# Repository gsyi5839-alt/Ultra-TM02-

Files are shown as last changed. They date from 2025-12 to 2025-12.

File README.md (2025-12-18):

# Ultra-TM02 超低温温度测量模块

## 📋 项目简介

Ultra-TM02是一款高精度超低温温度测量模块，专门用于二极管式温度探头的超低温测量，支持用户自定义探头分度表。

## 🎯 主要技术指标

| 参数 | 规格 |
|---|---|
| 温度测量范围 | 1.4K ~ 500K (-271.75℃ ~ 226.85℃) |
| 显示分辨率 | 0.001℃ |
| 最大允许误差 | 低温段 ±1℃，高温段 ±2℃ |
| ADC精度 | 24位 |
| 内部电流源精度 | ≤0.05% |
| 激励电流 | 10μA / 17μA 可选 |
| 输出形式 | 4-20mA（两线制） |
| 供电电压 | 24V DC |
| 显示屏 | 3.5寸LCD串口屏 |

## 📁 项目结构

```
Ultra-TM02/
├── Ultra_TM02/              # STM32固件源码
│   ├── App/                 # 应用层（温度测量、通讯、参数）
│   ├── Service/             # 服务层（ADC、DAC、LCD、USB）
│   ├── BSP/                 # 板级支持包（GPIO、SPI、UART、Flash）
│   └── Core/                # 主程序和HAL配置
├── TempDownloader/          # 上位机软件（Python/PyQt5）
│   ├── src/                 # 源代码
│   │   ├── ui/              # 用户界面
│   │   ├── protocol/        # 通讯协议
│   │   └── utils/           # 工具模块
│   └── resources/           # 资源文件
├── Gerber_PCB1/             # PCB Gerber文件
├── Schematics/              # 原理图
├── 软件开发/                 # 软件设计文档
├── 硬件设计/                 # 硬件设计文档
└── 配件采购/                 # 配件采购清单
```

## 🔧 硬件规格

### MCU
- **型号**: STM32F411RET6
- **内核**: ARM Cortex-M4
- **主频**: 100MHz
- **Flash**: 512KB
- **RAM**: 128KB

### 外设
- **SPI1**: ADC/DAC通讯 (12.5MHz)
- **USART6**: LCD串口屏通讯 (115200bps)
- **USB**: CDC虚拟串口
- **GPIO**: 片选、LED、DRDY等

## 💻 软件架构

### 固件分层架构
```
┌─────────────────────────────────────────┐
│              应用层 (App)                │
│  温度测量 | 数据处理 | 参数管理 | 通讯    │
├─────────────────────────────────────────┤
│             服务层 (Service)             │
│   ADC服务 | DAC服务 | LCD服务 | USB服务  │
├─────────────────────────────────────────┤
│              驱动层 (BSP)                │
│  SPI驱动 | UART驱动 | GPIO驱动 | Flash   │
├─────────────────────────────────────────┤
│             硬件层 (HAL)                 │
│           STM32 HAL / LL 库              │
└─────────────────────────────────────────┘
```

### 上位机软件
- **语言**: Python 3.x
- **GUI框架**: PyQt5
- **功能**: 设备连接、参数设置、数据采集、分度表下载

## 🚀 快速开始

### 固件编译
1. 安装 STM32CubeIDE
2. 打开 `Ultra_TM02/Ultra_TM02.ioc`
3. 点击 Project → Build All

### 上位机运行
```bash
cd TempDownloader
pip install -r requirements.txt
python main.py
```

## 📊 开发进度

| 模块 | 完成度 |
|---|---|
| 硬件原理图设计 | ✅ 100% |
| PCB设计+制作 | ✅ 100% |
| STM32固件开发 | ✅ 100% |
| 上位机软件开发 | ✅ 100% |
| 系统联调测试 | ⏳ 进行中 |

## 📄 文档

- [软件开发设计文档](软件开发/01_软件开发设计文档.md)
- [STM32工程配置指南](软件开发/02_STM32工程配置指南.md)
- [通讯协议详细设计](软件开发/03_通讯协议详细设计.md)
- [温度测量算法设计](软件开发/04_温度测量算法设计.md)
- [开发进度文档](软件开发/05_开发进度文档.md)
- [原理图设计文档](硬件设计/超低温温度测量模块_原理图设计文档.md)

## 📜 License

本项目仅供学习和研究使用。

## 📧 联系方式

如有问题，请提交 Issue。

---
*版本: V1.0*
*更新日期: 2025年12月18日*

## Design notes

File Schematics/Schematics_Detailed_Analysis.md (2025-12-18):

# 超低温温度测量模块 - 原理图详细分析文档

**项目名称：** 超低温温度测量模块
**主控芯片：** STM32F411RET6
**原理图版本：** V1.0
**设计单位：** 嘉立创EDA
**更新日期：** 2025-09-26
**图纸数量：** 4页（P1-P4）

---

## 📑 目录

1. [第一页：超低温温度测量模块体](#第一页超低温温度测量模块体-p1)
2. [第二页：STM32主控电路](#第二页stm32主控电路-p2)
3. [第三页：电源管理电路](#第三页电源管理电路-p3)
4. [第四页：DAC输出与隔离电路](#第四页dac输出与隔离电路-p4)

---

## 第一页：超低温温度测量模块体 (P1)

### 1.1 页面概览

**原理图标题：** Schematic6 - P1
**功能模块：** 超低温温度测量模块体
**更新日期：** 2025-09-26

### 1.2 主要电路模块

#### 1.2.1 ADC采集电路（左上区域）

**核心芯片：** 高精度ADC芯片（U71/U72）

**电路组成：**
```
ADC通道1：
- 输入滤波电容：C92, C93, C96, C97
- 参考电压电路
- SPI通讯接口：ADC1_CS, ADC_SCK, ADC_MOSI
- 模拟地：AGND
```

**功能说明：**
- 用于采集探头温度信号
- 高精度24位ADC转换
- SPI接口与MCU通讯
- 差分输入方式，抗干扰能力强

**关键元件：**
- 去耦电容：100nF（C92, C93）
- 滤波电容：10uF（C96, C97）
- 参考电压稳定电路

#### 1.2.2 DAC输出电路（中上区域）

**核心芯片：** 高精度DAC芯片

**电路组成：**
```
DAC通道：
- 数字接口：DAC1_CS, DAC_SCK, DAC_MOSI, DAC_LOAD
- 输出滤波电路
- 运算放大器
- 电压到电流转换电路
```

**功能说明：**
- 将数字信号转换为模拟电压
- 输出电压范围可调
- 通过运放进行缓冲和放大
- 为后级电流输出提供基准

**关键元件：**
- DAC芯片（高精度16位）
- 运算放大器（低噪声）
- 基准电压源

#### 1.2.3 V/I转换电路（右上区域）

**功能：** 电压到4-20mA电流转换

**电路组成：**
```
V/I转换电路：
- 运算放大器
- 精密取样电阻
- 功率晶体管
- 电流反馈电路
```

**输出规格：**
- 输出电流：4-20mA
- 负载能力：最大500Ω
- 精度：±0.1%
- 线性度：优于0.05%

**关键元件：**
- 高精度取样电阻：250Ω
- 运算放大器（低偏置）
- 功率晶体管

#### 1.2.4 隔离电源电路（左下区域）

**核心芯片：** DC-DC隔离模块

**电路组成：**
```
隔离电源：
- 输入：+24V
- 输出1：+5VD（数字隔离）
- 输出2：+5VA（模拟隔离）
- 反馈控制电路
```

**功能说明：**
- 实现数字地和模拟地隔离
- 防止地回路干扰
- 提高测量精度
- 保护后级电路

**关键元件：**
- DC-DC隔离模块
- 输入滤波电容
- 输出滤波电容

#### 1.2.5 信号调理电路（右下区域）

**功能：** 探头信号放大和滤波

**电路组成：**
```
信号调理：
- 前置放大器
- 低通滤波器
- 共模抑制电路
- 保护电路
```

**技术参数：**
- 增益：可调（1-1000倍）
- 带宽：DC-100Hz
- 共模抑制比：>100dB
- 输入阻抗：>1MΩ

---

## 第二页：STM32主控电路 (P2)

### 2.1 页面概览

**原理图标题：** Schematic6 - P2
**功能模块：** STM32主控电路
**更新日期：** 2025-09-26

### 2.2 核心芯片：STM32F411RET6 (U22)

**芯片规格：**
- 型号：STM32F411RET6
- 封装：LQFP-64
- 主频：100MHz
- Flash：512KB
- RAM：128KB
- 工作电压：3.3V

**引脚分配：**

#### 2.2.1 电源引脚

```
VDD引脚（3.3V）：
- VDD_1, VDD_2, VDD_3, VDD_4（多个VDD引脚）
- VDDA（模拟电源）
- VBAT（备份电源）

GND引脚：
- VSS_1, VSS_2, VSS_3, VSS_4（多个地引脚）
- VSSA（模拟地）
```

**去耦电容配置：**
- C58, C59, C60, C61, C62：100nF（靠近每个VDD引脚）
- C68：10uF（大容量去耦）
- C76：1uF（中频去耦）

#### 2.2.2 晶振电路

**主晶振 (OSC1)：**
```
型号：12MHz晶振
连接引脚：
- PH0-OSC_IN（引脚5）
- PH1-OSC_OUT（引脚6）

外围元件：
- C123：20pF（负载电容1）
- DGND
- 12MHz标识
```

**功能：**
- 提供系统时钟源
- PLL倍频到100MHz
- 高精度时钟基准

#### 2.2.3 复位电路

**复位方式：** 外部复位 + 内部复位

```
复位引脚：NRST（引脚7）
外围电路：
- 复位按钮
- 上拉电阻：10kΩ
- 滤波电容：100nF
```

#### 2.2.4 调试接口

**SWD调试接口 (H1)：**

```
引脚定义（P2254V-1x04P）：
1. 3V3      - 电源（红色）
2. DGND     - 地（黑色）
3. SWDIO    - 数据线（黄色）
4. JTCK-SWCLK - 时钟线（绿色）

连接芯片引脚：
- SWDIO  → PA13（引脚46）
- SWCLK  → PA14（引脚49）
```

**功能：**
- 程序下载
- 在线调试
- 固件升级
- 芯片擦除

#### 2.2.5 USB接口电路

**USB TypeC接口 (LCM2)：**

```
USB信号：
- USB_PA (USB D+ after filter)
- USB_NA (USB D- after filter)
- USB_P (USB D+ to MCU)
- USB_N (USB D- to MCU)

连接芯片引脚：
- USB_P → PA12（引脚45）
- USB_N → PA11（引脚44）

外围电路：
- ESD保护二极管
- USB滤波电感：L29, L25
- 差分阻抗匹配：R95, R96
- 上拉电阻：R97 (1.5kΩ to 3V3)
```

**ESD保护：**
- USB_PA/NA经过ESD保护二极管
- 连接到USB_P/N
- 保护MCU免受静电损伤

#### 2.2.6 LCD显示接口

**FPC软排线接口 (FPC1)：**

```
引脚定义（6芯FPC）：
1. DGND         - 地
2. NET_1        - 数据线1
3. NET_2        - 数据线2
4. +5VD         - 电源5V
5. DGND（屏蔽）  - 地屏蔽层
6. DGND（屏蔽）  - 地屏蔽层

LCD通讯接口：
- IO_USART6_RX  → LCD数据接收
- IO_USART6_TX  → LCD数据发送
- 串口通讯，波特率可配置
```

#### 2.2.7 SPI通讯引脚

**SPI1接口（用于DAC/ADC）：**

```
DAC1控制：
- DAC1_CS    → 片选信号
- DAC1_SCK   → 时钟信号
- DAC1_MOSI  → 数据输出
- IO_DAC1_CS → 光耦隔离后片选

DAC2控制：
- DAC2_CS    → 片选信号
- DAC2_SCK   → 时钟信号
- DAC2_MOSI  → 数据输出
- DAC2_LOAD  → 加载信号
- IO_DAC2_CS → 光耦隔离后片选

ADC1控制：
- ADC1_CS    → 片选信号
- IO_ADC1_CS → 光耦隔离后片选
```

**光耦隔离说明：**
- 数字信号通过光耦隔离
- 实现数字地(DGND)和模拟地(AGND)隔离
- 防止数字噪声干扰模拟测量

#### 2.2.8 GPIO分配

**主要GPIO功能：**

```
PORT A：
- PA0-PA7：ADC输入/通用IO
- PA8-PA10：通用IO
- PA11-PA12：USB通讯
- PA13-PA14：SWD调试
- PA15：通用IO

PORT B：
- PB0-PB15：通用IO/SPI/I2C/定时器

PORT C：
- PC0-PC15：通用IO/ADC输入

PORT D：
- PD0-PD15：通用IO

PORT E：
- PE0-PE15：通用IO

PORT H：
- PH0-PH1：晶振
```

#### 2.2.9 电源去耦

**去耦电容布局：**

```
顶层去耦电容（靠近VDD引脚）：
- C58：100nF（VDD_1附近）
- C59：100nF（VDD_2附近）
- C60：100nF（VDD_3附近）
- C61：100nF（VDD_4附近）
- C62：100nF（VDDA附近）

底层去耦电容：
- C63：100nF（VSS附近）
- C76：1uF（大电容）
- C68：10uF（更大电容）
```

**去耦策略：**
- 100nF高频去耦（靠近每个VDD）
- 1uF中频去耦
- 10uF低频去耦
- 多点并联降低ESR和ESL

#### 2.2.10 LED指示灯

**LED1电路：**

```
型号：KT-0805G（绿色LED）
连接：
- 正极 → 3V3
- 负极 → R120 → MCU GPIO

电流限制电阻：
- R120：1kΩ（限流约2-3mA）

功能：
- 电源指示
- 运行状态指示
- 通讯状态指示（可编程）
```

### 2.3 电源供电

**3V3电源网络：**

```
输入：+5VD（数字5V）
稳压器：AMS1117-3.3（可能）
输出：3V3（MCU供电）

滤波电容：
- 输入：C35（10uF）
- 输出：C58-C62（100nF × 5）
        C68（10uF）
```

---

## 第三页：电源管理电路 (P3)

### 3.1 页面概览

**原理图标题：** Schematic6 - P3
**功能模块：** 电源管理电路
**更新日期：** 2025-09-26

### 3.2 主电源输入

#### 3.2.1 24V输入电路 (CN14)

**接线端子：**
```
型号：XH-2A（2位端子）
引脚定义：
1. IX1K_1X  - 正极（24V输入）
2. 电源地   - 负极（DGND）

输入保护：
- 反接保护二极管
- 过压保护
- 输入滤波电容
```

**24V分配：**
```
+24V →
  ├─ DC-DC转换器1 (U23) → +5VD, +9VD
  ├─ DC-DC转换器2 (U63) → +9VA
  └─ DC-DC转换器3 (U67) → +9VX
```

### 3.3 隔离DC-DC电源模块

#### 3.3.1 数字电源模块 (U23)

**型号：** DC-DC隔离模块（+24V → +5V/+9V）

```
输入引脚：
- VIN：+24V（引脚1,2）
- GND：DGND（引脚3,4）

输出：
- +5VD：5V数字电源
- +9VD：9V数字电源（可选）

外围电路：
- 输入电感：L30 (4.7uH)
- 输入电容：C77 (10uF)
- 输出电容：C78, C79 (100nF + 10uF)
```

**功能：**
- 为STM32和数字电路供电
- 隔离保护
- 纹波抑制

#### 3.3.2 模拟电源模块1 (U63)

**型号：** DC-DC隔离模块（+24V → +9VA）

```
输入：
- +24V经过L31电感滤波
- DGND

输出：
- +9VA：9V模拟电源
- AGND：模拟地

外围电路：
- 输入电感：L31 (4.7uH)
- 输入电容：C80 (10uF)
- 输出电容：C81, C82 (100nF + 10uF)
```

**功能：**
- 为ADC/DAC模拟电路供电
- 低纹波输出（<10mV）
- 与数字电源隔离

#### 3.3.3 隔离电源模块2 (U67)

**型号：** DC-DC隔离模块（+24V → +9VX）

```
输入：
- +24V经过L32电感滤波
- DGND

输出：
- +9VX：9V隔离电源
- GNDX：隔离地

外围电路：
- 输入电感：L32 (4.7uH)
- 输入电容：C86 (10uF)
- 输出电容：C87, C88 (100nF + 10uF)
```

**功能：**
- 为4-20mA输出电路供电
- 完全隔离（与DGND和AGND都隔离）
- 防止地回路

### 3.4 线性稳压器

#### 3.4.1 +5VD → +3.3V稳压 (U62)

**稳压器：** AMS1117-3.3 或 LD1117S33TR

```
输入：+5VD
输出：3V3（3.3V）
最大电流：800mA

外围电路：
- 输入电容：C121 (10uF)
- 输出电容：C122, C123 (10uF + 100nF)
- 热保护：内置
```

**负载分配：**
- STM32主控：~100mA
- 外围逻辑电路：~50mA
- 总负载：<200mA

#### 3.4.2 +9VA → +6.5VA稳压 (U65)

**稳压器：** LD1117S50TR（5V稳压器 + 分压）

```
输入：+9VA
输出：6.5VA（用于基准电压）

外围电路：
- 输入电容：C80 (10uF)
- 输出电容：C83 (100nF)
- 分压电阻：R130 (精密电阻)
```

**功能：**
- 提供ADC/DAC基准电压
- 高稳定度（±0.01%）
- 低温漂（<10ppm/℃）

#### 3.4.3 +9VX → +6.5VX稳压 (U69)

**稳压器：** LD1117S50TR（5V稳压器 + 分压）

```
输入：+9VX
输出：6.5VX（用于隔离电路基准）

外围电路：
- 输入电容：C86 (10uF)
- 输出电容：C89 (100nF)
- 分压电阻：R133 (精密电阻)
```

**功能：**
- 为隔离输出电路提供基准
- 与主电路完全隔离

#### 3.4.4 +9VA → +5VA稳压 (U85)

**稳压器：** LM78L05（5V线性稳压器）

```
输入：+9VA
输出：5VA（5V模拟电源）

外围电路：
- 输入电容：C125 (10uF)
- 输出电容：C126 (100uF)
```

**负载：**
- 光耦隔离器
- 运算放大器
- 模拟开关

#### 3.4.5 +9VX → +5VX稳压 (U86)

**稳压器：** LM78L05（5V线性稳压器）

```
输入：+9VX
输出：5VX（5V隔离电源）

外围电路：
- 输入电容：C127 (10uF)
- 输出电容：C128 (100uF)
```

**负载：**
- 隔离光耦
- 4-20mA输出电路

### 3.5 电源测试点

**测试点分布：**

```
TP2：+5VD  - 数字5V测试点
TP3：+3V3  - 3.3V测试点
TP4：+6.5VA - 模拟基准电压测试点
TP5：+6.5VX - 隔离基准电压测试点
TP6：DGND  - 数字地测试点
TP7：AGND  - 模拟地测试点
TP8：GNDX  - 隔离地测试点
```

**用途：**
- 电源电压检测
- 故障排查
- 性能测试
- 校准验证

### 3.6 电源指示

**电源指示电路：**

```
+5VD指示：
- LED：可选
- 限流电阻：1kΩ
- 颜色：绿色

+5VA指示：
- LED：可选
- 限流电阻：1kΩ
- 颜色：黄色

+5VX指示：
- LED：可选
- 限流电阻：1kΩ
- 颜色：红色
```

### 3.7 电源时序

**上电时序：**

```
1. +24V输入（0ms）
2. DC-DC启动（1-5ms）
   - U23：+5VD, +9VD
   - U63：+9VA
   - U67：+9VX
3. 线性稳压器启动（6-10ms）
   - U62：3V3
   - U65：6.5VA
   - U69：6.5VX
   - U85：5VA
   - U86：5VX
4. MCU复位释放（>100ms）
5. 系统正常工作
```

**掉电时序：**

```
1. 检测+24V掉电
2. MCU进入掉电保护
3. 保存关键数据
4. 关闭输出
5. 电源下降
```

---

## 第四页：DAC输出与隔离电路 (P4)

### 4.1 页面概览

**原理图标题：** Schematic6 - P4
**功能模块：** DAC输出与隔离电路
**更新日期：** 2025-09-26

### 4.2 DAC2通道与4-20mA输出电路

#### 4.2.1 光耦隔离电路（左上区域）

**隔离芯片：** 高速光耦（可能是6N137或HCPL-2630）

```
输入侧（数字侧，DGND）：
- 信号输入：
  * DAC2_CS   → 光耦1输入
  * DAC2_SCK  → 光耦2输入
  * DAC2_MOSI → 光耦3输入
  * DAC2_LOAD → 光耦4输入
- 电源：3V3
- 地：DGND
- 限流电阻：330Ω

输出侧（隔离侧，GNDX）：
- 信号输出：
  * DAC2_CS_隔离
  * DAC2_SCK_隔离
  * DAC2_MOSI_隔离
  * DAC2_LOAD_隔离
- 电源：5VX
- 地：GNDX
- 上拉电阻：10kΩ
```

**功能：**
- 实现数字信号隔离
- 隔离电压：>2500V
- 传输速率：>1Mbps
- 防止地回路干扰

#### 4.2.2 DAC芯片电路（U79）

**DAC芯片型号：** 可能是DAC8560、DAC8563或AD5541

```
引脚连接：
输入接口（SPI）：
- CS#：片选（来自光耦隔离）
- SCK：时钟（来自光耦隔离）
- SDI：数据输入（来自光耦隔离）
- LDAC#：加载信号（来自光耦隔离）

电源引脚：
- VDD：5VX（隔离5V电源）
- GND：GNDX（隔离地）

输出引脚：
- VOUT：电压输出
- VREF：基准电压输入

外围电路：
- C118：100nF（VDD去耦）
- 基准电压：2.5V或5V
```

**DAC规格：**
- 分辨率：16位
- 建立时间：<10μs
- 输出范围：0-5V或0-10V
- 线性度：±1LSB

#### 4.2.3 V/I转换电路（中间区域）

**核心电路：** 精密V/I转换器

```
电路组成：
- 运算放大器（U79_内部或外部）
- 精密取样电阻：R150 (250Ω, 0.1%)
- 功率晶体管：Q2（可能是2N2219或BC547）
- 反馈电路

工作原理：
1. DAC输出0-5V电压
2. 运放将电压转换为0-20mA电流
3. 取样电阻检测电流
4. 反馈到运放负输入
5. 形成闭环控制

转换公式：
I_out = V_DAC / R_sample × K
其中 K 为放大系数
```

**输出电路：**

```
Q2晶体管电路：
- 基极：运放输出
- 发射极：经R150到GNDX
- 集电极：连接到4-20mA输出

负载能力：
- 最大负载：500Ω
- 工作电压：24V
- 功耗：<1W
```

#### 4.2.4 4-20mA输出保护电路

**保护措施：**

```
1. 过流保护：
   - 限流电阻
   - 保护二极管D7, D8

2. ESD保护：
   - TVS管：保护输出端
   - 箝位二极管

3. 反接保护：
   - 串联二极管D5, D6
   - 防止接线反接损坏

4. 过压保护：
   - 稳压二极管
   - 限制最高电压
```

**输出接口：**

```
CN12：4-20mA输出1
- 引脚1：+24V NC（未连接，标记用）
- 引脚2：GNDX_NC（未连接，标记用）
- 实际输出：ZX3位2-54-4PZ2（4芯接口）

CN13：测试端口
- 引脚1：+24V NC
- 引脚2：测试地_NC
- 实际输出：ZX3位54-2P2Z（2芯接口）

输出电路连接：
- 正极：连接到负载正端
- 负极：通过Q2到GNDX
- 回路：+24V → 负载 → 4-20mA输出 → GNDX
```

#### 4.2.5 测试点电路

**TP10测试点：**

```
位置：4-20mA输出线路上
功能：
- 测量输出电流
- 校准验证
- 故障诊断

测试方法：
- 串联电流表
- 测量电压降（跨R150）
- 计算电流值
```

### 4.3 USB接口电路（下方区域）

#### 4.3.1 USB差分线处理

**USB信号链路：**

```
信号流向：
MCU → USB_PA/USB_NA →
      ESD保护 →
      差分滤波 →
      USB_P/USB_N →
      TypeC接口

差分线处理：
- 阻抗控制：90Ω ±10%
- 等长设计：误差<5mil
- 差分对布线
```

**滤波电路：**

```
USB_PA → R97 → L17U2 → ISB_P
USB_NA → R96 → (共模电感) → ISB_N

滤波元件：
- R97, R96：22Ω（串联阻抗匹配）
- L17U2：共模电感（抑制共模噪声）
- 频率响应：DC-500MHz
```

#### 4.3.2 USB ESD保护

**保护器件：**

```
双向TVS管或ESD保护阵列：
- USB_PA/NA 到地的ESD保护
- 箝位电压：<5.5V
- 峰值功率：>200W
- 电容：<5pF（不影响高速信号）

保护等级：
- IEC 61000-4-2：±8kV接触放电
- IEC 61000-4-4：±2kV快速脉冲
```

#### 4.3.3 USB上拉电阻

**USB识别电路：**

```
R98/R99电阻：
- 阻值：1.5kΩ
- 连接：USB D+ 到 3V3
- 功能：
  * 全速USB设备识别
  * 通知主机设备连接
  * 符合USB2.0规范

工作机制：
1. 设备未连接：D+为低电平
2. 设备连接：D+被上拉到3.3V
3. 主机检测到D+高电平
4. 主机开始枚举设备
```

#### 4.3.4 USB接口定义 (U88)

**TypeC接口：** ZX3位54-4PZ2

```
引脚定义：
1. USB_N   - USB D- 数据线
2. USB_P   - USB D+ 数据线
3. GNDI    - USB地
4. 屏蔽层  - 连接外壳

USB协议：
- USB 2.0 Full Speed（12Mbps）
- CDC类设备（虚拟串口）
- HID类设备（可选）
```

### 4.4 IO隔离电路 (U83)

**光耦隔离芯片：** 8通道光耦阵列

```
输入侧（数字侧）：
- 电源：3V3
- 地：DGND
- 输入信号：
  * IO_DAC2_CS
  * IO_DAC2_MOSI
  * IO_DAC2_SCK
  * IO_DAC2_LOAD
  * （其他控制信号）

输出侧（隔离侧）：
- 电源：5VX
- 地：GNDX
- 输出信号：
  * DAC2_CS（隔离后）
  * DAC2_MOSI（隔离后）
  * DAC2_SCK（隔离后）
  * DAC2_LOAD（隔离后）

电路参数：
- 正向电流：5-10mA
- 电流传输比：50-200%
- 隔离电压：2500V
- 传输延迟：<10μs
```

**功能：**
- 数字信号隔离
- 保护MCU不受高压损坏
- 防止地回路噪声
- 提高系统可靠性

### 4.5 去耦电容布局

**电源去耦：**

```
3V3去耦：
- C120：100nF（高频）
- 靠近光耦和逻辑芯片

5VX去耦：
- C119：100nF（高频）
- C127, C128：10uF（中低频）
- 靠近DAC和V/I转换电路

GNDI去耦：
- C69：100uF（大电容）
- USB接口附近
- 抑制USB通讯噪声
```

---

## 📊 系统级分析

### 5.1 电源架构总览

```
+24V输入
  │
  ├─→ DC-DC(U23) ─→ +5VD ─→ LDO(U62) ─→ 3V3 (STM32, 数字电路)
  │                    │
  │                    └─→ +9VD (备用)
  │
  ├─→ DC-DC(U63) ─→ +9VA ─→ LDO(U65) ─→ 6.5VA (ADC/DAC基准)
  │                    │
  │                    └─→ LDO(U85) ─→ 5VA (模拟电路)
  │
  └─→ DC-DC(U67) ─→ +9VX ─→ LDO(U69) ─→ 6.5VX (隔离基准)
                       │
                       └─→ LDO(U86) ─→ 5VX (隔离电路)

地系统：
- DGND：数字地（STM32, USB, LCD）
- AGND：模拟地（ADC, DAC, 运放）
- GNDX：隔离地（4-20mA输出）
- GNDI：USB接口地
```

### 5.2 信号隔离架构

```
数字侧（DGND）          光耦隔离         隔离侧（GNDX）
─────────────────    ─────────────    ─────────────────
STM32 GPIO                              DAC2芯片
  ├─ DAC2_CS      →  光耦1  →  DAC2_CS_ISO
  ├─ DAC2_SCK     →  光耦2  →  DAC2_SCK_ISO
  ├─ DAC2_MOSI    →  光耦3  →  DAC2_MOSI_ISO
  └─ DAC2_LOAD    →  光耦4  →  DAC2_LOAD_ISO

同样方式隔离：
- DAC1控制信号
- ADC1控制信号
- 其他IO信号

隔离等级：
- 电气隔离：2500V AC
- 传输速率：1-10Mbps
- 传输延迟：<10μs
```

### 5.3 测量信号链路

```
探头信号 → 前置放大 → 滤波 → ADC采集 → STM32处理
                                          │
                                          ↓
                                   温度值计算
                                          │
                                          ↓
         LCD显示 ←──────────────────── 数据处理
         USB上传 ←──────────────────── 数据处理
         4-20mA输出 ←─── DAC转换 ←─── 数据处理
```

### 5.4 通讯接口汇总

| 接口类型 | 接口名称 | 协议/标准 | 波特率/速度 | 用途 |
|---|---|---|---|---|
| **USB** | TypeC | USB 2.0 Full Speed | 12Mbps | 上位机通讯、固件升级 |
| **SWD** | H1调试口 | ARM SWD | - | 程序下载、调试 |
| **UART** | LCD接口 | USART6 | 115200bps | LCD显示屏通讯 |
| **SPI** | DAC1 | SPI1 | 1-10MHz | DAC1控制 |
| **SPI** | DAC2 | SPI1（隔离） | 1-10MHz | DAC2控制（隔离） |
| **SPI** | ADC1 | SPI1 | 1-10MHz | ADC1数据读取 |
| **模拟输出** | CN12/CN13 | 4-20mA | - | 电流输出 |

### 5.5 关键元器件清单

#### 5.5.1 主控与逻辑芯片

| 器件编号 | 型号 | 封装 | 数量 | 功能 |
|---|---|---|---|---|
| U22 | STM32F411RET6 | LQFP-64 | 1 | 主控MCU |
| U71 | DAC控制器 | SOP-16 | 1 | DAC通道1控制 |
| U72 | ADC运放 | SOP-8 | 1 | ADC信号调理 |
| U76 | ADC芯片 | SOP-10 | 1 | 温度信号采集 |
| U79 | DAC8560 | SOP-8 | 1 | DAC通道2（4-20mA） |
| U83 | 光耦阵列 | SOP-16 | 1 | IO信号隔离 |

#### 5.5.2 电源芯片

| 器件编号 | 型号 | 输入 | 输出 | 功能 |
|---|---|---|---|---|
| U23 | DC-DC隔离模块 | 24V | 5VD, 9VD | 数字电源 |
| U63 | DC-DC隔离模块 | 24V | 9VA | 模拟电源 |
| U67 | DC-DC隔离模块 | 24V | 9VX | 隔离电源 |
| U62 | AMS1117-3.3 | 5VD | 3.3V | MCU电源 |
| U65 | LD1117S50 | 9VA | 6.5VA | 模拟基准 |
| U69 | LD1117S50 | 9VX | 6.5VX | 隔离基准 |
| U85 | LM78L05 | 9VA | 5VA | 模拟5V |
| U86 | LM78L05 | 9VX | 5VX | 隔离5V |

#### 5.5.3 连接器

| 器件编号 | 型号 | 引脚数 | 功能 |
|---|---|---|---|
| CN14 | XH-2A | 2 | 24V电源输入 |
| CN12 | ZX3位2-54-4PZ2 | 4 | 4-20mA输出1 |
| CN13 | ZX3位54-2P2Z | 2 | 4-20mA输出2/测试 |
| FPC1 | FPC-6P | 6 | LCD屏幕接口 |
| LCM2 | TypeC | 4 | USB通讯 |
| H1 | P2254V-1x04P | 4 | SWD调试接口 |
| P1 | 排针8P | 8 | 扩展IO接口 |

#### 5.5.4 关键无源元件

| 类型 | 规格 | 精度 | 用途 |
|---|---|---|---|
| 电阻 | 250Ω | 0.1% | 4-20mA取样电阻 |
| 电阻 | 1.5kΩ | 1% | USB上拉电阻 |
| 电阻 | 10kΩ | 1% | 复位上拉 |
| 电容 | 100nF | 10% | 高频去耦 |
| 电容 | 10uF | 10% | 中频去耦 |
| 电容 | 100uF | 20% | 低频去耦 |
| 电感 | 4.7uH | 10% | 电源滤波 |
| 晶振 | 12MHz | 20ppm | 系统时钟 |

---

## 🔧 设计特点与技术亮点

### 6.1 多电源隔离设计

**隔离层级：**
1. **数字层（DGND）**
   - STM32主控
   - USB接口
   - LCD显示
   - 调试接口

2. **模拟层（AGND）**
   - ADC采集
   - DAC输出（部分）
   - 高精度基准

3. **隔离层（GNDX）**
   - 4-20mA输出
   - 光耦隔离侧
   - 外部负载

**优势：**
- 消除地回路干扰
- 提高测量精度
- 保护内部电路
- 符合工业标准

### 6.2 精密模拟设计

**关键技术：**
1. **低噪声电源**
   - 多级滤波
   - 独立稳压
   - 低纹波输出

2. **高精度基准**
   - 6.5V精密基准
   - 温度补偿
   - 低温漂设计

3. **差分输入**
   - 共模抑制
   - 抗干扰能力强
   - 适合长线传输

4. **多点去耦**
   - 100nF高频去耦
   - 10uF中频去耦
   - 100uF低频储能

### 6.3 工业级4-20mA输出

**设计特点：**
1. **完全隔离**
   - 光耦信号隔离
   - DC-DC电源隔离
   - 隔离电压>2500V

2. **高精度输出**
   - 16位DAC分辨率
   - 精密V/I转换
   - 0.1%精度

3. **保护完善**
   - 过流保护
   - 过压保护
   - 反接保护
   - ESD保护

4. **负载能力**
   - 最大500Ω负载
   - 两线制输出
   - 24V供电兼容

### 6.4 USB通讯接口

**技术特点：**
1. **TypeC接口**
   - 正反插
   - USB 2.0标准
   - Full Speed（12Mbps）

2. **ESD保护**
   - 双向TVS管
   - ±8kV防护
   - 低电容设计

3. **信号完整性**
   - 差分阻抗90Ω
   - 等长布线
   - 滤波电感

4. **即插即用**
   - CDC虚拟串口
   - 免驱动（Win10+）
   - 固件升级支持

### 6.5 调试与测试

**调试接口：**
- SWD调试口（H1）
- 在线下载
- 单步调试
- 断点功能

**测试点：**
- 11个电源测试点
- 关键信号测试点
- 飞针测试支持
- 100%网络覆盖

**LED指示：**
- 电源指示
- 运行状态
- 通讯状态
- 故障指示

---

## 📐 PCB设计建议

### 7.1 布局建议

**分区布局：**
```
┌─────────────────────────────────┐
│  电源区        │  数字区          │
│  (DC-DC,LDO)  │  (STM32,USB)    │
├───────────────┼─────────────────┤
│  模拟区        │  隔离输出区      │
│  (ADC,DAC)    │  (4-20mA)       │
└─────────────────────────────────┘
```

**布局原则：**
1. 电源区靠近输入端
2. 数字区远离模拟区
3. 隔离区完全分离
4. 高速信号短而直

### 7.2 电源平面

**地平面分割：**
```
┌─────────────────────────────────┐
│  DGND区域    │  AGND区域         │
│              │                  │
│              │                  │
├──────────────┴──────────────────┤
│  单点接地                         │
└─────────────────────────────────┘
│
└─ GNDX区域（完全隔离）
```

**要点：**
- DGND和AGND单点接地
- GNDX完全隔离，不与主地相连
- 避免地环路
- 大面积铺铜

### 7.3 走线要求

**关键信号：**
1. **USB差分对**
   - 阻抗：90Ω±10%
   - 等长：误差<5mil
   - 最小弯曲半径：>10mil

2. **SPI信号**
   - 短而粗
   - 远离高频源
   - 串联阻抗22Ω

3. **模拟信号**
   - 屏蔽走线
   - 远离数字信号
   - 差分布线

4. **电源走线**
   - 粗走线（20mil+）
   - 去耦电容靠近IC
   - 星型布线

### 7.4 EMC设计

**抗干扰措施：**
1. **滤波**
   - 电源输入滤波
   - 信号线滤波
   - 共模电感

2. **屏蔽**
   - 地平面屏蔽
   - 关键信号屏蔽
   - 金属外壳接地

3. **隔离**
   - 光耦隔离
   - 电源隔离
   - 槽孔隔离

4. **保护**
   - TVS管
   - ESD保护
   - 过压保护

---

## ⚙️ 关键参数总结

### 8.1 电源规格

| 电源 | 电压 | 最大电流 | 纹波 | 用途 |
|---|---|---|---|---|
| +24V | 24V | 500mA | <100mV | 系统输入 |
| +5VD | 5V | 300mA | <50mV | 数字电源 |
| 3V3 | 3.3V | 200mA | <20mV | MCU电源 |
| +9VA | 9V | 100mA | <10mV | 模拟电源 |
| 5VA | 5V | 50mA | <5mV | 模拟5V |
| 6.5VA | 6.5V | 20mA | <1mV | 模拟基准 |
| +9VX | 9V | 100mA | <10mV | 隔离电源 |
| 5VX | 5V | 50mA | <5mV | 隔离5V |
| 6.5VX | 6.5V | 20mA | <1mV | 隔离基准 |

### 8.2 测量规格

| 参数 | 规格 | 备注 |
|---|---|---|
| 测量范围 | 1.4K~500K | -271.75℃~226.85℃ |
| 分辨率 | 0.001℃ | 1mK |
| 精度 | ±1℃（低温）<br>±2℃（高温） | 探头相关 |
| ADC位数 | 24位 | 高精度ADC |
| 采样率 | 1次/秒 | 最大 |
| 探头类型 | 二极管式 | 4线差分 |
| 激励电流 | 10uA/17uA | 可选 |

### 8.3 输出规格

| 参数 | 规格 | 备注 |
|---|---|---|
| 输出类型 | 4-20mA | 两线制 |
| 输出精度 | ±0.1% | 含线性度 |
| 负载能力 | 0-500Ω | 24V供电 |
| 隔离电压 | >2500V | 光耦+DC-DC |
| 响应时间 | <100ms | 建立时间 |
| 输出通道 | 2路 | 独立隔离 |

### 8.4 通讯规格

| 接口 | 规格 | 说明 |
|---|---|---|
| USB | 2.0 Full Speed | 12Mbps, CDC类 |
| UART | 115200bps | LCD通讯 |
| SPI | 1-10MHz | DAC/ADC控制 |
| SWD | - | 调试下载 |

---

## 🛠️ 设计审查要点

### 9.1 电源审查

- [ ] 所有电源去耦电容是否靠近IC
- [ ] 电源走线是否足够粗（≥20mil）
- [ ] 是否有电源指示LED
- [ ] 电源时序是否合理
- [ ] 隔离电源是否真正隔离
- [ ] 单点接地是否正确实现

### 9.2 信号完整性审查

- [ ] USB差分对是否等长
- [ ] USB差分对阻抗是否90Ω
- [ ] SPI信号是否有串联阻抗
- [ ] 模拟信号是否远离数字信号
- [ ] 时钟信号是否短而直
- [ ] 是否有信号回流路径

### 9.3 EMC审查

- [ ] 输入端是否有滤波
- [ ] 是否有ESD保护
- [ ] 是否有过压保护
- [ ] 地平面是否完整
- [ ] 是否有适当的隔离槽
- [ ] 高速信号是否有屏蔽

### 9.4 可制造性审查

- [ ] 最小线宽是否≥6mil
- [ ] 最小间距是否≥6mil
- [ ] 最小孔径是否≥0.3mm
- [ ] BGA下方是否有过孔
- [ ] SMD焊盘是否符合封装要求
- [ ] 是否有定位孔和安装孔

### 9.5 可测试性审查

- [ ] 是否有足够的测试点
- [ ] 测试点是否标识清晰
- [ ] 是否支持飞针测试
- [ ] 是否有调试接口
- [ ] 是否有LED指示
- [ ] 关键信号是否可测

---

## 📚 参考资料

### 10.1 芯片数据手册

1. **STM32F411RET6** - STMicroelectronics
   - 主控MCU数据手册
   - 参考手册RM0383

2. **AMS1117-3.3** - Advanced Monolithic Systems
   - 3.3V LDO稳压器

3. **LD1117S50TR** - STMicroelectronics
   - 5V LDO稳压器

4. **6N137** - Vishay或Fairchild
   - 高速光耦

5. **DAC8560** - Texas Instruments
   - 16位高精度DAC

### 10.2 设计标准

1. **USB 2.0规范**
   - USB-IF官方标准

2. **4-20mA工业标准**
   - IEC 60770
   - HART通讯协议

3. **EMC标准**
   - IEC 61000-4-2（ESD）
   - IEC 61000-4-4（EFT）

4. **PCB设计标准**
   - IPC-2221（PCB设计通用标准）
   - IPC-7351（SMT焊盘设计）

### 10.3 应用笔记

1. **STM32 USB应用笔记**
   - AN4879：USB硬件和PCB设计指南

2. **ADC/DAC应用笔记**
   - AN1384：高精度ADC设计
   - AN5429：DAC应用设计

3. **电源设计指南**
   - SLVA664：LDO稳压器PCB布局
   - AN-1148：开关电源布局

---

## 📝 版本修订记录

| 版本 | 日期 | 修订内容 | 修订人 |
|---|---|---|---|
| V1.0 | 2025-09-26 | 初始版本 | 设计团队 |

---

## 🔐 文档说明

**文档性质：** 技术分析文档
**保密级别：** 内部使用
**适用范围：** 超低温温度测量模块项目
**编制单位：** 嘉立创EDA / 测量仪器开发组

---

**文档完整性说明：**
本文档基于4页原理图（P1-P4）进行详细分析，涵盖了电路的所有主要功能模块、关键元器件、设计参数和技术特点。文档可作为PCB设计、电路调试、故障排查和技术培训的参考资料。

---

*本文档为原理图详细分析，包含完整的电路描述、元器件清单、技术参数和设计建议，供工程技术人员参考使用。*

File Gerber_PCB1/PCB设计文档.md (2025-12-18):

# 超低温温度测量模块 - PCB设计文档

## 文档信息

| 项目 | 内容 |
|---|---|
| PCB名称 | PCB1 |
| 设计软件 | EasyEDA Pro v2.2.42.2 |
| Gerber版本 | Generator version 0.3 |
| 生成日期 | 2025-09-26 15:24:21 |
| 尺寸单位 | 毫米 (mm) |

---

## 1. PCB基本规格

### 1.1 板卡尺寸

| 参数 | 规格 |
|---|---|
| 长度 | 99.0 mm |
| 宽度 | 64.0 mm |
| 面积 | 6336 mm² |
| 形状 | 矩形 |

### 1.2 层叠结构（4层板）

```
┌─────────────────────────────────┐
│   Layer 1 - TopLayer (GTL)     │ ← 顶层信号走线
├─────────────────────────────────┤
│   Layer 2 - InnerLayer1 (G1)   │ ← 内层1（地平面）
├─────────────────────────────────┤
│   Layer 3 - InnerLayer2 (G2)   │ ← 内层2（电源平面）
├─────────────────────────────────┤
│   Layer 4 - BottomLayer (GBL)  │ ← 底层信号走线
└─────────────────────────────────┘
```

### 1.3 层功能说明

| 层号 | 文件名 | 功能 | 说明 |
|---|---|---|---|
| L1 | Gerber_TopLayer.GTL | 信号层 | 顶层元器件和走线 |
| L2 | Gerber_InnerLayer1.G1 | 平面层 | GND地平面 |
| L3 | Gerber_InnerLayer2.G2 | 平面层 | 电源平面 |
| L4 | Gerber_BottomLayer.GBL | 信号层 | 底层元器件和走线 |

---

## 2. Gerber文件清单

### 2.1 铜层文件

| 文件名 | 扩展名 | 层类型 | 描述 |
|---|---|---|---|
| Gerber_TopLayer | .GTL | 顶层铜箔 | 顶层走线和焊盘 |
| Gerber_InnerLayer1 | .G1 | 内层1铜箔 | 内层1地平面 |
| Gerber_InnerLayer2 | .G2 | 内层2铜箔 | 内层2电源平面 |
| Gerber_BottomLayer | .GBL | 底层铜箔 | 底层走线和焊盘 |

### 2.2 阻焊层文件

| 文件名 | 扩展名 | 描述 |
|---|---|---|
| Gerber_TopSolderMaskLayer | .GTS | 顶层阻焊 |
| Gerber_BottomSolderMaskLayer | .GBS | 底层阻焊 |

### 2.3 锡膏层文件

| 文件名 | 扩展名 | 描述 |
|---|---|---|
| Gerber_TopPasteMaskLayer | .GTP | 顶层锡膏开窗 |
| Gerber_BottomPasteMaskLayer | .GBP | 底层锡膏开窗 |

### 2.4 丝印层文件

| 文件名 | 扩展名 | 描述 |
|---|---|---|
| Gerber_TopSilkscreenLayer | .GTO | 顶层丝印 |
| Gerber_BottomSilkscreenLayer | .GBO | 底层丝印 |

### 2.5 其他文件

| 文件名 | 扩展名 | 描述 |
|---|---|---|
| Gerber_BoardOutlineLayer | .GKO | 板框外形 |
| Gerber_DocumentLayer | .GDL | 文档图层 |
| Gerber_DrillDrawingLayer | .GDD | 钻孔标注图 |

---

## 3. 钻孔规格

### 3.1 通孔钻孔 (Drill_PTH_Through.DRL)

| 刀具号 | 孔径 (mm) | 类型 | 用途 |
|---|---|---|---|
| T01 | 0.3048 | 通孔 | 小过孔 |
| T02 | 0.3050 | 通孔 | 小过孔 |
| T03 | 0.3050 | 通孔 | 小过孔 |
| T04 | 0.7000 | 通孔 | 标准过孔 |
| T05 | 0.7620 | 通孔 | 标准过孔 |
| T06 | 1.0000 | 通孔 | 插件孔 |
| T07 | 1.1000 | 通孔 | 插件孔 |
| T08 | 1.2000 | 通孔 | 连接器孔 |

### 3.2 过孔钻孔 (Drill_PTH_Through_Via.DRL)

| 刀具号 | 孔径 (mm) | 数量（约） | 用途 |
|---|---|---|---|
| T01 | 0.3048 | ~120 | 信号过孔 |
| T02 | 0.3050 | ~12 | 信号过孔 |
| T03 | 0.3050 | ~7 | 信号过孔 |

### 3.3 钻孔统计

| 类型 | 最小孔径 | 最大孔径 | 数量（约） |
|---|---|---|---|
| 过孔 | 0.3048mm | 0.3050mm | ~139 |
| 插件孔 | 0.7000mm | 1.2000mm | ~66 |
| **总计** | - | - | **~205** |

---

## 4. 元器件清单

### 4.1 IC芯片

| 位号 | 型号/功能 | 层 | 坐标X (mil) | 坐标Y (mil) |
|---|---|---|---|---|
| U22 | STM32主控 | T | 1745 | -1255 |
| U23 | DC-DC | T | 2066.92 | -296.51 |
| U62 | 稳压器 | T | 2015 | -640 |
| U63 | DC-DC隔离 | T | 2813.50 | -631.63 |
| U64 | - | T | 2458.50 | -411.63 |
| U65 | 稳压器 | T | 3395 | -530 |
| U67 | DC-DC隔离 | T | 695 | -345 |
| U68 | - | T | 1165 | -275 |
| U69 | 稳压器 | T | 645 | -840 |
| U71 | ADC/DAC控制 | T | 2930 | -1425 |
| U72 | 电压基准 | T | 3185 | -1155 |
| U74 | OPA335运放 | T | 3210 | -1525 |
| U75 | 运放 | T | 3820 | -1690 |
| U76 | 24位ADC | T | 3255 | -2130 |
| U77 | 数字电位器 | T | 2255 | -2155 |
| U78 | PC817光耦 | T | 2710 | -2325 |
| U79 | DAC | T | 835 | -2225 |
| U82 | LDO | T | 1230 | -815 |
| U83 | 光耦阵列 | T | 730 | -1390 |
| U85 | LD1117 | T | 3740 | -1005 |
| U86 | LDO | T | 205 | -950 |
| U87 | 增益放大器 | T | 3505 | -1690 |
| U88 | USB接口 | T | 1545 | -2300 |
| U89 | 探头接口 | T | 3660 | -2135 |

### 4.2 连接器

| 位号 | 型号 | 层 | 坐标X (mil) | 坐标Y (mil) | 功能 |
|---|---|---|---|---|---|
| CN12 | ZX-XH2.54 | T | 160 | -1875 | 4-20mA输出1 |
| CN13 | ZX-XH2.54 | T | 160 | -2255 | 4-20mA输出2 |
| CN14 | XH-2A | T | 1535 | -210 | 24V电源输入 |
| FPC1 | FPC | T | 1400 | -1665 | LCD接口 |
| H1 | 排针 | T | 2260 | -1470 | SWD调试 |
| LCM2 | USB-C | T | 1545 | -1990 | USB接口 |
| P1 | 排针 | T | 835 | -1875 | 扩展IO |

### 4.3 无源元件统计

| 类型 | 数量 | 位号范围 |
|---|---|---|
| 电容 (C) | ~62 | C35-C135 |
| 电阻 (R) | ~25 | R95-R164 |
| 电感 (L) | ~26 | L24-L59 |
| 二极管 (D) | 9 | D1-D9 |
| LED | 1 | LED1 |
| 晶振 | 2 | OSC1, X3 |
| 晶体管 | 1 | Q2 |

### 4.4 测试点

| 位号 | 层 | 坐标X (mil) | 坐标Y (mil) | 功能 |
|---|---|---|---|---|
| TP2 | T | 1422.45 | -814.45 | +5VD测试 |
| TP3 | T | 1231.85 | -599.45 | +3.3V测试 |
| TP4 | T | 3718.08 | -526.88 | +6.5VA测试 |
| TP5 | T | 321.82 | -753.46 | +6.5VX测试 |
| TP6 | T | 2460.08 | -604.63 | DGND测试 |
| TP7 | T | 3720.08 | -364.49 | AGND测试 |
| TP8 | T | 155.08 | -746.82 | GNDX测试 |
| TP9 | T | 2854.17 | -1178.94 | Ref5V测试 |
| TP10 | T | 323.73 | -2324.00 | 4-20mA测试 |
| TP11 | T | 980.08 | -2330.36 | Vreg测试 |
| TP12 | T | 984.91 | -1923.50 | Vdac测试 |

---

## 5. PCB工艺要求

### 5.1 板材规格

| 参数 | 推荐值 |
|---|---|
| 板材 | FR-4 |
| 板厚 | 1.6mm |
| 铜厚 | 1oz (35μm) |
| 表面处理 | HASL / ENIG |
| 阻焊颜色 | 绿色 |
| 丝印颜色 | 白色 |

### 5.2 设计规则

| 参数 | 最小值 |
|---|---|
| 最小线宽 | 0.127mm (5mil) |
| 最小线距 | 0.127mm (5mil) |
| 最小孔径 | 0.3048mm |
| 最小焊盘 | 0.6mm |
| 阻焊桥 | 0.1mm |

### 5.3 阻抗控制（如需要）

| 类型 | 阻抗 | 适用信号 |
|---|---|---|
| 单端阻抗 | 50Ω | 一般高速信号 |
| 差分阻抗 | 90Ω | USB差分对 |

---

## 6. 布局分区

### 6.1 功能分区示意

```
┌───────────────────────────────────────────────────────────┐
│                      CN14(24V输入)                         │
│  ┌─────────┐  ┌─────────┐  ┌─────────┐  ┌─────────┐      │
│  │ 隔离电源 │  │ 数字电源 │  │ 模拟电源 │  │ 基准电压 │      │
│  │ U67,U68 │  │ U23,U62 │  │ U63,U64 │  │ U65     │      │
│  │ U69,U86 │  │ U82     │  │ U85     │  │         │      │
│  └─────────┘  └─────────┘  └─────────┘  └─────────┘      │
├───────────────────────────────────────────────────────────┤
│                                                           │
│  ┌─────────────┐     ┌──────────────────────────────┐    │
│  │  隔离输出区  │     │         数字控制区           │    │
│  │  U79,U83    │     │    U22(STM32), OSC1, LED1    │    │
│  │  CN12,CN13  │     │    H1(SWD), FPC1(LCD)       │    │
│  │  Q2,P1      │     │    LCM2(USB), U88           │    │
│  └─────────────┘     └──────────────────────────────┘    │
│                                                           │
│  ┌─────────────────────────────────────────────────────┐ │
│  │                    模拟信号区                        │ │
│  │  U71,U72,U74,U75,U76,U77,U78,U87,U89,X3            │ │
│  │  高精度ADC、运放、DAC、光耦隔离                       │ │
│  └─────────────────────────────────────────────────────┘ │
└───────────────────────────────────────────────────────────┘
```

### 6.2 关键布局位置

| 功能区 | 位置 | 主要器件 |
|---|---|---|
| 电源输入 | 顶部中央 | CN14 |
| 数字电源 | 顶部左侧 | U23, U62, U82 |
| 模拟电源 | 顶部右侧 | U63, U64, U65, U85 |
| 隔离电源 | 左上角 | U67, U68, U69, U86 |
| 主控MCU | 中部 | U22 |
| 模拟采集 | 右下方 | U71-U76, U87, U89 |
| 隔离输出 | 左侧边缘 | U79, U83, CN12, CN13 |
| USB接口 | 底部中央 | LCM2, U88 |

---

## 7. 飞针测试

### 7.1 测试文件

- 文件名：`FlyingProbeTesting.json`
- 格式：JSON
- 单位：mil

### 7.2 测试点信息

| 参数 | 数值 |
|---|---|
| 总测试点数 | ~176+ |
| 顶层测试点 | ~120 |
| 底层测试点 | ~56 |
| 测试覆盖率 | 100% 网络 |

---

## 8. 生产注意事项

### 8.1 下单前检查

- [ ] 确认板厚符合要求（推荐1.6mm）
- [ ] 确认铜厚符合要求（推荐1oz）
- [ ] 确认表面处理工艺
- [ ] 确认阻焊和丝印颜色
- [ ] 确认钻孔公差要求
- [ ] 确认阻抗控制需求

### 8.2 SMT贴片注意

- [ ] 顶层和底层均有元器件
- [ ] 注意细间距IC（STM32 LQFP-64）
- [ ] 注意小封装元件（0402/0603）
- [ ] 检查极性器件方向

### 8.3 下单链接

参考：https://prodocs.lceda.cn/cn/pcb/order-order-pcb/index.html

---

## 9. 文件校验

### 9.1 Gerber文件格式

| 参数 | 设置 |
|---|---|
| 格式 | RS-274X |
| 单位 | 毫米 (mm) |
| 坐标格式 | 4.5 (整数4位,小数5位) |
| 零点抑制 | 前导零省略 |
| 坐标模式 | 绝对坐标 |

### 9.2 钻孔文件格式

| 参数 | 设置 |
|---|---|
| 格式 | Excellon |
| 单位 | 毫米 (METRIC) |
| 坐标格式 | 4.5 |
| 零点抑制 | 后导零省略 (LZ) |
| 孔类型 | PTH (电镀通孔) |

---

## 10. 版本历史

| 版本 | 日期 | 修改内容 |
|---|---|---|
| V1.0 | 2025-09-26 | 初始版本 |

---

*本文档由嘉立创EDA测量仪器开发组生成*
*Gerber文件生成时间：2025-09-26 15:24:21*

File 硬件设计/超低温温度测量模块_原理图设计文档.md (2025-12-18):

# 超低温温度测量模块 - 原理图设计文档

## 文档信息

| 项目 | 内容 |
|---|---|
| 项目名称 | 超低温温度测量模块 |
| 原理图版本 | V1.0 |
| 图纸编号 | Schematic6 |
| 图纸页数 | 4页 (P1-P4) |
| 图纸尺寸 | A4 |
| 设计单位 | 嘉立创EDA / 测量仪器开发组 |
| 创建日期 | 2025-09-26 |
| 更新日期 | 2025-09-26 |

---

## 1. 系统概述

### 1.1 功能简介

Ultra-TM02型超低温温度测量模块是一款高精度温度测量设备，专门用于二极管式温度探头的超低温测量，支持用户自定义探头分度表。

### 1.2 主要技术指标

| 参数 | 规格 |
|---|---|
| 温度测量范围 | 1.4K ~ 500K (-271.75℃ ~ 226.85℃) |
| 显示分辨率 | 0.001℃ |
| 最大允许误差 | 低温段 ±1℃，高温段 ±2℃ |
| ADC精度 | 24位 |
| 内部电流源精度 | ≤0.05% |
| 数据更新率 | 最高1次/秒 |
| 探头类型 | 二极管式（4线差分） |
| 激励电流 | 10μA / 17μA可选 |
| 输出形式 | 4-20mA（两线制） |
| 供电电压 | 24V DC |
| 显示屏 | 3.5寸液晶 |

### 1.3 系统框图

```
┌─────────────────────────────────────────────────────────────────┐
│                        超低温温度测量模块                          │
├─────────────────────────────────────────────────────────────────┤
│                                                                 │
│  ┌─────────┐    ┌─────────┐    ┌─────────┐    ┌─────────┐     │
│  │ 24V输入  │───→│ 电源管理 │───→│ 多轨电源 │───→│ 各功能块 │     │
│  └─────────┘    └─────────┘    └─────────┘    └─────────┘     │
│                                                                 │
│  ┌─────────┐    ┌─────────┐    ┌─────────┐    ┌─────────┐     │
│  │ 温度探头 │───→│ 信号调理 │───→│ ADC采集  │───→│ STM32   │     │
│  └─────────┘    └─────────┘    └─────────┘    └─────────┘     │
│                                                    │           │
│                    ┌───────────────────────────────┤           │
│                    ↓              ↓                ↓           │
│              ┌─────────┐   ┌─────────┐      ┌─────────┐       │
│              │ LCD显示  │   │ USB通讯 │      │ 4-20mA  │       │
│              └─────────┘   └─────────┘      └─────────┘       │
│                                                                 │
└─────────────────────────────────────────────────────────────────┘
```

---

## 2. 电源系统设计 (P3)

### 2.1 电源架构

本设计采用**三地隔离**架构，实现数字、模拟和输出电路的完全隔离：

```
+24V输入(CN14)
    │
    ├─→ U62 ─→ +5VD ─→ U82 ─→ 3V3 (数字电路)
    │
    ├─→ U63 ─→ +9VA ─→ U65 ─→ 6.5VA ─→ U85 ─→ 5VA (模拟电路)
    │
    └─→ U67 ─→ +9VX ─→ U69 ─→ 6.5VX ─→ U86 ─→ 5VX (隔离输出)
```

### 2.2 电源输入电路

| 器件 | 型号 | 功能 |
|---|---|---|
| CN14 | XH-2A | 24V DC输入端子 |
| U23 | DC-DC | 输入保护与转换 |

### 2.3 数字电源轨

| 电源 | 电压 | 器件 | 负载 |
|---|---|---|---|
| +5VD | 5V | U62 | 数字电路总电源 |
| 3V3 | 3.3V | U82 | STM32主控、逻辑电路 |

**滤波配置：**
- 输入：L24(4.7μH) + C77(10μF) + C78/C79(22μF)
- 3V3输出：C121(10μF) + C122(10μF)

### 2.4 模拟电源轨 (AGND参考)

| 电源 | 电压 | 器件 | 负载 |
|---|---|---|---|
| +9VA | 9V | U63 | 模拟隔离电源 |
| 6.5VA | 6.5V | U65 | 精密基准电压 |
| 5VA | 5V | U85 (LD1117S50TR) | 运放、ADC供电 |

**基准电压调节：**
- R130(240Ω) + R131(820Ω) + R132(500Ω)
- D1/D2 (1N4002W) 反向保护

### 2.5 隔离电源轨 (GNDX参考)

| 电源 | 电压 | 器件 | 负载 |
|---|---|---|---|
| +9VX | 9V | U67 | 输出隔离电源 |
| 6.5VX | 6.5V | U69 | 隔离基准电压 |
| 5VX | 5V | U86 | 4-20mA输出电路 |

**基准电压调节：**
- R133(240Ω) + R134(820Ω) + R135(500Ω)
- D3/D4 (1N4002W) 反向保护

### 2.6 测试点定义

| 测试点 | 信号 | 预期电压 |
|---|---|---|
| TP2 | +5VD | 5.0V ±5% |
| TP3 | +3.3V | 3.3V ±3% |
| TP4 | +6.5VA | 6.5V ±1% |
| TP5 | +6.5VX | 6.5V ±1% |
| TP6 | DGND | 0V (数字地) |
| TP7 | AGND | 0V (模拟地) |
| TP8 | GNDX | 0V (隔离地) |

---

## 3. 主控电路设计 (P2)

### 3.1 MCU选型

| 参数 | 规格 |
|---|---|
| 型号 | STM32F411RET6 |
| 内核 | ARM Cortex-M4 |
| 主频 | 100MHz |
| Flash | 512KB |
| RAM | 128KB |
| 封装 | LQFP-64 |
| 工作电压 | 3.3V |

### 3.2 时钟电路

**主晶振 (OSC1):**
- 频率：12MHz
- 负载电容：C123 (100nF)
- 连接：PH0-OSC_IN, PH1-OSC_OUT

### 3.3 复位与调试

**SWD调试接口 (H1 - PZ254V-11-04P):**

| 引脚 | 信号 | 功能 |
|---|---|---|
| 1 | 3V3 | 电源 |
| 2 | DGND | 地 |
| 3 | SWDIO | 数据 |
| 4 | JTCK-SWCLK | 时钟 |

### 3.4 GPIO分配

**SPI控制信号：**
| 信号 | 功能 |
|---|---|
| IO_DAC1_CS | DAC1片选 |
| IO_DAC2_CS | DAC2片选 |
| IO_DAC_ADC_MOSI | SPI数据输出 |
| IO_DAC_ADC_SCK | SPI时钟 |
| IO_DAC_ADC_MISO | SPI数据输入 |
| IO_DAC2_LOAD | DAC2加载 |
| IO_ADC1_CS | ADC1片选 |

**串口信号：**
| 信号 | 功能 |
|---|---|
| IO_USART6_TX | LCD发送 |
| IO_USART6_RX | LCD接收 |

### 3.5 LCD显示接口

**FPC接口 (FPC1 - LCD 1.25-4PWB):**

| 引脚 | 信号 |
|---|---|
| 1 | DGND |
| 2 | +5VD |
| 3 | IO_USART6_RX |
| 4 | IO_USART6_TX |

### 3.6 去耦电容配置

| 电容 | 规格 | 位置 |
|---|---|---|
| C58-C62 | 100nF | 各VDD引脚 |
| C68 | 10uF | 大电容去耦 |
| C76 | 2.2uF | 中频去耦 |
| C63 | 100nF | DGND附近 |

### 3.7 状态指示

**LED1 (KT-0805G):**
- 颜色：绿色
- 限流电阻：R120, R104
- 功能：电源/运行状态指示

---

## 4. 信号采集电路设计 (P1)

### 4.1 信号链路

```
探头 → U89.1连接器 → U74(OPA335) → U75 → U87(G=2) → U76(ADC)
                     前置放大      二级放大  增益放大    数字采集
```

### 4.2 探头接口

**U89.1 连接器 (ZX-XH2.54-4PZZ):**
- 4线差分连接方式
- 支持二极管式温度探头
- Load信号输出

### 4.3 前置放大器

**U74 - OPA335AIDBVR:**

| 参数 | 规格 |
|---|---|
| 类型 | 零漂移精密运放 |
| 偏置电压 | ≤5μV |
| 漂移 | ≤0.05μV/℃ |
| 噪声 | 低噪声设计 |

**外围配置：**
| 元件 | 规格 | 功能 |
|---|---|---|
| R137 | - | 输入调理 |
| C96 | 10nF | 高频滤波 |
| C97 | 3.3nF | 带宽限制 |
| R162/R136 | 100kΩ | 反馈网络 |

### 4.4 增益放大器

**U87 配置：**
- 增益：G = 2
- R164/R157：200kΩ（增益设定）
- C131：500pF（高频补偿）

### 4.5 ADC采集

**U76 - 24位高精度ADC:**

| 引脚 | 信号 | 功能 |
|---|---|---|
| SCLK | DAC_ADC_SCK | SPI时钟 |
| CS# | ADC1_CS | 片选（隔离后） |
| DIN | DAC_ADC_MOSI | 数据输入 |
| DOUT/RDY# | DAC_ADC_MISO | 数据输出 |
| AIN+/AIN- | 差分输入 | 模拟信号输入 |
| VDD | 5VA | 电源 |
| REF- | - | 参考负端 |

**滤波配置：**
| 元件 | 规格 | 功能 |
|---|---|---|
| C104 | 100nF | VDD去耦 |
| C124 | 10nF | 参考滤波 |
| C105 | 10nF | AIN滤波 |
| R142/R143 | 1kΩ | 输入保护 |

### 4.6 光耦隔离

**U78 - PC817D-S:**
- 隔离信号：ADC1_CS
- 输入侧：IO_ADC1_CS (DGND参考)
- 输出侧：ADC1_CS (AGND参考)
- R145：200Ω（LED限流）
- R144：4.7kΩ（输出上拉）

### 4.7 DAC/数字电位器

**U77 多通道配置：**
- 双电源：VDD1/GND1, VDD2/GND2
- 多输出：VA, VB, VC, VD
- 使能控制：NC/EN1, NC/EN2

**U71/U72 电压基准：**
- TP9测试点：Ref5V（5V参考电压）

---

## 5. 输出电路设计 (P4)

### 5.1 DAC2隔离电路

**U83 光耦阵列：**

| 输入信号(DGND) | 输出信号(GNDX) |
|---|---|
| IO_DAC2_CS | DAC2_CS |
| IO_DAC2_MOSI | DAC2_MOSI |
| IO_DAC2_SCK | DAC2_SCK |
| IO_DAC2_LOAD | DAC2_LOAD |

### 5.2 V/I转换电路

**U79 DAC芯片：**

| 引脚 | 功能 |
|---|---|
| VREF | 参考电压输入 |
| IIN | 电流输入 |
| IRET | 电流返回 |
| B/BASE | 晶体管基极驱动 |
| E/EMITTER | 发射极连接 |
| VREG | 稳压输出 |

**Q2 功率晶体管：**
- 功能：4-20mA电流输出驱动
- R150：20kΩ（DAC输入）

### 5.3 4-20mA输出接口

**CN12/CN13 (ZX-XH2.54-2PZZ):**

| 引脚 | 信号 |
|---|---|
| 1 | +24V NC |
| 2 | GndEx NC |

**输出规格：**
| 参数 | 规格 |
|---|---|
| 电流范围 | 4-20mA |
| 精度 | ±0.1% |
| 负载能力 | 0-500Ω |
| 接线方式 | 两线制 |

### 5.4 输出保护电路

| 元件 | 型号 | 功能 |
|---|---|---|
| D5 | P6KE39A | TVS过压保护 |
| D6-D9 | - | 反接/过流保护 |
| C117 | 10nF | 输出滤波 |
| R146 | 250Ω | 测试电阻 |

### 5.5 测试点

| 测试点 | 信号 | 功能 |
|---|---|---|
| TP10 | 4-20mA Test | 电流输出测试 |
| TP11 | Vreg | 稳压输出测试 |
| TP12 | Vdac | DAC输出测试 |

---

## 6. USB通讯电路 (P4)

### 6.1 USB接口

**U88 (ZX-XH2.54-4PZZ):**

| 引脚 | 信号 |
|---|---|
| 1 | USB_P |
| 2 | USB_N |
| 3 | GNDI |
| 4 | 屏蔽 |

### 6.2 信号处理

**信号链路：**
```
STM32 → USB_PA/USB_NA → R97 → LCM2 → L26 → USB_P/USB_N → U88
```

**滤波元件：**
| 元件 | 规格 | 功能 |
|---|---|---|
| L26 | 滤波电感 | EMI滤波 |
| R97-R100 | - | 阻抗匹配 |
| C69 | 4.7nF | USB滤波 |

### 6.3 USB规格

| 参数 | 规格 |
|---|---|
| 标准 | USB 2.0 Full Speed |
| 速度 | 12Mbps |
| 类型 | CDC虚拟串口 |
| 接口 | Type-C |

---

## 7. 元器件清单 (BOM)

### 7.1 IC芯片

| 器件 | 型号 | 数量 | 功能 |
|---|---|---|---|
| U22 | STM32F411RET6 | 1 | 主控MCU |
| U74 | OPA335AIDBVR | 1 | 精密运放 |
| U75 | 运放 | 1 | 二级放大 |
| U76 | 24位ADC | 1 | 温度采集 |
| U77 | 数字电位器 | 1 | 信号切换 |
| U78 | PC817D-S | 1 | 光耦隔离 |
| U79 | DAC | 1 | V/I转换 |
| U83 | 光耦阵列 | 1 | DAC2隔离 |
| U85 | LD1117S50TR | 1 | 5VA稳压 |

### 7.2 连接器

| 器件 | 型号 | 数量 | 功能 |
|---|---|---|---|
| CN14 | XH-2A | 1 | 24V电源输入 |
| CN12 | ZX-XH2.54-2PZZ | 1 | 4-20mA输出 |
| CN13 | ZX-XH2.54-2PZZ | 1 | 测试端口 |
| FPC1 | LCD 1.25-4PWB | 1 | LCD接口 |
| H1 | PZ254V-11-04P | 1 | SWD调试 |
| U88 | ZX-XH2.54-4PZZ | 1 | USB接口 |
| U89.1 | ZX-XH2.54-4PZZ | 1 | 探头接口 |

### 7.3 无源元件概览

| 类别 | 数量 | 主要规格 |
|---|---|---|
| 电阻 | ~40 | 200Ω - 200kΩ |
| 电容 | ~50 | 10nF - 100μF |
| 电感 | ~8 | 4.7μH |
| 晶振 | 2 | 12MHz |
| 二极管 | ~10 | 1N4002W, P6KE39A |
| LED | 1 | KT-0805G (绿色) |

---

## 8. PCB设计建议

### 8.1 层叠结构

建议采用4层板设计：
- Layer 1: 信号层（顶层）
- Layer 2: 地平面
- Layer 3: 电源平面
- Layer 4: 信号层（底层）

### 8.2 布局分区

```
┌──────────────────────────────────┐
│  电源区      │     数字区        │
│ (DC-DC,LDO) │  (STM32,USB)      │
├─────────────┼───────────────────┤
│  模拟区      │    隔离输出区     │
│ (ADC,运放)  │   (4-20mA)        │
└──────────────────────────────────┘
```

### 8.3 地平面设计

- DGND与AGND单点接地
- GNDX完全隔离（通过光耦和隔离DC-DC）
- 避免形成地回路

### 8.4 关键走线要求

| 信号类型 | 阻抗/宽度 | 注意事项 |
|---|---|---|
| USB差分 | 90Ω ±10% | 等长匹配 |
| SPI信号 | - | 串联22Ω阻抗 |
| 电源走线 | ≥20mil | 星型布线 |
| 模拟信号 | - | 远离数字区 |

---

## 9. 版本历史

| 版本 | 日期 | 修改内容 |
|---|---|---|
| V1.0 | 2025-09-26 | 初始版本发布 |

---

*本文档由嘉立创EDA测量仪器开发组编制*

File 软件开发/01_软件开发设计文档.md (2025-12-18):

# 超低温温度测量模块 - 软件开发设计文档

## 文档信息

| 项目 | 内容 |
|---|---|
| 产品名称 | Ultra-TM02 超低温温度测量模块 |
| 文档类型 | 软件开发设计文档 |
| 版本 | V1.0 |
| 创建日期 | 2025年12月18日 |
| 主控芯片 | STM32F411RET6 |
| 开发环境 | Keil MDK / STM32CubeIDE |

---

## 目录

1. [项目概述](#一项目概述)
2. [硬件资源](#二硬件资源)
3. [软件架构设计](#三软件架构设计)
4. [功能模块设计](#四功能模块设计)
5. [通讯协议设计](#五通讯协议设计)
6. [LCD显示设计](#六lcd显示设计)
7. [上位机软件设计](#七上位机软件设计)
8. [数据存储设计](#八数据存储设计)
9. [开发计划](#九开发计划)

---

## 一、项目概述

### 1.1 产品功能

Ultra-TM02型超低温温度测量模块主要功能：

| 功能 | 描述 |
|---|---|
| **温度测量** | 测量二极管探头的节电压，转换为温度值 |
| **温度显示** | 3.5寸LCD显示温度值，分辨率0.001℃ |
| **4-20mA输出** | 将温度值转换为4-20mA电流信号输出 |
| **USB通讯** | 与上位机软件通讯，参数设置 |
| **分度表下载** | 支持用户自定义探头分度表 |
| **参数存储** | 参数存储到Flash，掉电不丢失 |

### 1.2 主要技术指标

| 参数 | 规格 |
|---|---|
| 温度测量范围 | 1.4K ~ 500K (-271.75℃ ~ 226.85℃) |
| 显示分辨率 | 0.001℃ |
| 最大允许误差 | 低温段 ±1℃，高温段 ±2℃ |
| ADC精度 | 24位 |
| 内部电流源精度 | ≤0.05% |
| 数据更新率 | 最高1次/秒 |
| 探头类型 | 二极管式（4线差分） |
| 激励电流 | 10μA / 17μA 可选 |
| 输出形式 | 4-20mA（两线制） |

---

## 二、硬件资源

### 2.1 MCU资源

| 参数 | 规格 |
|---|---|
| 型号 | STM32F411RET6 |
| 内核 | ARM Cortex-M4 |
| 主频 | 100MHz |
| Flash | 512KB |
| RAM | 128KB |
| 封装 | LQFP-64 |

### 2.2 外设分配

| 外设 | 功能 | 引脚 |
|---|---|---|
| **SPI1** | ADC/DAC通讯 | PA5(SCK), PA6(MISO), PA7(MOSI) |
| **USART6** | LCD串口屏通讯 | PC6(TX), PC7(RX) |
| **USB** | 上位机通讯 | PA11(DM), PA12(DP) |
| **GPIO** | ADC片选 | ADC1_CS |
| **GPIO** | DAC片选 | DAC1_CS, DAC2_CS |
| **GPIO** | DAC加载 | DAC1_LOAD, DAC2_LOAD |
| **GPIO** | LED指示 | LED1 |
| **SWD** | 调试接口 | PA13(SWDIO), PA14(SWCLK) |

### 2.3 接口定义

| 接口 | 类型 | 功能 |
|---|---|---|
| CN14 | XH2.54-2P | 24V电源输入 |
| U89.1 | XH2.54-4P | 温度探头接口（4线差分） |
| FPC1 | 1.25mm-4P | LCD显示屏接口 |
| LCM2 | USB Type-C | 上位机通讯 |
| H1 | 排针 2.54mm-4P | SWD调试接口 |
| CN12/CN13 | XH2.54-2P | 4-20mA输出 |

### 2.4 FPC1 LCD接口引脚定义

| 引脚 | 信号 | MCU引脚 | 说明 |
|---|---|---|---|
| 1 | DGND | - | 地 |
| 2 | +5VD | - | 5V电源 |
| 3 | IO_USART6_RX | PC7 | 主板接收←屏幕发送 |
| 4 | IO_USART6_TX | PC6 | 主板发送→屏幕接收 |

### 2.5 H1 SWD调试接口引脚定义

| 引脚 | 信号 | MCU引脚 | 说明 |
|---|---|---|---|
| 1 | 3V3 | - | 3.3V电源 |
| 2 | DGND | - | 地 |
| 3 | SWDIO | PA13 | SWD数据 |
| 4 | SWCLK | PA14 | SWD时钟 |

### 2.6 CN14 电源接口引脚定义

| 引脚 | 信号 | 说明 |
|---|---|---|
| 1 | GND | 电源负极 |
| 2 | +24V | 电源正极 (DC 24V) |

### 2.7 U89.1 温度探头接口引脚定义

| 引脚 | 信号 | 说明 |
|---|---|---|
| 1 | V+ | 电压测量正端 |
| 2 | I+ | 电流激励正端 |
| 3 | I- | 电流激励负端 |
| 4 | V- | 电压测量负端 |

> 注：采用四线制测量，消除引线电阻影响

---

## 三、软件架构设计

### 3.1 软件分层架构

```
┌─────────────────────────────────────────────────────┐
│                    应用层 (APP)                      │
│  ┌─────────┐ ┌─────────┐ ┌─────────┐ ┌─────────┐  │
│  │温度测量 │ │数据处理 │ │参数管理 │ │通讯处理 │  │
│  └─────────┘ └─────────┘ └─────────┘ └─────────┘  │
├─────────────────────────────────────────────────────┤
│                   服务层 (Service)                   │
│  ┌─────────┐ ┌─────────┐ ┌─────────┐ ┌─────────┐  │
│  │ADC服务  │ │DAC服务  │ │LCD服务  │ │USB服务  │  │
│  └─────────┘ └─────────┘ └─────────┘ └─────────┘  │
├─────────────────────────────────────────────────────┤
│                   驱动层 (Driver)                    │
│  ┌─────────┐ ┌─────────┐ ┌─────────┐ ┌─────────┐  │
│  │SPI驱动  │ │UART驱动 │ │USB驱动  │ │GPIO驱动 │  │
│  └─────────┘ └─────────┘ └─────────┘ └─────────┘  │
├─────────────────────────────────────────────────────┤
│                   硬件层 (HAL)                       │
│              STM32 HAL / LL 库                       │
└─────────────────────────────────────────────────────┘
```

### 3.2 目录结构

```
Project/
├── Core/
│   ├── Inc/                    # 头文件
│   │   ├── main.h
│   │   ├── stm32f4xx_it.h
│   │   └── stm32f4xx_hal_conf.h
│   └── Src/                    # 源文件
│       ├── main.c
│       ├── stm32f4xx_it.c
│       └── system_stm32f4xx.c
├── Drivers/
│   ├── STM32F4xx_HAL_Driver/   # HAL库
│   └── CMSIS/                  # CMSIS库
├── App/                        # 应用层
│   ├── Inc/
│   │   ├── app_temp.h          # 温度测量
│   │   ├── app_data.h          # 数据处理
│   │   ├── app_param.h         # 参数管理
│   │   └── app_comm.h          # 通讯处理
│   └── Src/
│       ├── app_temp.c
│       ├── app_data.c
│       ├── app_param.c
│       └── app_comm.c
├── Service/                    # 服务层
│   ├── Inc/
│   │   ├── svc_adc.h           # ADC服务
│   │   ├── svc_dac.h           # DAC服务
│   │   ├── svc_lcd.h           # LCD服务
│   │   └── svc_usb.h           # USB服务
│   └── Src/
│       ├── svc_adc.c
│       ├── svc_dac.c
│       ├── svc_lcd.c
│       └── svc_usb.c
├── BSP/                        # 板级支持
│   ├── Inc/
│   │   ├── bsp_spi.h
│   │   ├── bsp_uart.h
│   │   ├── bsp_gpio.h
│   │   └── bsp_flash.h
│   └── Src/
│       ├── bsp_spi.c
│       ├── bsp_uart.c
│       ├── bsp_gpio.c
│       └── bsp_flash.c
└── Middlewares/                # 中间件
    └── USB_Device/             # USB设备库
```

### 3.3 主程序流程

```c
int main(void)
{
    // 1. 系统初始化
    HAL_Init();
    SystemClock_Config();
    
    // 2. 外设初始化
    BSP_GPIO_Init();
    BSP_SPI_Init();
    BSP_UART_Init();
    BSP_USB_Init();
    
    // 3. 服务初始化
    SVC_ADC_Init();
    SVC_DAC_Init();
    SVC_LCD_Init();
    
    // 4. 应用初始化
    APP_Param_Load();       // 加载参数
    APP_Temp_Init();        // 温度测量初始化
    
    // 5. 主循环
    while (1)
    {
        APP_Temp_Process();     // 温度测量处理
        APP_Data_Process();     // 数据处理
        APP_Comm_Process();     // 通讯处理
        SVC_LCD_Update();       // LCD刷新
    }
}
```

---

## 四、功能模块设计

### 4.1 温度测量模块

#### 4.1.1 功能描述

- 控制DAC输出激励电流（10μA/17μA）
- 采集二极管正向压降（ADC）
- 根据分度表查表计算温度值
- 滤波处理，提高测量稳定性

#### 4.1.2 测量流程

```
┌─────────────┐
│  开始测量   │
└──────┬──────┘
       ↓
┌──────────────┐
│ DAC输出电流  │  → 10μA 或 17μA
└──────┬───────┘
       ↓
┌──────────────┐
│ 等待稳定     │  → 延时10ms
└──────┬───────┘
       ↓
┌──────────────┐
│ ADC采集电压  │  → 24位ADC
└──────┬───────┘
       ↓
┌──────────────┐
│ 数字滤波     │  → 中值滤波 + 均值滤波
└──────┬───────┘
       ↓
┌──────────────┐
│ 查分度表     │  → 4871点曲线
└──────┬───────┘
       ↓
┌──────────────┐
│ 计算温度     │  → 线性插值
└──────┬───────┘
       ↓
┌──────────────┐
│ 更新显示     │
└──────────────┘
```

#### 4.1.3 关键代码结构

```c
// 温度测量结构体
typedef struct {
    float voltage_mV;       // 二极管电压 (mV)
    float temperature_C;    // 温度值 (℃)
    float temperature_K;    // 温度值 (K)
    uint8_t current_src;    // 电流源选择 (0:10μA, 1:17μA)
    uint8_t status;         // 测量状态
} TempMeasure_t;

// 温度测量API
void APP_Temp_Init(void);
void APP_Temp_Start(void);
void APP_Temp_Stop(void);
void APP_Temp_Process(void);
float APP_Temp_GetValue(void);
float APP_Temp_GetVoltage(void);
```

### 4.2 ADC采集模块

#### 4.2.1 ADC芯片配置

| 参数 | 配置 |
|---|---|
| 芯片型号 | 24位高精度ADC |
| 接口 | SPI |
| 采样率 | 最高1次/秒 |
| 输入方式 | 差分输入 |
| 参考电压 | 6.5V (高精度) |

#### 4.2.2 ADC驱动接口

```c
// ADC服务接口
void SVC_ADC_Init(void);
uint32_t SVC_ADC_ReadRaw(void);
float SVC_ADC_ReadVoltage(void);
void SVC_ADC_StartConversion(void);
uint8_t SVC_ADC_IsReady(void);
```

### 4.3 DAC输出模块

#### 4.3.1 DAC功能

| 通道 | 功能 |
|---|---|
| DAC1 | 探头激励电流控制 |
| DAC2 | 4-20mA输出控制 |

#### 4.3.2 电流源控制

```c
// 电流源选择
typedef enum {
    CURRENT_SRC_10UA = 0,   // 10μA电流源
    CURRENT_SRC_17UA = 1    // 17μA电流源
} CurrentSource_e;

// DAC服务接口
void SVC_DAC_Init(void);
void SVC_DAC_SetCurrentSource(CurrentSource_e src);
void SVC_DAC_Set420mA(float current_mA);
void SVC_DAC_SetVoltage(uint8_t channel, float voltage);
```

### 4.4 4-20mA输出模块

#### 4.4.1 功能描述

- 将温度值线性映射到4-20mA
- 用户可设置4mA和20mA对应的温度点
- 通过隔离DAC控制V/I转换电路

#### 4.4.2 转换公式

```
I_out = 4 + (T_current - T_4mA) / (T_20mA - T_4mA) × 16

其中：
- I_out: 输出电流 (mA)
- T_current: 当前温度 (℃)
- T_4mA: 4mA对应温度点 (℃)
- T_20mA: 20mA对应温度点 (℃)
```

#### 4.4.3 代码实现

```c
// 4-20mA输出配置
typedef struct {
    float temp_4mA;         // 4mA对应温度
    float temp_20mA;        // 20mA对应温度
    float current_mA;       // 当前输出电流
} Output420mA_t;

// 计算输出电流
float APP_Output_CalcCurrent(float temperature)
{
    float current;
    Output420mA_t *cfg = &g_output_cfg;
    
    // 线性插值
    current = 4.0f + (temperature - cfg->temp_4mA) / 
              (cfg->temp_20mA - cfg->temp_4mA) * 16.0f;
    
    // 限幅
    if (current < 4.0f) current = 4.0f;
    if (current > 20.0f) current = 20.0f;
    
    return current;
}
```

---

## 五、通讯协议设计

### 5.1 USB CDC虚拟串口

#### 5.1.1 通讯参数

| 参数 | 配置 |
|---|---|
| 接口类型 | USB CDC (虚拟串口) |
| 波特率 | 115200 (可配置) |
| 数据位 | 8 |
| 停止位 | 1 |
| 校验 | 无 |

#### 5.1.2 命令帧格式

```
┌──────┬──────┬──────┬──────┬──────┬──────┐
│ 帧头 │ 命令 │ 长度 │ 数据 │ 校验 │ 帧尾 │
│ 0xAA │ CMD  │ LEN  │ DATA │ CRC  │ 0x55 │
└──────┴──────┴──────┴──────┴──────┴──────┘
```

### 5.2 命令列表

| 命令码 | 名称 | 描述 |
|---|---|---|
| 0x01 | GET_DEVICE_ID | 获取设备ID |
| 0x02 | GET_TEMPERATURE | 获取温度值 |
| 0x03 | GET_VOLTAGE | 获取电压值 |
| 0x10 | SET_CURRENT_SRC | 设置电流源 |
| 0x11 | SET_CURRENT_ADJ | 设置电流调整值 |
| 0x20 | SET_4MA_TEMP | 设置4mA温度点 |
| 0x21 | SET_20MA_TEMP | 设置20mA温度点 |
| 0x30 | START_ACQ | 开始采集 |
| 0x31 | STOP_ACQ | 停止采集 |
| 0x40 | LOAD_TABLE | 加载分度表 |
| 0x50 | SAVE_PARAM | 存储参数 |

### 5.3 命令详细定义

#### 5.3.1 获取设备ID (0x01)

**请求：**
```
AA 01 00 [CRC] 55
```

**响应：**
```
AA 01 10 [16字节设备ID] [CRC] 55
```

#### 5.3.2 获取温度值 (0x02)

**请求：**
```
AA 02 00 [CRC] 55
```

**响应：**
```
AA 02 04 [4字节温度值float] [CRC] 55
```

#### 5.3.3 设置电流源 (0x10)

**请求：**
```
AA 10 01 [电流源:0=10μA,1=17μA] [CRC] 55
```

**响应：**
```
AA 10 01 [状态:0=成功] [CRC] 55
```

#### 5.3.4 加载分度表 (0x40)

**请求：**（分包发送）
```
AA 40 [LEN] [包序号] [分度表数据...] [CRC] 55
```

**响应：**
```
AA 40 01 [状态:0=成功] [CRC] 55
```

---

## 六、LCD显示设计

### 6.1 显示屏配置

| 参数 | 配置 |
|---|---|
| 型号 | 淘晶驰 TJC4832T035 |
| 尺寸 | 3.5寸 |
| 分辨率 | 480×320 |
| 接口 | USART串口 (TTL) + 2.54mm排针 |
| 波特率 | 115200 |
| 通讯协议 | 淘晶驰专有协议 |

> 注：主板FPC1为1.25mm接口，需使用1.25转2.54转接线连接

### 6.2 界面设计

```
┌────────────────────────────────────────────┐
│           超低温温度测量模块                  │
├────────────────────────────────────────────┤
│                                            │
│        T = -196.543 ℃                     │
│                                            │
│        Vpn: 1023.456 mV                    │
│                                            │
├────────────────────────────────────────────┤
│  电流源: 10μA    │    输出: 12.5mA         │
├────────────────────────────────────────────┤
│  状态: 正常测量  │    Ver: V1.0            │
└────────────────────────────────────────────┘
```

### 6.3 显示内容

| 区域 | 内容 | 更新频率 |
|---|---|---|
| 主显示区 | 温度值 (0.001℃分辨率) | 1Hz |
| 电压显示 | 二极管电压 (mV) | 1Hz |
| 状态栏 | 电流源、输出电流、状态 | 1Hz |

### 6.4 LCD通讯接口

```c
// LCD服务接口
void SVC_LCD_Init(void);
void SVC_LCD_Update(void);
void SVC_LCD_SetTemperature(float temp);
void SVC_LCD_SetVoltage(float voltage);
void SVC_LCD_SetStatus(const char *status);
void SVC_LCD_SetCurrent(float current);
```

### 6.5 淘晶驰串口屏指令

```c
// 发送文本到控件
void LCD_SendText(const char *obj_name, const char *text)
{
    char cmd[64];
    sprintf(cmd, "%s.txt=\"%s\"", obj_name, text);
    LCD_SendCommand(cmd);
}

// 发送数值到控件
void LCD_SendValue(const char *obj_name, int value)
{
    char cmd[64];
    sprintf(cmd, "%s.val=%d", obj_name, value);
    LCD_SendCommand(cmd);
}

// 发送指令
void LCD_SendCommand(const char *cmd)
{
    HAL_UART_Transmit(&huart6, (uint8_t*)cmd, strlen(cmd), 100);
    uint8_t end[3] = {0xFF, 0xFF, 0xFF};
    HAL_UART_Transmit(&huart6, end, 3, 100);
}
```

---

## 七、上位机软件设计

### 7.1 软件概述

上位机软件名称：**TempDownloader**

| 功能 | 描述 |
|---|---|
| 串口通讯 | 自动识别COM口，建立与模块连接 |
| 设备识别 | 获取设备ID，确认通讯正常 |
| 参数设置 | 电流源选择、微调、4-20mA设置 |
| 数据采集 | 实时显示温度和电压数据 |
| 分度表下载 | 加载自定义探头分度表 |
| 参数存储 | 保存参数到模块Flash |

### 7.2 界面设计

```
┌──────────────────────────────────────────────────────────────┐
│  超低温温度计                                           [X]  │
├──────────────────────────────────────────────────────────────┤
│                                                              │
│  串行口：[ASRL13::INSTR     ▼]                              │
│                                                              │
│  设备ID：[                    ]     [获取设备ID]             │
│                                                              │
├────────────────────────┬─────────────────────────────────────┤
│       电流源            │           (4-20)mA                  │
├────────────────────────┼─────────────────────────────────────┤
│  ◉ 10uA    ○ 17uA     │  4mA代表温度点：[        ] ℃       │
│                        │                                     │
│  10uA调整值：[    ] uA │  20mA代表温度点：[        ] ℃      │
│  17uA调整值：[    ] uA │                                     │
│                        │                                     │
│  [  电流源调整  ]      │        [(4-20)mA调整]              │
├────────────────────────┴─────────────────────────────────────┤
│                                                              │
│  [开始采集]  [停止采集]  [加载分度表]  [存储参数]           │
│                                                              │
└──────────────────────────────────────────────────────────────┘
```

### 7.3 开发技术

| 项目 | 选择 |
|---|---|
| 开发语言 | C# / Python |
| UI框架 | WinForms / PyQt5 |
| 串口库 | System.IO.Ports / pyserial |
| 开发工具 | Visual Studio / PyCharm |

### 7.4 主要功能流程

#### 7.4.1 连接流程

```
1. 枚举可用串口
2. 用户选择串口
3. 点击"获取设备ID"
4. 发送 GET_DEVICE_ID 命令
5. 接收并显示设备ID
6. 连接成功
```

#### 7.4.2 参数设置流程

```
1. 选择电流源 (10μA/17μA)
2. 输入调整值（如需要）
3. 点击"电流源调整"按钮
4. 发送 SET_CURRENT_SRC 命令
5. 点击"存储参数"按钮
6. 发送 SAVE_PARAM 命令
7. 设置完成
```

---

## 八、数据存储设计

### 8.1 Flash存储分配

| 地址范围 | 大小 | 用途 |
|---|---|---|
| 0x08000000 - 0x0803FFFF | 256KB | 程序代码 |
| 0x08040000 - 0x0805FFFF | 128KB | 分度表存储 |
| 0x08060000 - 0x0807FFFF | 128KB | 用户参数 |

### 8.2 参数结构体

```c
// 用户参数结构体
typedef struct {
    uint32_t magic;             // 魔数 0x544D5032 ("TMP2")
    uint8_t current_source;     // 电流源选择 (0:10μA, 1:17μA)
    float current_adj_10uA;     // 10μA调整值
    float current_adj_17uA;     // 17μA调整值
    float temp_4mA;             // 4mA对应温度
    float temp_20mA;            // 20mA对应温度
    uint16_t crc;               // CRC校验
} UserParam_t;
```

### 8.3 分度表格式

```c
// 分度表结构
typedef struct {
    uint32_t magic;             // 魔数 0x54424C00 ("TBL")
    uint16_t point_count;       // 数据点数 (最大4871)
    float voltage[4871];        // 电压值数组 (mV)
    float temperature[4871];    // 温度值数组 (K)
    uint16_t crc;               // CRC校验
} TempTable_t;
```

### 8.4 Flash操作接口

```c
// Flash操作接口
HAL_StatusTypeDef BSP_Flash_Write(uint32_t addr, uint8_t *data, uint32_t len);
HAL_StatusTypeDef BSP_Flash_Read(uint32_t addr, uint8_t *data, uint32_t len);
HAL_StatusTypeDef BSP_Flash_Erase(uint32_t addr, uint32_t size);

// 参数管理接口
void APP_Param_Load(void);
void APP_Param_Save(void);
void APP_Param_SetDefault(void);
```

---

## 九、开发计划

### 9.1 开发阶段

| 阶段 | 内容 | 预计时间 |
|---|---|---|
| **阶段1** | 基础框架搭建 | 2天 |
| - | 工程创建、时钟配置、GPIO初始化 | |
| - | SPI驱动、UART驱动、USB驱动 | |
| **阶段2** | 核心功能开发 | 5天 |
| - | ADC采集驱动开发 | |
| - | DAC输出驱动开发 | |
| - | 温度测量算法实现 | |
| - | 分度表查表算法 | |
| **阶段3** | 显示与通讯 | 3天 |
| - | LCD串口屏驱动 | |
| - | USB CDC通讯 | |
| - | 命令解析处理 | |
| **阶段4** | 参数管理 | 2天 |
| - | Flash读写驱动 | |
| - | 参数存储与加载 | |
| - | 分度表下载功能 | |
| **阶段5** | 上位机开发 | 3天 |
| - | 界面设计 | |
| - | 串口通讯 | |
| - | 功能实现 | |
| **阶段6** | 测试与调试 | 3天 |
| - | 单元测试 | |
| - | 集成测试 | |
| - | 系统联调 | |
| **总计** | - | **18天** |

### 9.2 开发环境

| 项目 | 工具/版本 |
|---|---|
| IDE | Keil MDK V5.37 / STM32CubeIDE |
| 编译器 | ARM Compiler V6 |
| 调试器 | ST-Link V2 |
| 代码管理 | Git |
| 文档 | Markdown |

### 9.3 测试计划

| 测试项 | 测试内容 | 通过标准 |
|---|---|---|
| 电源测试 | 各路电源电压 | 误差<5% |
| ADC测试 | 采集精度、稳定性 | 24位有效 |
| DAC测试 | 输出精度 | 误差<0.1% |
| 温度测试 | 测量精度 | 误差<±1℃ |
| 4-20mA测试 | 输出线性度 | 误差<0.5% |
| LCD测试 | 显示正常 | 无乱码 |
| USB测试 | 通讯正常 | 无丢包 |
| Flash测试 | 读写正确 | 100%正确 |

---

## 十、附录

### 10.1 参考文档

| 文档 | 描述 |
|---|---|
| STM32F411xC/E Datasheet | MCU数据手册 |
| STM32F411xC/E Reference Manual | MCU参考手册 |
| 超低温温度测量模块_原理图设计文档.md | 硬件原理图分析 |
| 超低温温度测量模块_使用说明书.md | 产品使用说明 |
| 淘晶驰串口屏开发指南 | LCD开发资料 |

### 10.2 缩略语

| 缩略语 | 全称 |
|---|---|
| ADC | Analog-to-Digital Converter |
| DAC | Digital-to-Analog Converter |
| SPI | Serial Peripheral Interface |
| UART | Universal Asynchronous Receiver/Transmitter |
| USB CDC | USB Communications Device Class |
| HAL | Hardware Abstraction Layer |
| BSP | Board Support Package |

---

*文档版本：V1.0*
*创建日期：2025年12月18日*
*状态：初稿*

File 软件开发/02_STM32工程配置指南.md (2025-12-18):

# STM32工程配置指南

## 文档信息

| 项目 | 内容 |
|---|---|
| 产品名称 | Ultra-TM02 超低温温度测量模块 |
| MCU型号 | STM32F411RET6 |
| 开发工具 | STM32CubeMX / Keil MDK |
| 版本 | V1.0 |
| 创建日期 | 2025年12月18日 |

---

## 一、STM32CubeMX配置

### 1.1 新建工程

1. 打开STM32CubeMX
2. 选择芯片：**STM32F411RET6**
3. 创建新工程

### 1.2 时钟配置

#### RCC设置

| 参数 | 配置 |
|---|---|
| HSE | Crystal/Ceramic Resonator (12MHz) |
| LSE | Disable |
| PLL Source | HSE |

#### 时钟树配置

```
HSE (12MHz)
    │
    └─→ PLL ─→ SYSCLK (100MHz)
              │
              ├─→ AHB (100MHz)
              │   ├─→ APB1 (50MHz)  → I2C, SPI2/3, USART2
              │   └─→ APB2 (100MHz) → SPI1, USART6, GPIO
              │
              └─→ USB (48MHz)
```

**PLL配置参数**：
| 参数 | 值 |
|---|-----|
| PLLM | 6 |
| PLLN | 100 |
| PLLP | 2 |
| PLLQ | 4 |

### 1.3 GPIO配置

#### 输出引脚

| 引脚 | 功能 | 模式 | 初始值 |
|---|---|---|---|
| PA4 | ADC1_CS | Output Push-Pull | High |
| PA8 | DAC1_CS | Output Push-Pull | High |
| PA9 | DAC2_CS | Output Push-Pull | High |
| PA10 | DAC1_LOAD | Output Push-Pull | High |
| PB0 | DAC2_LOAD | Output Push-Pull | High |
| PC13 | LED1 | Output Push-Pull | High |

#### 输入引脚

| 引脚 | 功能 | 模式 |
|---|---|---|
| PA0 | ADC_DRDY | Input (External Interrupt) |

### 1.4 SPI配置

#### SPI1 (ADC/DAC通讯)

| 参数 | 配置 |
|---|---|
| Mode | Full-Duplex Master |
| Hardware NSS | Disable |
| Frame Format | Motorola |
| Data Size | 8 bits |
| First Bit | MSB First |
| Prescaler | 8 (PCLK2/8 = 12.5MHz) |
| CPOL | High |
| CPHA | 2 Edge |
| CRC | Disable |

**引脚分配**：
| 引脚 | 功能 |
|---|---|
| PA5 | SPI1_SCK |
| PA6 | SPI1_MISO |
| PA7 | SPI1_MOSI |

### 1.5 UART配置

#### USART6 (LCD串口屏)

| 参数 | 配置 |
|---|---|
| Mode | Asynchronous |
| Baud Rate | 115200 |
| Word Length | 8 bits |
| Parity | None |
| Stop Bits | 1 |
| Data Direction | Receive and Transmit |
| Over Sampling | 16 |

**引脚分配**：
| 引脚 | 功能 |
|---|---|
| PC6 | USART6_TX |
| PC7 | USART6_RX |

**DMA配置**（可选）：
| DMA | Stream | Channel | Direction |
|-----|---|---|---|
| DMA2 | Stream6 | Channel5 | TX |
| DMA2 | Stream1 | Channel5 | RX |

### 1.6 USB配置

#### USB OTG FS

| 参数 | 配置 |
|---|---|
| Mode | Device Only |
| Device Class | CDC (Virtual COM Port) |
| Speed | Full Speed |

**引脚分配**：
| 引脚 | 功能 |
|---|---|
| PA11 | USB_OTG_FS_DM |
| PA12 | USB_OTG_FS_DP |

### 1.7 中断配置

#### NVIC设置

| 中断源 | 优先级 | 状态 |
|---|---|---|
| EXTI0 | 5 | Enable (ADC_DRDY) |
| SPI1 | 6 | Enable |
| USART6 | 7 | Enable |
| USB_OTG_FS | 8 | Enable |
| SysTick | 0 | Enable |

### 1.8 工程生成

#### 工程设置

| 参数 | 配置 |
|---|---|
| Project Name | Ultra_TM02 |
| Project Location | 自定义路径 |
| Toolchain/IDE | MDK-ARM V5 |
| Min Heap Size | 0x400 |
| Min Stack Size | 0x800 |

#### 代码生成选项

- ☑ Generate peripheral initialization as a pair of '.c/.h' files
- ☑ Keep User Code when re-generating
- ☑ Delete previously generated files when not re-generated

---

## 二、Keil MDK工程配置

### 2.1 工程结构

```
Ultra_TM02/
├── MDK-ARM/
│   └── Ultra_TM02.uvprojx      # Keil工程文件
├── Core/
│   ├── Inc/
│   └── Src/
├── Drivers/
│   ├── STM32F4xx_HAL_Driver/
│   └── CMSIS/
├── Middlewares/
│   └── ST/
│       └── STM32_USB_Device_Library/
└── USB_DEVICE/
    ├── App/
    └── Target/
```

### 2.2 编译器设置

| 参数 | 配置 |
|---|---|
| ARM Compiler | Version 6 |
| Optimization | -O2 |
| Debug Format | DWARF |
| C99 Mode | Enable |

### 2.3 链接器设置

| 参数 | 值 |
|---|-----|
| R/O Base | 0x08000000 |
| R/W Base | 0x20000000 |
| ROM Size | 0x80000 (512KB) |
| RAM Size | 0x20000 (128KB) |

### 2.4 调试器配置

#### ST-Link Debugger

| 参数 | 配置 |
|---|---|
| Debug Adapter | ST-Link Debugger |
| Port | SW |
| Max Clock | 4MHz |
| Reset | Autodetect |

#### Flash Download

| 参数 | 配置 |
|---|---|
| Flash Algorithm | STM32F4xx 512KB Flash |
| Programming Algorithm | 0x08000000 - 0x0807FFFF |
| RAM for Algorithm | 0x20000000 |

---

## 三、外设初始化代码

### 3.1 GPIO初始化

```c
// bsp_gpio.c

#include "bsp_gpio.h"

// GPIO引脚定义
#define ADC1_CS_PIN         GPIO_PIN_4
#define ADC1_CS_PORT        GPIOA
#define DAC1_CS_PIN         GPIO_PIN_8
#define DAC1_CS_PORT        GPIOA
#define DAC2_CS_PIN         GPIO_PIN_9
#define DAC2_CS_PORT        GPIOA
#define DAC1_LOAD_PIN       GPIO_PIN_10
#define DAC1_LOAD_PORT      GPIOA
#define DAC2_LOAD_PIN       GPIO_PIN_0
#define DAC2_LOAD_PORT      GPIOB
#define LED1_PIN            GPIO_PIN_13
#define LED1_PORT           GPIOC

/**
 * @brief  GPIO初始化
 * @param  无
 * @retval 无
 */
void BSP_GPIO_Init(void)
{
    GPIO_InitTypeDef GPIO_InitStruct = {0};
    
    // 使能GPIO时钟
    __HAL_RCC_GPIOA_CLK_ENABLE();
    __HAL_RCC_GPIOB_CLK_ENABLE();
    __HAL_RCC_GPIOC_CLK_ENABLE();
    
    // 配置输出引脚
    GPIO_InitStruct.Mode = GPIO_MODE_OUTPUT_PP;
    GPIO_InitStruct.Pull = GPIO_NOPULL;
    GPIO_InitStruct.Speed = GPIO_SPEED_FREQ_HIGH;
    
    // ADC1_CS
    GPIO_InitStruct.Pin = ADC1_CS_PIN;
    HAL_GPIO_Init(ADC1_CS_PORT, &GPIO_InitStruct);
    HAL_GPIO_WritePin(ADC1_CS_PORT, ADC1_CS_PIN, GPIO_PIN_SET);
    
    // DAC1_CS
    GPIO_InitStruct.Pin = DAC1_CS_PIN;
    HAL_GPIO_Init(DAC1_CS_PORT, &GPIO_InitStruct);
    HAL_GPIO_WritePin(DAC1_CS_PORT, DAC1_CS_PIN, GPIO_PIN_SET);
    
    // DAC2_CS
    GPIO_InitStruct.Pin = DAC2_CS_PIN;
    HAL_GPIO_Init(DAC2_CS_PORT, &GPIO_InitStruct);
    HAL_GPIO_WritePin(DAC2_CS_PORT, DAC2_CS_PIN, GPIO_PIN_SET);
    
    // DAC1_LOAD
    GPIO_InitStruct.Pin = DAC1_LOAD_PIN;
    HAL_GPIO_Init(DAC1_LOAD_PORT, &GPIO_InitStruct);
    HAL_GPIO_WritePin(DAC1_LOAD_PORT, DAC1_LOAD_PIN, GPIO_PIN_SET);
    
    // DAC2_LOAD
    GPIO_InitStruct.Pin = DAC2_LOAD_PIN;
    HAL_GPIO_Init(DAC2_LOAD_PORT, &GPIO_InitStruct);
    HAL_GPIO_WritePin(DAC2_LOAD_PORT, DAC2_LOAD_PIN, GPIO_PIN_SET);
    
    // LED1
    GPIO_InitStruct.Pin = LED1_PIN;
    HAL_GPIO_Init(LED1_PORT, &GPIO_InitStruct);
    HAL_GPIO_WritePin(LED1_PORT, LED1_PIN, GPIO_PIN_SET);
}

/**
 * @brief  设置ADC片选
 * @param  state: 0=选中, 1=取消
 */
void BSP_ADC_CS(uint8_t state)
{
    HAL_GPIO_WritePin(ADC1_CS_PORT, ADC1_CS_PIN, 
                      state ? GPIO_PIN_SET : GPIO_PIN_RESET);
}

/**
 * @brief  设置DAC1片选
 * @param  state: 0=选中, 1=取消
 */
void BSP_DAC1_CS(uint8_t state)
{
    HAL_GPIO_WritePin(DAC1_CS_PORT, DAC1_CS_PIN, 
                      state ? GPIO_PIN_SET : GPIO_PIN_RESET);
}

/**
 * @brief  设置DAC2片选
 * @param  state: 0=选中, 1=取消
 */
void BSP_DAC2_CS(uint8_t state)
{
    HAL_GPIO_WritePin(DAC2_CS_PORT, DAC2_CS_PIN, 
                      state ? GPIO_PIN_SET : GPIO_PIN_RESET);
}

/**
 * @brief  LED控制
 * @param  state: 0=灭, 1=亮
 */
void BSP_LED_Set(uint8_t state)
{
    HAL_GPIO_WritePin(LED1_PORT, LED1_PIN, 
                      state ? GPIO_PIN_RESET : GPIO_PIN_SET);
}

/**
 * @brief  LED翻转
 */
void BSP_LED_Toggle(void)
{
    HAL_GPIO_TogglePin(LED1_PORT, LED1_PIN);
}
```

### 3.2 SPI初始化

```c
// bsp_spi.c

#include "bsp_spi.h"

SPI_HandleTypeDef hspi1;

/**
 * @brief  SPI1初始化
 * @param  无
 * @retval 无
 */
void BSP_SPI_Init(void)
{
    // SPI1配置
    hspi1.Instance = SPI1;
    hspi1.Init.Mode = SPI_MODE_MASTER;
    hspi1.Init.Direction = SPI_DIRECTION_2LINES;
    hspi1.Init.DataSize = SPI_DATASIZE_8BIT;
    hspi1.Init.CLKPolarity = SPI_POLARITY_HIGH;
    hspi1.Init.CLKPhase = SPI_PHASE_2EDGE;
    hspi1.Init.NSS = SPI_NSS_SOFT;
    hspi1.Init.BaudRatePrescaler = SPI_BAUDRATEPRESCALER_8;
    hspi1.Init.FirstBit = SPI_FIRSTBIT_MSB;
    hspi1.Init.TIMode = SPI_TIMODE_DISABLE;
    hspi1.Init.CRCCalculation = SPI_CRCCALCULATION_DISABLE;
    
    if (HAL_SPI_Init(&hspi1) != HAL_OK)
    {
        Error_Handler();
    }
}

/**
 * @brief  SPI收发一个字节
 * @param  tx_data: 发送数据
 * @retval 接收数据
 */
uint8_t BSP_SPI_TransmitReceive(uint8_t tx_data)
{
    uint8_t rx_data = 0;
    HAL_SPI_TransmitReceive(&hspi1, &tx_data, &rx_data, 1, 100);
    return rx_data;
}

/**
 * @brief  SPI发送数据
 * @param  data: 数据指针
 * @param  len: 数据长度
 * @retval HAL状态
 */
HAL_StatusTypeDef BSP_SPI_Transmit(uint8_t *data, uint16_t len)
{
    return HAL_SPI_Transmit(&hspi1, data, len, 100);
}

/**
 * @brief  SPI接收数据
 * @param  data: 数据指针
 * @param  len: 数据长度
 * @retval HAL状态
 */
HAL_StatusTypeDef BSP_SPI_Receive(uint8_t *data, uint16_t len)
{
    return HAL_SPI_Receive(&hspi1, data, len, 100);
}
```

### 3.3 UART初始化

```c
// bsp_uart.c

#include "bsp_uart.h"

UART_HandleTypeDef huart6;

// 接收缓冲区
#define RX_BUFFER_SIZE  256
static uint8_t rx_buffer[RX_BUFFER_SIZE];
static volatile uint16_t rx_head = 0;
static volatile uint16_t rx_tail = 0;

/**
 * @brief  UART6初始化 (LCD串口屏)
 * @param  无
 * @retval 无
 */
void BSP_UART_Init(void)
{
    huart6.Instance = USART6;
    huart6.Init.BaudRate = 115200;
    huart6.Init.WordLength = UART_WORDLENGTH_8B;
    huart6.Init.StopBits = UART_STOPBITS_1;
    huart6.Init.Parity = UART_PARITY_NONE;
    huart6.Init.Mode = UART_MODE_TX_RX;
    huart6.Init.HwFlowCtl = UART_HWCONTROL_NONE;
    huart6.Init.OverSampling = UART_OVERSAMPLING_16;
    
    if (HAL_UART_Init(&huart6) != HAL_OK)
    {
        Error_Handler();
    }
    
    // 使能接收中断
    HAL_UART_Receive_IT(&huart6, &rx_buffer[0], 1);
}

/**
 * @brief  UART发送数据
 * @param  data: 数据指针
 * @param  len: 数据长度
 * @retval HAL状态
 */
HAL_StatusTypeDef BSP_UART_Transmit(uint8_t *data, uint16_t len)
{
    return HAL_UART_Transmit(&huart6, data, len, 1000);
}

/**
 * @brief  UART发送字符串
 * @param  str: 字符串指针
 * @retval 无
 */
void BSP_UART_SendString(const char *str)
{
    HAL_UART_Transmit(&huart6, (uint8_t *)str, strlen(str), 1000);
}

/**
 * @brief  检查是否有接收数据
 * @retval 可用数据字节数
 */
uint16_t BSP_UART_Available(void)
{
    return (rx_head - rx_tail + RX_BUFFER_SIZE) % RX_BUFFER_SIZE;
}

/**
 * @brief  读取一个字节
 * @retval 数据 (-1表示无数据)
 */
int BSP_UART_Read(void)
{
    if (rx_head == rx_tail) return -1;
    uint8_t data = rx_buffer[rx_tail];
    rx_tail = (rx_tail + 1) % RX_BUFFER_SIZE;
    return data;
}

/**
 * @brief  UART接收中断回调
 * @param  huart: UART句柄
 * @retval 无
 */
void HAL_UART_RxCpltCallback(UART_HandleTypeDef *huart)
{
    if (huart->Instance == USART6)
    {
        rx_head = (rx_head + 1) % RX_BUFFER_SIZE;
        HAL_UART_Receive_IT(&huart6, &rx_buffer[rx_head], 1);
    }
}
```

---

## 四、调试技巧

### 4.1 SWD调试

#### H1接口引脚定义

| H1引脚 | 信号 | ST-Link V2 |
|---|---|---|
| 1 | 3V3 | 3.3V (可选) |
| 2 | GND | GND |
| 3 | SWDIO | SWDIO |
| 4 | SWCLK | SWCLK |

#### 连接步骤

1. 按上表连接ST-Link V2到主板H1接口
2. 确认SWCLK、SWDIO、GND连接正确（最少需连接这3根线）
3. Keil中点击"Options for Target" → "Debug"
4. 选择"ST-Link Debugger" → "Settings"
5. 确认检测到芯片

> **注意**：H1引脚1在左侧，引脚4在右侧（面向接口看）

### 4.2 常见问题

| 问题 | 原因 | 解决方法 |
|---|---|---|
| 无法连接芯片 | SWD接线错误 | 检查接线，确认SWCLK、SWDIO |
| Flash下载失败 | 芯片被锁定 | 使用ST-Link Utility解锁 |
| 程序不运行 | 时钟配置错误 | 检查HSE晶振、PLL配置 |
| USB无法识别 | 48MHz时钟错误 | 检查PLLQ配置 |

### 4.3 串口调试

可使用printf重定向到USB CDC或UART：

```c
// 重定向printf到USB CDC
int fputc(int ch, FILE *f)
{
    CDC_Transmit_FS((uint8_t *)&ch, 1);
    return ch;
}

// 或重定向到UART
int fputc(int ch, FILE *f)
{
    HAL_UART_Transmit(&huart6, (uint8_t *)&ch, 1, 10);
    return ch;
}
```

---

*文档版本：V1.0*
*创建日期：2025年12月18日*

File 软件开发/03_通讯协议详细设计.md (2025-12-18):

# 通讯协议详细设计文档

## 文档信息

| 项目 | 内容 |
|---|---|
| 产品名称 | Ultra-TM02 超低温温度测量模块 |
| 文档类型 | 通讯协议设计 |
| 版本 | V1.0 |
| 创建日期 | 2025年12月18日 |

---

## 一、通讯概述

### 1.1 通讯接口

| 接口 | 类型 | 用途 |
|---|---|---|
| USB | CDC虚拟串口 | 上位机软件通讯 |
| USART6 | TTL串口 | LCD串口屏通讯 |

### 1.2 通讯参数

| 参数 | USB CDC | USART6 |
|---|---|---|
| 波特率 | 115200 | 115200 |
| 数据位 | 8 | 8 |
| 停止位 | 1 | 1 |
| 校验 | 无 | 无 |
| 流控 | 无 | 无 |

---

## 二、USB通讯协议

### 2.1 帧格式

```
┌──────┬──────┬──────┬──────────────┬──────┬──────┐
│ 帧头 │ 命令 │ 长度 │    数据      │ CRC  │ 帧尾 │
│ 0xAA │ CMD  │ LEN  │   DATA[N]    │ CRC16│ 0x55 │
│ 1字节│ 1字节│ 1字节│   N字节      │ 2字节│ 1字节│
└──────┴──────┴──────┴──────────────┴──────┴──────┘
```

### 2.2 字段说明

| 字段 | 长度 | 说明 |
|---|---|---|
| 帧头 | 1字节 | 固定0xAA |
| 命令 | 1字节 | 命令码 |
| 长度 | 1字节 | 数据域长度 (0-255) |
| 数据 | N字节 | 命令参数数据 |
| CRC | 2字节 | CRC16校验 (低字节在前) |
| 帧尾 | 1字节 | 固定0x55 |

### 2.3 CRC16计算

```c
/**
 * @brief  CRC16计算 (CCITT)
 * @param  data: 数据指针
 * @param  len: 数据长度
 * @retval CRC16值
 */
uint16_t CRC16_Calculate(uint8_t *data, uint16_t len)
{
    uint16_t crc = 0xFFFF;
    
    while (len--)
    {
        crc ^= *data++;
        for (int i = 0; i < 8; i++)
        {
            if (crc & 0x0001)
                crc = (crc >> 1) ^ 0xA001;
            else
                crc >>= 1;
        }
    }
    return crc;
}
```

---

## 三、命令定义

### 3.1 命令列表

| 命令码 | 名称 | 方向 | 描述 |
|---|---|---|---|
| 0x01 | GET_DEVICE_ID | 主机→设备 | 获取设备ID |
| 0x02 | GET_TEMPERATURE | 主机→设备 | 获取温度值 |
| 0x03 | GET_VOLTAGE | 主机→设备 | 获取电压值 |
| 0x04 | GET_CURRENT | 主机→设备 | 获取输出电流 |
| 0x05 | GET_STATUS | 主机→设备 | 获取设备状态 |
| 0x10 | SET_CURRENT_SRC | 主机→设备 | 设置电流源 |
| 0x11 | SET_CURRENT_ADJ_10UA | 主机→设备 | 设置10μA调整值 |
| 0x12 | SET_CURRENT_ADJ_17UA | 主机→设备 | 设置17μA调整值 |
| 0x20 | SET_4MA_TEMP | 主机→设备 | 设置4mA温度点 |
| 0x21 | SET_20MA_TEMP | 主机→设备 | 设置20mA温度点 |
| 0x30 | START_ACQ | 主机→设备 | 开始采集 |
| 0x31 | STOP_ACQ | 主机→设备 | 停止采集 |
| 0x40 | LOAD_TABLE_START | 主机→设备 | 分度表下载开始 |
| 0x41 | LOAD_TABLE_DATA | 主机→设备 | 分度表数据包 |
| 0x42 | LOAD_TABLE_END | 主机→设备 | 分度表下载结束 |
| 0x50 | SAVE_PARAM | 主机→设备 | 保存参数 |
| 0x51 | LOAD_PARAM | 主机→设备 | 加载参数 |
| 0x52 | RESET_DEFAULT | 主机→设备 | 恢复默认 |
| 0x80 | ACK | 设备→主机 | 确认响应 |
| 0x81 | NACK | 设备→主机 | 否定响应 |
| 0xF0 | DATA_REPORT | 设备→主机 | 数据主动上报 |

### 3.2 响应状态码

| 状态码 | 说明 |
|---|---|
| 0x00 | 成功 |
| 0x01 | 命令无效 |
| 0x02 | 参数错误 |
| 0x03 | CRC错误 |
| 0x04 | 忙 |
| 0x05 | Flash写入失败 |
| 0x06 | 分度表错误 |

---

## 四、命令详细说明

### 4.1 获取设备ID (0x01)

**请求帧：**
```
AA 01 00 [CRC_L] [CRC_H] 55
```

**响应帧：**
```
AA 01 10 [16字节设备ID] [CRC_L] [CRC_H] 55
```

**设备ID格式：**
```
TM02-XXXXXXXX (16字节ASCII)
```

---

### 4.2 获取温度值 (0x02)

**请求帧：**
```
AA 02 00 [CRC_L] [CRC_H] 55
```

**响应帧：**
```
AA 02 04 [温度值float, 4字节] [CRC_L] [CRC_H] 55
```

**温度值格式：**
- 4字节IEEE754单精度浮点数
- 低字节在前 (Little-Endian)
- 单位：℃

**示例：**
```
温度 = 25.123℃
float值: 0x41C8FBE7
响应: AA 02 04 E7 FB C8 41 [CRC] 55
```

---

### 4.3 获取电压值 (0x03)

**请求帧：**
```
AA 03 00 [CRC_L] [CRC_H] 55
```

**响应帧：**
```
AA 03 04 [电压值float, 4字节] [CRC_L] [CRC_H] 55
```

**电压值格式：**
- 单位：mV
- 二极管正向压降

---

### 4.4 获取输出电流 (0x04)

**请求帧：**
```
AA 04 00 [CRC_L] [CRC_H] 55
```

**响应帧：**
```
AA 04 04 [电流值float, 4字节] [CRC_L] [CRC_H] 55
```

**电流值格式：**
- 单位：mA
- 范围：4.00~20.00 mA

---

### 4.5 获取设备状态 (0x05)

**请求帧：**
```
AA 05 00 [CRC_L] [CRC_H] 55
```

**响应帧：**
```
AA 05 08 [状态数据, 8字节] [CRC_L] [CRC_H] 55
```

**状态数据格式：**
| 偏移 | 长度 | 说明 |
|---|---|---|
| 0 | 1字节 | 运行状态 (0:停止, 1:采集中) |
| 1 | 1字节 | 电流源选择 (0:10μA, 1:17μA) |
| 2 | 1字节 | 探头状态 (0:正常, 1:断开, 2:短路) |
| 3 | 1字节 | 保留 |
| 4 | 4字节 | 采集计数 |

---

### 4.6 设置电流源 (0x10)

**请求帧：**
```
AA 10 01 [电流源] [CRC_L] [CRC_H] 55
```

**参数：**
| 值 | 说明 |
|-----|---|
| 0x00 | 10μA电流源 |
| 0x01 | 17μA电流源 |

**响应帧：**
```
AA 80 01 [状态码] [CRC_L] [CRC_H] 55
```

---

### 4.7 设置10μA调整值 (0x11)

**请求帧：**
```
AA 11 04 [调整值float, 4字节] [CRC_L] [CRC_H] 55
```

**参数：**
- 调整值单位：μA
- 范围：-1.0 ~ +1.0 μA

**响应帧：**
```
AA 80 01 [状态码] [CRC_L] [CRC_H] 55
```

---

### 4.8 设置17μA调整值 (0x12)

**请求帧：**
```
AA 12 04 [调整值float, 4字节] [CRC_L] [CRC_H] 55
```

**参数：**
- 调整值单位：μA
- 范围：-1.0 ~ +1.0 μA

**响应帧：**
```
AA 80 01 [状态码] [CRC_L] [CRC_H] 55
```

---

### 4.9 设置4mA温度点 (0x20)

**请求帧：**
```
AA 20 04 [温度值float, 4字节] [CRC_L] [CRC_H] 55
```

**参数：**
- 温度单位：℃
- 表示4mA输出对应的温度值

**响应帧：**
```
AA 80 01 [状态码] [CRC_L] [CRC_H] 55
```

---

### 4.10 设置20mA温度点 (0x21)

**请求帧：**
```
AA 21 04 [温度值float, 4字节] [CRC_L] [CRC_H] 55
```

**参数：**
- 温度单位：℃
- 表示20mA输出对应的温度值

**响应帧：**
```
AA 80 01 [状态码] [CRC_L] [CRC_H] 55
```

---

### 4.11 开始采集 (0x30)

**请求帧：**
```
AA 30 00 [CRC_L] [CRC_H] 55
```

**响应帧：**
```
AA 80 01 [状态码] [CRC_L] [CRC_H] 55
```

**说明：**
- 开始采集后，设备以1Hz频率采集温度
- 可通过主动上报或轮询获取数据

---

### 4.12 停止采集 (0x31)

**请求帧：**
```
AA 31 00 [CRC_L] [CRC_H] 55
```

**响应帧：**
```
AA 80 01 [状态码] [CRC_L] [CRC_H] 55
```

---

### 4.13 分度表下载开始 (0x40)

**请求帧：**
```
AA 40 04 [总点数uint16] [总包数uint16] [CRC_L] [CRC_H] 55
```

**参数：**
| 偏移 | 长度 | 说明 |
|---|---|---|
| 0 | 2字节 | 分度表点数 (最大4871) |
| 2 | 2字节 | 数据包总数 |

**响应帧：**
```
AA 80 01 [状态码] [CRC_L] [CRC_H] 55
```

---

### 4.14 分度表数据包 (0x41)

**请求帧：**
```
AA 41 [LEN] [包序号uint16] [数据...] [CRC_L] [CRC_H] 55
```

**数据格式：**
- 每个数据点：电压(4字节float) + 温度(4字节float) = 8字节
- 每包最多传输32个点 (256字节)

**响应帧：**
```
AA 80 01 [状态码] [CRC_L] [CRC_H] 55
```

---

### 4.15 分度表下载结束 (0x42)

**请求帧：**
```
AA 42 02 [CRC校验uint16] [CRC_L] [CRC_H] 55
```

**参数：**
- 整个分度表数据的CRC16校验值

**响应帧：**
```
AA 80 01 [状态码] [CRC_L] [CRC_H] 55
```

---

### 4.16 保存参数 (0x50)

**请求帧：**
```
AA 50 00 [CRC_L] [CRC_H] 55
```

**响应帧：**
```
AA 80 01 [状态码] [CRC_L] [CRC_H] 55
```

**说明：**
- 将当前参数保存到内部Flash
- 包括：电流源选择、调整值、4-20mA温度点

---

### 4.17 数据主动上报 (0xF0)

**上报帧（设备→主机）：**
```
AA F0 0C [数据, 12字节] [CRC_L] [CRC_H] 55
```

**数据格式：**
| 偏移 | 长度 | 说明 |
|---|---|---|
| 0 | 4字节 | 温度值 (float, ℃) |
| 4 | 4字节 | 电压值 (float, mV) |
| 8 | 4字节 | 输出电流 (float, mA) |

---

## 五、通讯实现代码

### 5.1 协议定义

```c
// protocol.h

#ifndef __PROTOCOL_H
#define __PROTOCOL_H

#include <stdint.h>

// 帧定义
#define FRAME_HEAD          0xAA
#define FRAME_TAIL          0x55
#define MAX_DATA_LEN        256

// 命令码定义
#define CMD_GET_DEVICE_ID       0x01
#define CMD_GET_TEMPERATURE     0x02
#define CMD_GET_VOLTAGE         0x03
#define CMD_GET_CURRENT         0x04
#define CMD_GET_STATUS          0x05
#define CMD_SET_CURRENT_SRC     0x10
#define CMD_SET_CURRENT_ADJ_10  0x11
#define CMD_SET_CURRENT_ADJ_17  0x12
#define CMD_SET_4MA_TEMP        0x20
#define CMD_SET_20MA_TEMP       0x21
#define CMD_START_ACQ           0x30
#define CMD_STOP_ACQ            0x31
#define CMD_LOAD_TABLE_START    0x40
#define CMD_LOAD_TABLE_DATA     0x41
#define CMD_LOAD_TABLE_END      0x42
#define CMD_SAVE_PARAM          0x50
#define CMD_LOAD_PARAM          0x51
#define CMD_RESET_DEFAULT       0x52
#define CMD_ACK                 0x80
#define CMD_NACK                0x81
#define CMD_DATA_REPORT         0xF0

// 状态码定义
#define STATUS_OK               0x00
#define STATUS_INVALID_CMD      0x01
#define STATUS_INVALID_PARAM    0x02
#define STATUS_CRC_ERROR        0x03
#define STATUS_BUSY             0x04
#define STATUS_FLASH_ERROR      0x05
#define STATUS_TABLE_ERROR      0x06

// 帧结构
typedef struct {
    uint8_t head;           // 帧头
    uint8_t cmd;            // 命令码
    uint8_t len;            // 数据长度
    uint8_t data[MAX_DATA_LEN];  // 数据
    uint16_t crc;           // CRC校验
    uint8_t tail;           // 帧尾
} Frame_t;

// 协议接口
void Protocol_Init(void);
void Protocol_Process(uint8_t *data, uint16_t len);
void Protocol_SendAck(uint8_t cmd, uint8_t status);
void Protocol_SendData(uint8_t cmd, uint8_t *data, uint8_t len);
void Protocol_ReportData(float temp, float voltage, float current);

#endif
```

### 5.2 协议处理

```c
// protocol.c

#include "protocol.h"
#include "app_temp.h"
#include "app_param.h"
#include "usbd_cdc_if.h"
#include <string.h>

// 接收缓冲区
static uint8_t rx_buf[512];
static uint16_t rx_index = 0;

// 解析状态
typedef enum {
    PARSE_HEAD,
    PARSE_CMD,
    PARSE_LEN,
    PARSE_DATA,
    PARSE_CRC_L,
    PARSE_CRC_H,
    PARSE_TAIL
} ParseState_t;

static ParseState_t parse_state = PARSE_HEAD;
static Frame_t rx_frame;
static uint16_t data_index = 0;

/**
 * @brief  协议初始化
 */
void Protocol_Init(void)
{
    rx_index = 0;
    parse_state = PARSE_HEAD;
}

/**
 * @brief  发送确认响应
 * @param  cmd: 原命令
 * @param  status: 状态码
 */
void Protocol_SendAck(uint8_t cmd, uint8_t status)
{
    uint8_t buf[8];
    uint16_t crc;
    
    buf[0] = FRAME_HEAD;
    buf[1] = CMD_ACK;
    buf[2] = 1;         // 数据长度
    buf[3] = status;    // 状态码
    
    // 计算CRC (命令+长度+数据)
    crc = CRC16_Calculate(&buf[1], 3);
    buf[4] = crc & 0xFF;
    buf[5] = (crc >> 8) & 0xFF;
    buf[6] = FRAME_TAIL;
    
    // 发送
    CDC_Transmit_FS(buf, 7);
}

/**
 * @brief  发送数据响应
 * @param  cmd: 命令码
 * @param  data: 数据指针
 * @param  len: 数据长度
 */
void Protocol_SendData(uint8_t cmd, uint8_t *data, uint8_t len)
{
    uint8_t buf[MAX_DATA_LEN + 6];
    uint16_t crc;
    uint16_t idx = 0;
    
    buf[idx++] = FRAME_HEAD;
    buf[idx++] = cmd;
    buf[idx++] = len;
    
    // 复制数据
    memcpy(&buf[idx], data, len);
    idx += len;
    
    // 计算CRC
    crc = CRC16_Calculate(&buf[1], len + 2);
    buf[idx++] = crc & 0xFF;
    buf[idx++] = (crc >> 8) & 0xFF;
    buf[idx++] = FRAME_TAIL;
    
    // 发送
    CDC_Transmit_FS(buf, idx);
}

/**
 * @brief  主动上报数据
 * @param  temp: 温度值
 * @param  voltage: 电压值
 * @param  current: 电流值
 */
void Protocol_ReportData(float temp, float voltage, float current)
{
    uint8_t data[12];
    
    memcpy(&data[0], &temp, 4);
    memcpy(&data[4], &voltage, 4);
    memcpy(&data[8], &current, 4);
    
    Protocol_SendData(CMD_DATA_REPORT, data, 12);
}

/**
 * @brief  处理接收到的帧
 * @param  frame: 帧指针
 */
static void ProcessFrame(Frame_t *frame)
{
    uint8_t data[16];
    float fval;
    
    switch (frame->cmd)
    {
        case CMD_GET_DEVICE_ID:
            // 返回设备ID
            strcpy((char*)data, "TM02-00000001");
            Protocol_SendData(CMD_GET_DEVICE_ID, data, 16);
            break;
            
        case CMD_GET_TEMPERATURE:
            // 返回温度值
            fval = APP_Temp_GetValue();
            Protocol_SendData(CMD_GET_TEMPERATURE, (uint8_t*)&fval, 4);
            break;
            
        case CMD_GET_VOLTAGE:
            // 返回电压值
            fval = APP_Temp_GetVoltage();
            Protocol_SendData(CMD_GET_VOLTAGE, (uint8_t*)&fval, 4);
            break;
            
        case CMD_SET_CURRENT_SRC:
            // 设置电流源
            if (frame->data[0] <= 1)
            {
                APP_Temp_SetCurrentSource(frame->data[0]);
                Protocol_SendAck(frame->cmd, STATUS_OK);
            }
            else
            {
                Protocol_SendAck(frame->cmd, STATUS_INVALID_PARAM);
            }
            break;
            
        case CMD_SET_CURRENT_ADJ_10:
            // 设置10μA调整值
            memcpy(&fval, frame->data, 4);
            APP_Param_SetCurrentAdj10(fval);
            Protocol_SendAck(frame->cmd, STATUS_OK);
            break;
            
        case CMD_SET_CURRENT_ADJ_17:
            // 设置17μA调整值
            memcpy(&fval, frame->data, 4);
            APP_Param_SetCurrentAdj17(fval);
            Protocol_SendAck(frame->cmd, STATUS_OK);
            break;
            
        case CMD_SET_4MA_TEMP:
            // 设置4mA温度点
            memcpy(&fval, frame->data, 4);
            APP_Param_Set4mATemp(fval);
            Protocol_SendAck(frame->cmd, STATUS_OK);
            break;
            
        case CMD_SET_20MA_TEMP:
            // 设置20mA温度点
            memcpy(&fval, frame->data, 4);
            APP_Param_Set20mATemp(fval);
            Protocol_SendAck(frame->cmd, STATUS_OK);
            break;
            
        case CMD_START_ACQ:
            // 开始采集
            APP_Temp_Start();
            Protocol_SendAck(frame->cmd, STATUS_OK);
            break;
            
        case CMD_STOP_ACQ:
            // 停止采集
            APP_Temp_Stop();
            Protocol_SendAck(frame->cmd, STATUS_OK);
            break;
            
        case CMD_SAVE_PARAM:
            // 保存参数
            if (APP_Param_Save() == 0)
                Protocol_SendAck(frame->cmd, STATUS_OK);
            else
                Protocol_SendAck(frame->cmd, STATUS_FLASH_ERROR);
            break;
            
        default:
            Protocol_SendAck(frame->cmd, STATUS_INVALID_CMD);
            break;
    }
}

/**
 * @brief  协议解析处理
 * @param  data: 接收数据指针
 * @param  len: 数据长度
 */
void Protocol_Process(uint8_t *data, uint16_t len)
{
    for (uint16_t i = 0; i < len; i++)
    {
        uint8_t byte = data[i];
        
        switch (parse_state)
        {
            case PARSE_HEAD:
                if (byte == FRAME_HEAD)
                {
                    rx_frame.head = byte;
                    parse_state = PARSE_CMD;
                }
                break;
                
            case PARSE_CMD:
                rx_frame.cmd = byte;
                parse_state = PARSE_LEN;
                break;
                
            case PARSE_LEN:
                rx_frame.len = byte;
                data_index = 0;
                if (byte > 0)
                    parse_state = PARSE_DATA;
                else
                    parse_state = PARSE_CRC_L;
                break;
                
            case PARSE_DATA:
                rx_frame.data[data_index++] = byte;
                if (data_index >= rx_frame.len)
                    parse_state = PARSE_CRC_L;
                break;
                
            case PARSE_CRC_L:
                rx_frame.crc = byte;
                parse_state = PARSE_CRC_H;
                break;
                
            case PARSE_CRC_H:
                rx_frame.crc |= ((uint16_t)byte << 8);
                parse_state = PARSE_TAIL;
                break;
                
            case PARSE_TAIL:
                if (byte == FRAME_TAIL)
                {
                    // 验证CRC
                    uint8_t crc_buf[MAX_DATA_LEN + 2];
                    crc_buf[0] = rx_frame.cmd;
                    crc_buf[1] = rx_frame.len;
                    memcpy(&crc_buf[2], rx_frame.data, rx_frame.len);
                    
                    uint16_t calc_crc = CRC16_Calculate(crc_buf, rx_frame.len + 2);
                    
                    if (calc_crc == rx_frame.crc)
                    {
                        // CRC正确，处理帧
                        ProcessFrame(&rx_frame);
                    }
                    else
                    {
                        // CRC错误
                        Protocol_SendAck(rx_frame.cmd, STATUS_CRC_ERROR);
                    }
                }
                parse_state = PARSE_HEAD;
                break;
        }
    }
}
```

---

## 六、LCD串口屏协议

### 6.1 淘晶驰串口屏指令格式

**指令格式：**
```
指令字符串 + 0xFF 0xFF 0xFF
```

### 6.2 常用指令

| 指令 | 说明 | 示例 |
|---|---|---|
| page | 切换页面 | `page 0` |
| t0.txt | 设置文本 | `t0.txt="Hello"` |
| n0.val | 设置数值 | `n0.val=123` |
| vis | 显示/隐藏 | `vis t0,1` |

### 6.3 LCD服务实现

```c
// svc_lcd.c

#include "svc_lcd.h"
#include "bsp_uart.h"
#include <stdio.h>
#include <string.h>

// 结束符
static const uint8_t lcd_end[] = {0xFF, 0xFF, 0xFF};

/**
 * @brief  发送LCD指令
 * @param  cmd: 指令字符串
 */
static void LCD_SendCmd(const char *cmd)
{
    BSP_UART_SendString(cmd);
    BSP_UART_Transmit((uint8_t*)lcd_end, 3);
}

/**
 * @brief  LCD初始化
 */
void SVC_LCD_Init(void)
{
    // 复位LCD
    LCD_SendCmd("rest");
    HAL_Delay(500);
    
    // 切换到主页面
    LCD_SendCmd("page 0");
}

/**
 * @brief  设置温度显示
 * @param  temp: 温度值 (℃)
 */
void SVC_LCD_SetTemperature(float temp)
{
    char buf[32];
    
    // 格式化温度字符串 (保留3位小数)
    sprintf(buf, "t_temp.txt=\"%.3f\"", temp);
    LCD_SendCmd(buf);
}

/**
 * @brief  设置电压显示
 * @param  voltage: 电压值 (mV)
 */
void SVC_LCD_SetVoltage(float voltage)
{
    char buf[32];
    
    sprintf(buf, "t_volt.txt=\"%.3f\"", voltage);
    LCD_SendCmd(buf);
}

/**
 * @brief  设置输出电流显示
 * @param  current: 电流值 (mA)
 */
void SVC_LCD_SetCurrent(float current)
{
    char buf[32];
    
    sprintf(buf, "t_curr.txt=\"%.2f\"", current);
    LCD_SendCmd(buf);
}

/**
 * @brief  设置状态显示
 * @param  status: 状态字符串
 */
void SVC_LCD_SetStatus(const char *status)
{
    char buf[64];
    
    sprintf(buf, "t_status.txt=\"%s\"", status);
    LCD_SendCmd(buf);
}

/**
 * @brief  设置电流源显示
 * @param  src: 0=10μA, 1=17μA
 */
void SVC_LCD_SetCurrentSource(uint8_t src)
{
    char buf[32];
    
    sprintf(buf, "t_src.txt=\"%s\"", src ? "17μA" : "10μA");
    LCD_SendCmd(buf);
}

/**
 * @brief  LCD更新 (周期调用)
 */
void SVC_LCD_Update(void)
{
    static uint32_t last_tick = 0;
    uint32_t tick = HAL_GetTick();
    
    // 1Hz更新
    if (tick - last_tick >= 1000)
    {
        last_tick = tick;
        
        // 更新温度
        SVC_LCD_SetTemperature(APP_Temp_GetValue());
        
        // 更新电压
        SVC_LCD_SetVoltage(APP_Temp_GetVoltage());
        
        // 更新电流
        SVC_LCD_SetCurrent(APP_Output_GetCurrent());
    }
}
```

---

*文档版本：V1.0*
*创建日期：2025年12月18日*

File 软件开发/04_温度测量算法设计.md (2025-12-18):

# 温度测量算法设计文档

## 文档信息

| 项目 | 内容 |
|---|---|
| 产品名称 | Ultra-TM02 超低温温度测量模块 |
| 文档类型 | 算法设计 |
| 版本 | V1.0 |
| 创建日期 | 2025年12月18日 |

---

## 一、测量原理

### 1.1 二极管温度测量原理

二极管的正向电压与温度呈现近似线性的负温度系数关系。当恒定电流流过二极管时，正向电压随温度变化而变化。

**基本公式：**
```
Vf = (kT/q) × ln(I/Is) + Rs × I

其中：
- Vf: 正向电压
- k: 玻尔兹曼常数 (1.38×10⁻²³ J/K)
- T: 绝对温度 (K)
- q: 电子电荷 (1.6×10⁻¹⁹ C)
- I: 正向电流
- Is: 反向饱和电流
- Rs: 串联电阻
```

### 1.2 温度系数

| 温度范围 | 典型温度系数 |
|---|---|
| 300K (27℃) | -2.0 mV/K |
| 77K (-196℃) | -2.2 mV/K |
| 4K (-269℃) | -2.5 mV/K |

### 1.3 测量方式

本模块采用**四线制差分测量**：

```
        恒流源 (10μA/17μA)
             │
     I+ ────┬────┐
             │     │
            ┌┴┐    │
  V+ ──────┤D │────┼────── V-
            └┬┘    │
     I- ────┴────┘
```

**四线制优点：**
- 消除引线电阻影响
- 提高测量精度
- 适合长距离传输

---

## 二、信号采集

### 2.1 ADC配置

| 参数 | 配置 |
|---|---|
| ADC类型 | 24位Sigma-Delta |
| 参考电压 | 6.5V (来自6.5VA电源轨) |
| 输入方式 | 差分输入 |
| 采样率 | 1 SPS |
| 增益 | 可编程 (1/2/4/8/16/32/64/128) |

> **注意**：参考电压值需根据实际硬件测量TP4 (6.5VA)确认。如测量值与6.5V有偏差，需在代码中调整ADC_VREF宏定义。

### 2.2 信号范围

| 温度范围 | 电压范围 (10μA) | 电压范围 (17μA) |
|---|---|---|
| 1.4K | ~1.6V | ~2.7V |
| 77K | ~1.0V | ~1.7V |
| 300K | ~0.5V | ~0.85V |
| 500K | ~0.3V | ~0.5V |

### 2.3 ADC读取代码

```c
// svc_adc.c

#include "svc_adc.h"
#include "bsp_spi.h"
#include "bsp_gpio.h"

// ADC寄存器定义
#define ADC_REG_STATUS      0x00
#define ADC_REG_CONFIG      0x01
#define ADC_REG_DATA        0x02

// 参考电压
#define ADC_VREF            6.5f
// ADC满量程
#define ADC_FULLSCALE       16777216.0f  // 2^24

static float adc_gain = 1.0f;

/**
 * @brief  ADC初始化
 */
void SVC_ADC_Init(void)
{
    // 配置ADC
    // 设置采样率、增益等
    uint8_t config[3];
    
    config[0] = 0x00;  // 配置寄存器地址
    config[1] = 0x04;  // 增益=1, 采样率=1SPS
    config[2] = 0x00;  // 其他配置
    
    BSP_ADC_CS(0);
    BSP_SPI_Transmit(config, 3);
    BSP_ADC_CS(1);
    
    adc_gain = 1.0f;
}

/**
 * @brief  读取ADC原始值
 * @retval 24位ADC原始值
 */
uint32_t SVC_ADC_ReadRaw(void)
{
    uint8_t rx_buf[3];
    uint32_t raw_value;
    
    // 等待转换完成
    while (!SVC_ADC_IsReady());
    
    // 读取数据寄存器
    BSP_ADC_CS(0);
    BSP_SPI_TransmitReceive(ADC_REG_DATA | 0x40);  // 读命令
    rx_buf[0] = BSP_SPI_TransmitReceive(0x00);
    rx_buf[1] = BSP_SPI_TransmitReceive(0x00);
    rx_buf[2] = BSP_SPI_TransmitReceive(0x00);
    BSP_ADC_CS(1);
    
    // 组合24位数据 (MSB first)
    raw_value = ((uint32_t)rx_buf[0] << 16) | 
                ((uint32_t)rx_buf[1] << 8) | 
                rx_buf[2];
    
    return raw_value;
}

/**
 * @brief  读取ADC电压值
 * @retval 电压值 (mV)
 */
float SVC_ADC_ReadVoltage(void)
{
    uint32_t raw = SVC_ADC_ReadRaw();
    float voltage;
    
    // 转换为电压
    // 假设差分输入，中点为Vref/2
    int32_t signed_raw = (int32_t)(raw - 0x800000);
    voltage = (float)signed_raw / ADC_FULLSCALE * ADC_VREF * 1000.0f / adc_gain;
    
    return voltage;  // 单位: mV
}

/**
 * @brief  检查ADC是否准备好
 * @retval 1=准备好, 0=忙
 */
uint8_t SVC_ADC_IsReady(void)
{
    // 读取DRDY引脚状态
    return (HAL_GPIO_ReadPin(GPIOA, GPIO_PIN_0) == GPIO_PIN_RESET);
}

/**
 * @brief  设置ADC增益
 * @param  gain: 增益值 (1/2/4/8/16/32/64/128)
 */
void SVC_ADC_SetGain(uint8_t gain)
{
    uint8_t config[2];
    uint8_t gain_bits;
    
    switch (gain)
    {
        case 1:   gain_bits = 0x00; adc_gain = 1.0f; break;
        case 2:   gain_bits = 0x01; adc_gain = 2.0f; break;
        case 4:   gain_bits = 0x02; adc_gain = 4.0f; break;
        case 8:   gain_bits = 0x03; adc_gain = 8.0f; break;
        case 16:  gain_bits = 0x04; adc_gain = 16.0f; break;
        case 32:  gain_bits = 0x05; adc_gain = 32.0f; break;
        case 64:  gain_bits = 0x06; adc_gain = 64.0f; break;
        case 128: gain_bits = 0x07; adc_gain = 128.0f; break;
        default:  gain_bits = 0x00; adc_gain = 1.0f; break;
    }
    
    config[0] = ADC_REG_CONFIG;
    config[1] = gain_bits;
    
    BSP_ADC_CS(0);
    BSP_SPI_Transmit(config, 2);
    BSP_ADC_CS(1);
}
```

---

## 三、数字滤波

### 3.1 滤波策略

为提高测量稳定性，采用多级滤波：

```
┌──────────┐    ┌──────────┐    ┌──────────┐    ┌──────────┐
│ ADC原始值 │───→│ 中值滤波  │───→│ 均值滤波  │───→│ 滑动平均  │───→ 输出
└──────────┘    └──────────┘    └──────────┘    └──────────┘
```

### 3.2 中值滤波

消除突发噪声和异常值：

```c
/**
 * @brief  中值滤波 (5点)
 * @param  data: 数据数组
 * @param  len: 数据长度 (需要>=5)
 * @retval 中值
 */
float MedianFilter(float *data, uint8_t len)
{
    float temp[5];
    float t;
    
    // 复制数据
    for (int i = 0; i < 5; i++)
        temp[i] = data[i];
    
    // 冒泡排序
    for (int i = 0; i < 4; i++)
    {
        for (int j = 0; j < 4 - i; j++)
        {
            if (temp[j] > temp[j + 1])
            {
                t = temp[j];
                temp[j] = temp[j + 1];
                temp[j + 1] = t;
            }
        }
    }
    
    // 返回中值
    return temp[2];
}
```

### 3.3 均值滤波

去除高频噪声：

```c
/**
 * @brief  均值滤波
 * @param  data: 数据数组
 * @param  len: 数据长度
 * @retval 均值
 */
float AverageFilter(float *data, uint8_t len)
{
    float sum = 0;
    
    for (int i = 0; i < len; i++)
        sum += data[i];
    
    return sum / len;
}
```

### 3.4 滑动平均滤波

平滑输出，减少抖动：

```c
// 滑动平均滤波器
typedef struct {
    float buffer[16];   // 缓冲区
    uint8_t index;      // 当前索引
    uint8_t count;      // 有效数据数
    float sum;          // 累加和
} MovingAvgFilter_t;

/**
 * @brief  滑动平均滤波初始化
 * @param  filter: 滤波器结构体
 */
void MovingAvgFilter_Init(MovingAvgFilter_t *filter)
{
    memset(filter->buffer, 0, sizeof(filter->buffer));
    filter->index = 0;
    filter->count = 0;
    filter->sum = 0;
}

/**
 * @brief  添加数据并获取滤波结果
 * @param  filter: 滤波器结构体
 * @param  value: 新数据
 * @retval 滤波后的值
 */
float MovingAvgFilter_Update(MovingAvgFilter_t *filter, float value)
{
    // 减去旧值
    filter->sum -= filter->buffer[filter->index];
    
    // 添加新值
    filter->buffer[filter->index] = value;
    filter->sum += value;
    
    // 更新索引
    filter->index = (filter->index + 1) & 0x0F;  // 取模16
    
    // 更新计数
    if (filter->count < 16)
        filter->count++;
    
    // 返回平均值
    return filter->sum / filter->count;
}
```

---

## 四、分度表查表

### 4.1 分度表格式

分度表存储在Flash中，格式如下：

```c
// 分度表数据点
typedef struct {
    float voltage;      // 电压值 (mV)
    float temperature;  // 温度值 (K)
} TablePoint_t;

// 分度表结构
typedef struct {
    uint32_t magic;             // 魔数 "TBL\0"
    uint16_t point_count;       // 数据点数
    uint16_t reserved;          // 保留
    TablePoint_t points[4871];  // 数据点数组
    uint16_t crc;               // CRC校验
} TempTable_t;
```

### 4.2 线性插值算法

```c
// 分度表指针 (指向Flash)
static TempTable_t *p_table = (TempTable_t*)0x08040000;

/**
 * @brief  根据电压查表获取温度
 * @param  voltage: 电压值 (mV)
 * @retval 温度值 (K)
 */
float TempTable_Lookup(float voltage)
{
    int low = 0;
    int high = p_table->point_count - 1;
    int mid;
    
    // 边界检查
    if (voltage >= p_table->points[0].voltage)
        return p_table->points[0].temperature;
    
    if (voltage <= p_table->points[high].voltage)
        return p_table->points[high].temperature;
    
    // 二分查找
    while (high - low > 1)
    {
        mid = (low + high) / 2;
        
        if (voltage > p_table->points[mid].voltage)
            high = mid;
        else
            low = mid;
    }
    
    // 线性插值
    float v0 = p_table->points[low].voltage;
    float v1 = p_table->points[high].voltage;
    float t0 = p_table->points[low].temperature;
    float t1 = p_table->points[high].temperature;
    
    float temp = t0 + (voltage - v0) * (t1 - t0) / (v1 - v0);
    
    return temp;
}

/**
 * @brief  检查分度表有效性
 * @retval 0=有效, -1=无效
 */
int TempTable_Verify(void)
{
    // 检查魔数
    if (p_table->magic != 0x004C4254)  // "TBL\0"
        return -1;
    
    // 检查点数
    if (p_table->point_count == 0 || p_table->point_count > 4871)
        return -1;
    
    // 检查CRC (可选)
    // ...
    
    return 0;
}
```

### 4.3 温度单位转换

```c
/**
 * @brief  开尔文转摄氏度
 * @param  kelvin: 温度 (K)
 * @retval 温度 (℃)
 */
float Kelvin_to_Celsius(float kelvin)
{
    return kelvin - 273.15f;
}

/**
 * @brief  摄氏度转开尔文
 * @param  celsius: 温度 (℃)
 * @retval 温度 (K)
 */
float Celsius_to_Kelvin(float celsius)
{
    return celsius + 273.15f;
}
```

---

## 五、温度测量主流程

### 5.1 测量状态机

```c
// 测量状态
typedef enum {
    TEMP_STATE_IDLE,        // 空闲
    TEMP_STATE_CONVERT,     // 转换中
    TEMP_STATE_READ,        // 读取
    TEMP_STATE_CALC,        // 计算
    TEMP_STATE_OUTPUT       // 输出
} TempState_t;

// 测量结构体
typedef struct {
    TempState_t state;      // 状态
    uint8_t current_src;    // 电流源 (0:10μA, 1:17μA)
    float raw_voltage;      // 原始电压 (mV)
    float filtered_voltage; // 滤波后电压 (mV)
    float temperature_K;    // 温度 (K)
    float temperature_C;    // 温度 (℃)
    uint8_t running;        // 运行标志
} TempMeasure_t;

static TempMeasure_t g_temp;
static MovingAvgFilter_t g_filter;
```

### 5.2 测量流程实现

```c
// app_temp.c

#include "app_temp.h"
#include "svc_adc.h"
#include "svc_dac.h"
#include "svc_lcd.h"

// 采样缓冲
#define SAMPLE_COUNT    5
static float sample_buffer[SAMPLE_COUNT];
static uint8_t sample_index = 0;

/**
 * @brief  温度测量初始化
 */
void APP_Temp_Init(void)
{
    g_temp.state = TEMP_STATE_IDLE;
    g_temp.current_src = 0;  // 默认10μA
    g_temp.raw_voltage = 0;
    g_temp.filtered_voltage = 0;
    g_temp.temperature_K = 0;
    g_temp.temperature_C = 0;
    g_temp.running = 0;
    
    MovingAvgFilter_Init(&g_filter);
    
    // 初始化ADC
    SVC_ADC_Init();
    
    // 初始化DAC (设置电流源)
    SVC_DAC_Init();
    SVC_DAC_SetCurrentSource(CURRENT_SRC_10UA);
}

/**
 * @brief  开始测量
 */
void APP_Temp_Start(void)
{
    g_temp.running = 1;
    g_temp.state = TEMP_STATE_CONVERT;
    sample_index = 0;
}

/**
 * @brief  停止测量
 */
void APP_Temp_Stop(void)
{
    g_temp.running = 0;
    g_temp.state = TEMP_STATE_IDLE;
}

/**
 * @brief  设置电流源
 * @param  src: 0=10μA, 1=17μA
 */
void APP_Temp_SetCurrentSource(uint8_t src)
{
    g_temp.current_src = src;
    SVC_DAC_SetCurrentSource(src ? CURRENT_SRC_17UA : CURRENT_SRC_10UA);
}

/**
 * @brief  获取温度值
 * @retval 温度 (℃)
 */
float APP_Temp_GetValue(void)
{
    return g_temp.temperature_C;
}

/**
 * @brief  获取电压值
 * @retval 电压 (mV)
 */
float APP_Temp_GetVoltage(void)
{
    return g_temp.filtered_voltage;
}

/**
 * @brief  温度测量处理 (周期调用)
 */
void APP_Temp_Process(void)
{
    if (!g_temp.running)
        return;
    
    switch (g_temp.state)
    {
        case TEMP_STATE_CONVERT:
            // 等待ADC转换完成
            if (SVC_ADC_IsReady())
            {
                g_temp.state = TEMP_STATE_READ;
            }
            break;
            
        case TEMP_STATE_READ:
            // 读取ADC值
            g_temp.raw_voltage = SVC_ADC_ReadVoltage();
            
            // 存入缓冲
            sample_buffer[sample_index++] = g_temp.raw_voltage;
            
            if (sample_index >= SAMPLE_COUNT)
            {
                sample_index = 0;
                g_temp.state = TEMP_STATE_CALC;
            }
            else
            {
                g_temp.state = TEMP_STATE_CONVERT;
            }
            break;
            
        case TEMP_STATE_CALC:
        {
            // 中值滤波
            float median = MedianFilter(sample_buffer, SAMPLE_COUNT);
            
            // 滑动平均滤波
            g_temp.filtered_voltage = MovingAvgFilter_Update(&g_filter, median);
            
            // 查分度表
            g_temp.temperature_K = TempTable_Lookup(g_temp.filtered_voltage);
            
            // 单位转换
            g_temp.temperature_C = Kelvin_to_Celsius(g_temp.temperature_K);
            
            g_temp.state = TEMP_STATE_OUTPUT;
        }
            break;
            
        case TEMP_STATE_OUTPUT:
            // 更新4-20mA输出
            APP_Output_UpdateCurrent(g_temp.temperature_C);
            
            // 继续下一轮测量
            g_temp.state = TEMP_STATE_CONVERT;
            break;
            
        default:
            g_temp.state = TEMP_STATE_IDLE;
            break;
    }
}
```

---

## 六、4-20mA输出

### 6.1 输出转换

```c
// app_output.c

#include "app_output.h"
#include "svc_dac.h"
#include "app_param.h"

// 输出配置
static struct {
    float temp_4mA;     // 4mA对应温度
    float temp_20mA;    // 20mA对应温度
    float current;      // 当前输出电流
} g_output;

/**
 * @brief  输出初始化
 */
void APP_Output_Init(void)
{
    // 从参数加载
    g_output.temp_4mA = APP_Param_Get4mATemp();
    g_output.temp_20mA = APP_Param_Get20mATemp();
    g_output.current = 4.0f;
}

/**
 * @brief  根据温度更新输出电流
 * @param  temperature: 温度值 (℃)
 */
void APP_Output_UpdateCurrent(float temperature)
{
    float current;
    
    // 线性映射
    if (g_output.temp_20mA != g_output.temp_4mA)
    {
        current = 4.0f + (temperature - g_output.temp_4mA) * 16.0f / 
                  (g_output.temp_20mA - g_output.temp_4mA);
    }
    else
    {
        current = 12.0f;  // 中间值
    }
    
    // 限幅
    if (current < 4.0f) current = 4.0f;
    if (current > 20.0f) current = 20.0f;
    
    g_output.current = current;
    
    // 设置DAC输出
    SVC_DAC_Set420mA(current);
}

/**
 * @brief  获取当前输出电流
 * @retval 电流值 (mA)
 */
float APP_Output_GetCurrent(void)
{
    return g_output.current;
}

/**
 * @brief  设置4mA温度点
 * @param  temp: 温度 (℃)
 */
void APP_Output_Set4mATemp(float temp)
{
    g_output.temp_4mA = temp;
}

/**
 * @brief  设置20mA温度点
 * @param  temp: 温度 (℃)
 */
void APP_Output_Set20mATemp(float temp)
{
    g_output.temp_20mA = temp;
}
```

### 6.2 DAC输出控制

```c
// svc_dac.c

#include "svc_dac.h"
#include "bsp_spi.h"
#include "bsp_gpio.h"

// DAC满量程
#define DAC_FULLSCALE   65536.0f  // 16位DAC
// 参考电压
#define DAC_VREF        6.5f

// V/I转换系数 (mA/V)
#define VI_COEFFICIENT  2.5f  // 根据实际电路确定

/**
 * @brief  DAC初始化
 */
void SVC_DAC_Init(void)
{
    // 初始化DAC1 (电流源)
    // 初始化DAC2 (4-20mA)
}

/**
 * @brief  设置电流源
 * @param  src: CURRENT_SRC_10UA 或 CURRENT_SRC_17UA
 */
void SVC_DAC_SetCurrentSource(CurrentSource_e src)
{
    uint16_t dac_value;
    
    if (src == CURRENT_SRC_10UA)
    {
        // 设置10μA输出
        dac_value = (uint16_t)(10.0e-6f / VI_COEFFICIENT * DAC_FULLSCALE / DAC_VREF);
    }
    else
    {
        // 设置17μA输出
        dac_value = (uint16_t)(17.0e-6f / VI_COEFFICIENT * DAC_FULLSCALE / DAC_VREF);
    }
    
    // 写入DAC1
    SVC_DAC_WriteRaw(1, dac_value);
}

/**
 * @brief  设置4-20mA输出
 * @param  current_mA: 电流值 (mA)
 */
void SVC_DAC_Set420mA(float current_mA)
{
    // 电流限幅
    if (current_mA < 4.0f) current_mA = 4.0f;
    if (current_mA > 20.0f) current_mA = 20.0f;
    
    // 计算DAC值
    // 根据V/I电路设计确定转换关系
    float voltage = current_mA / VI_COEFFICIENT;
    uint16_t dac_value = (uint16_t)(voltage / DAC_VREF * DAC_FULLSCALE);
    
    // 写入DAC2
    SVC_DAC_WriteRaw(2, dac_value);
}

/**
 * @brief  写入DAC原始值
 * @param  channel: 通道 (1或2)
 * @param  value: 16位DAC值
 */
void SVC_DAC_WriteRaw(uint8_t channel, uint16_t value)
{
    uint8_t buf[3];
    
    buf[0] = 0x00;  // 写命令
    buf[1] = (value >> 8) & 0xFF;
    buf[2] = value & 0xFF;
    
    if (channel == 1)
    {
        BSP_DAC1_CS(0);
        BSP_SPI_Transmit(buf, 3);
        BSP_DAC1_CS(1);
        
        // 加载DAC
        BSP_DAC1_LOAD(0);
        HAL_Delay(1);
        BSP_DAC1_LOAD(1);
    }
    else
    {
        BSP_DAC2_CS(0);
        BSP_SPI_Transmit(buf, 3);
        BSP_DAC2_CS(1);
        
        // 加载DAC
        BSP_DAC2_LOAD(0);
        HAL_Delay(1);
        BSP_DAC2_LOAD(1);
    }
}
```

---

## 七、误差分析

### 7.1 误差来源

| 误差类型 | 来源 | 典型值 |
|---|---|---|
| ADC量化误差 | 24位ADC | < 0.001% |
| 参考电压漂移 | 基准芯片 | < 0.05% |
| 电流源误差 | DAC + V/I | < 0.05% |
| 分度表误差 | 插值计算 | < 0.01K |
| 噪声误差 | 环境干扰 | < 0.01K |

### 7.2 精度保证措施

1. **高精度参考电压**：使用0.05%精度基准
2. **多级滤波**：消除噪声影响
3. **差分输入**：消除共模干扰
4. **四线制测量**：消除引线电阻
5. **隔离设计**：减少地环路干扰

---

*文档版本：V1.0*
*创建日期：2025年12月18日*

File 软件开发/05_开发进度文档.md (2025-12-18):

# Ultra-TM02 超低温温度测量模块 - 开发进度文档

## 文档信息

| 项目 | 内容 |
|---|---|
| 产品名称 | Ultra-TM02 超低温温度测量模块 |
| 文档类型 | 开发进度跟踪 |
| 版本 | V2.0 |
| 创建日期 | 2025年12月18日 |
| 最后更新 | 2025年12月18日 |

---

## 一、项目配置核对结果

### 1.1 STM32CubeIDE配置完成情况

| 配置类别 | 配置项数 | 完成项数 | 符合率 | 状态 |
|---|---|---|---|---|
| MCU选型 | 1 | 1 | 100% | ✅ 完成 |
| 时钟配置 | 12 | 12 | 100% | ✅ 完成 |
| SPI1配置 | 10 | 10 | 100% | ✅ 完成 |
| USART6配置 | 7 | 7 | 100% | ✅ 完成 |
| USB配置 | 5 | 5 | 100% | ✅ 完成 |
| GPIO配置 | 9 | 9 | 100% | ✅ 完成 |
| NVIC配置 | 5 | 5 | 100% | ✅ 完成 |

**总体配置符合率：100%**

### 1.2 关键配置参数确认

- **MCU**: STM32F411RET6 (LQFP-64)
- **系统时钟**: 100MHz (HSE 12MHz → PLL)
- **USB时钟**: 48MHz
- **SPI1**: Full-Duplex Master, CPOL=High, CPHA=2Edge, 12.5MHz
- **USART6**: 115200bps, 8N1
- **USB**: Device Only, CDC虚拟串口

### 1.3 固件编译结果

```
✅ 编译成功 - 0错误，0警告
   text     data      bss      dec      hex  filename
  30844      252    10924    42020    a424  Ultra_TM02.elf
  
Flash使用: ~31KB / 512KB (6%)
RAM使用:   ~11KB / 128KB (9%)
```

---

## 二、软件开发进度

### 2.1 开发阶段总览

| 阶段 | 内容 | 预计时间 | 实际时间 | 状态 |
|---|---|---|---|---|
| 阶段0 | STM32CubeIDE配置 | 1天 | 1天 | ✅ 完成 |
| 阶段1 | BSP层开发 | 2天 | 1天 | ✅ 完成 |
| 阶段2 | Service层开发 | 3天 | 1天 | ✅ 完成 |
| 阶段3 | App层开发 | 4天 | 1天 | ✅ 完成 |
| 阶段4 | 固件编译验证 | 1天 | 1天 | ✅ 完成 |
| 阶段5 | 上位机开发 | 3天 | 1天 | ✅ 完成 |
| 阶段6 | 系统集成测试 | 2天 | - | ⏳ 待PCB到货 |

### 2.2 BSP层开发进度

| 模块 | 文件 | 功能描述 | 状态 |
|---|---|---|---|
| GPIO驱动 | bsp_gpio.c/h | 片选、LED、LOAD控制 | ✅ 完成 |
| SPI驱动 | bsp_spi.c/h | SPI通讯基础函数 | ✅ 完成 |
| UART驱动 | bsp_uart.c/h | LCD串口通讯 | ✅ 完成 |
| Flash驱动 | bsp_flash.c/h | 内部Flash读写 | ✅ 完成 |

### 2.3 Service层开发进度

| 模块 | 文件 | 功能描述 | 状态 |
|---|---|---|---|
| ADC服务 | svc_adc.c/h | 24位ADC采集 | ✅ 完成 |
| DAC服务 | svc_dac.c/h | 电流源/4-20mA输出 | ✅ 完成 |
| LCD服务 | svc_lcd.c/h | 串口屏显示 | ✅ 完成 |
| USB服务 | svc_usb.c/h | USB CDC通讯 | ✅ 完成 |

### 2.4 App层开发进度

| 模块 | 文件 | 功能描述 | 状态 |
|---|---|---|---|
| 温度测量 | app_temp.c/h | 温度采集、滤波、查表 | ✅ 完成 |
| 输出控制 | app_output.c/h | 4-20mA输出计算 | ✅ 完成 |
| 参数管理 | app_param.c/h | 参数存储、加载 | ✅ 完成 |
| 通讯处理 | app_comm.c/h | 协议解析、命令处理 | ✅ 完成 |

---

## 三、文件目录结构

```
Ultra_TM02/
├── Core/
│   ├── Inc/
│   │   ├── main.h
│   │   ├── stm32f4xx_hal_conf.h
│   │   └── stm32f4xx_it.h
│   └── Src/
│       ├── main.c
│       ├── stm32f4xx_it.c
│       └── system_stm32f4xx.c
├── BSP/
│   ├── Inc/
│   │   ├── bsp_gpio.h
│   │   ├── bsp_spi.h
│   │   ├── bsp_uart.h
│   │   └── bsp_flash.h
│   └── Src/
│       ├── bsp_gpio.c
│       ├── bsp_spi.c
│       ├── bsp_uart.c
│       └── bsp_flash.c
├── Service/
│   ├── Inc/
│   │   ├── svc_adc.h
│   │   ├── svc_dac.h
│   │   ├── svc_lcd.h
│   │   └── svc_usb.h
│   └── Src/
│       ├── svc_adc.c
│       ├── svc_dac.c
│       ├── svc_lcd.c
│       └── svc_usb.c
├── App/
│   ├── Inc/
│   │   ├── app_temp.h
│   │   ├── app_output.h
│   │   ├── app_param.h
│   │   └── app_comm.h
│   └── Src/
│       ├── app_temp.c
│       ├── app_output.c
│       ├── app_param.c
│       └── app_comm.c
├── Drivers/
├── Middlewares/
└── USB_DEVICE/
```

---

## 四、里程碑节点

| 里程碑 | 描述 | 计划日期 | 实际日期 | 状态 |
|---|---|---|---|---|
| M0 | 工程配置完成 | 2025-12-18 | 2025-12-18 | ✅ 完成 |
| M1 | BSP层完成 | 2025-12-18 | 2025-12-18 | ✅ 完成 |
| M2 | Service层完成 | 2025-12-18 | 2025-12-18 | ✅ 完成 |
| M3 | App层完成 | 2025-12-18 | 2025-12-18 | ✅ 完成 |
| M4 | 固件编译通过 | 2025-12-18 | 2025-12-18 | ✅ 完成 |
| M5 | 上位机开发完成 | 2025-12-18 | 2025-12-18 | ✅ 完成 |
| M6 | **PCB板到货** | 2025-12-18 | 2025-12-18 | ✅ **完成** |
| M7 | 系统联调 | - | - | ⏳ 待配件到货 |
| M8 | 项目交付 | - | - | ⏳ 待完成 |

---

## 五、问题跟踪

| 编号 | 问题描述 | 发现日期 | 状态 | 解决方案 |
|---|---|---|---|---|
| P001 | USB CDC包含路径问题 | 2025-12-18 | ✅ 已解决 | 使用extern声明替代include |
| P002 | 构建系统自动清理 | 2025-12-18 | ✅ 已解决 | 直接Build不做Clean |

---

## 六、更新日志

| 日期 | 版本 | 更新内容 | 更新人 |
|---|---|---|---|
| 2025-12-18 | V1.0 | 创建文档，完成配置核对 | AI |
| 2025-12-18 | V1.1 | 完成BSP层开发 (GPIO/SPI/UART/Flash) | AI |
| 2025-12-18 | V1.2 | 完成Service层开发 (ADC/DAC/LCD/USB) | AI |
| 2025-12-18 | V1.3 | 完成App层开发 (温度/输出/参数/通讯) | AI |
| 2025-12-18 | V1.4 | 完成main.c主程序整合 | AI |
| 2025-12-18 | V1.5 | 创建STM32CubeIDE工程配置步骤文档 | AI |
| 2025-12-18 | V1.6 | 固件编译通过 (0错误0警告) | AI |
| 2025-12-18 | V2.0 | 完成上位机软件开发 (TempDownloader) | AI |
| 2025-12-18 | V2.1 | **PCB板制作完成到货**，SMT贴片完成 | AI |

---

## 七、已完成代码文件清单

### 7.1 BSP层 (板级支持包)

| 文件 | 路径 | 行数 | 功能描述 |
|---|---|---|---|
| bsp_gpio.h | BSP/Inc/ | ~100 | GPIO控制头文件 |
| bsp_gpio.c | BSP/Src/ | ~160 | GPIO控制实现 |
| bsp_spi.h | BSP/Inc/ | ~70 | SPI通讯头文件 |
| bsp_spi.c | BSP/Src/ | ~80 | SPI通讯实现 |
| bsp_uart.h | BSP/Inc/ | ~90 | UART通讯头文件 |
| bsp_uart.c | BSP/Src/ | ~170 | UART通讯实现 |
| bsp_flash.h | BSP/Inc/ | ~110 | Flash操作头文件 |
| bsp_flash.c | BSP/Src/ | ~200 | Flash操作实现 |

### 7.2 Service层 (服务层)

| 文件 | 路径 | 行数 | 功能描述 |
|---|---|---|---|
| svc_adc.h | Service/Inc/ | ~120 | ADC采集服务头文件 |
| svc_adc.c | Service/Src/ | ~200 | ADC采集服务实现 |
| svc_dac.h | Service/Inc/ | ~100 | DAC输出服务头文件 |
| svc_dac.c | Service/Src/ | ~220 | DAC输出服务实现 |
| svc_lcd.h | Service/Inc/ | ~100 | LCD显示服务头文件 |
| svc_lcd.c | Service/Src/ | ~180 | LCD显示服务实现 |
| svc_usb.h | Service/Inc/ | ~80 | USB通讯服务头文件 |
| svc_usb.c | Service/Src/ | ~160 | USB通讯服务实现 |

### 7.3 App层 (应用层)

| 文件 | 路径 | 行数 | 功能描述 |
|---|---|---|---|
| app_temp.h | App/Inc/ | ~130 | 温度测量头文件 |
| app_temp.c | App/Src/ | ~340 | 温度测量实现 |
| app_output.h | App/Inc/ | ~90 | 4-20mA输出头文件 |
| app_output.c | App/Src/ | ~160 | 4-20mA输出实现 |
| app_param.h | App/Inc/ | ~110 | 参数管理头文件 |
| app_param.c | App/Src/ | ~220 | 参数管理实现 |
| app_comm.h | App/Inc/ | ~100 | 通讯协议头文件 |
| app_comm.c | App/Src/ | ~300 | 通讯协议实现 |

### 7.4 主程序

| 文件 | 路径 | 行数 | 功能描述 |
|---|---|---|---|
| main.c | Core/Src/ | ~215 | 主程序入口 |

**固件代码总行数统计**: 约 3,400 行

---

## 八、上位机软件开发进度
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

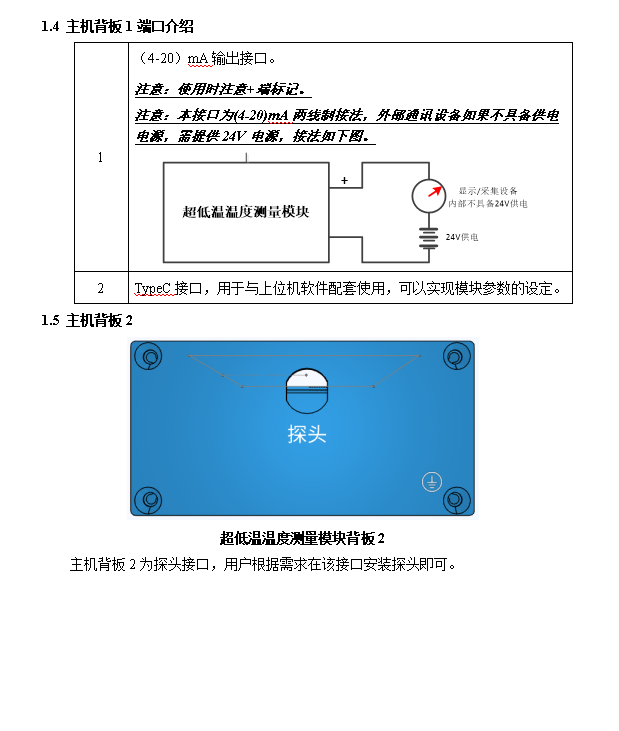
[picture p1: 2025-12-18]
UI_Screenshots/04_Chapter1_Panel_Intro_2.png

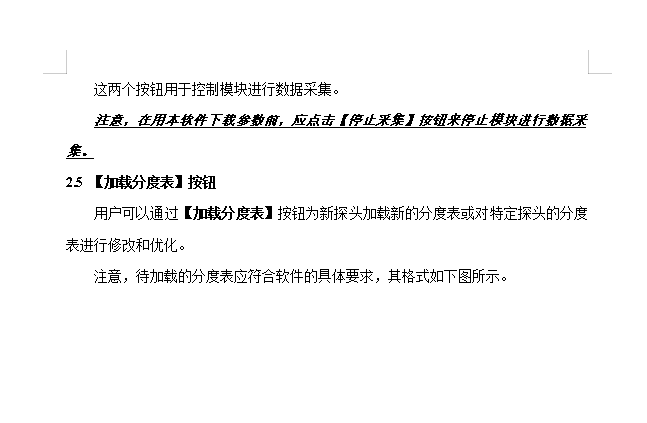
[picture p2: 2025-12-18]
UI_Screenshots/06_Chapter2_Software_UI_2.png

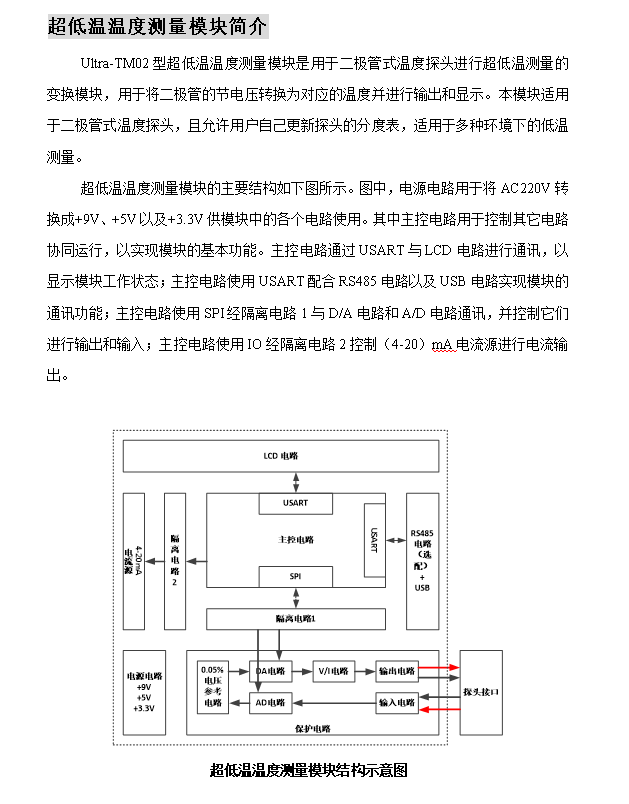
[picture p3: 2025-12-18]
UI_Screenshots/01_Module_Intro.png

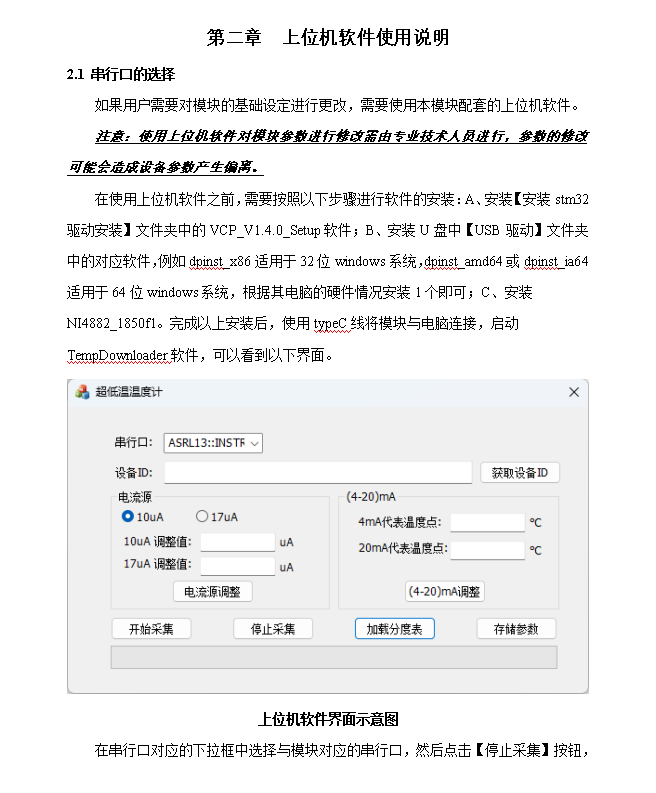
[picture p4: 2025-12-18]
UI_Screenshots/05_Chapter2_Software_UI_1.png

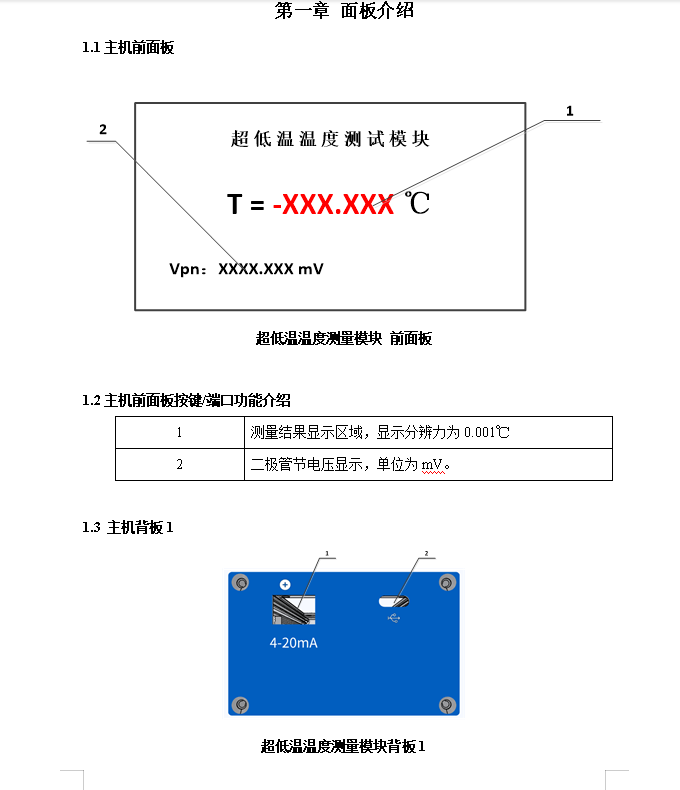
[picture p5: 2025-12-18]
UI_Screenshots/03_Chapter1_Panel_Intro_1.png

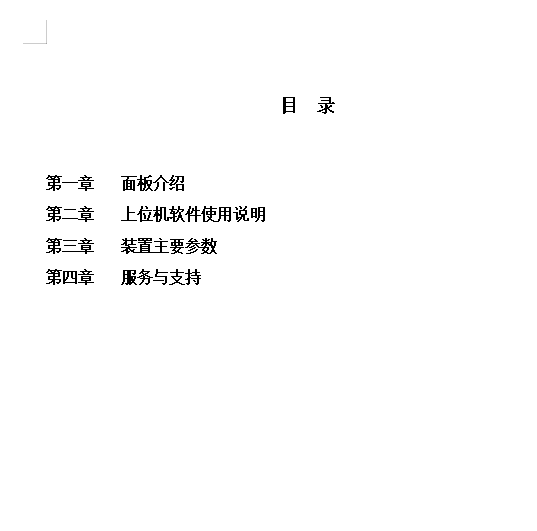
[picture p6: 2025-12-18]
UI_Screenshots/02_Table_of_Contents.png

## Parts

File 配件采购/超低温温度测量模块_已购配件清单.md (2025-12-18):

# 超低温温度测量模块 - 已购配件清单

## 文档信息

| 项目 | 内容 |
|---|---|
| 产品名称 | Ultra-TM02 超低温温度测量模块 |
| 文档类型 | 已购配件清单 |
| 创建日期 | 2025年12月18日 |
| 状态 | 采购完成 |

---

## 一、已购配件清单

| 序号 | 配件名称 | 规格型号 | 数量 | 单价 | 总价 | 购买状态 |
|---|---|---|---|---|---|---|
| 1 | 24V开关电源 | DC24V 2A | 1个 | ¥15~25 | ¥15~25 | ✅ 已购 |
| 2 | XH2.54-2P 端子线 | 单头 20cm | 3条 | ¥1~2 | ¥3~6 | ✅ 已购 |
| 3 | XH2.54-4P 端子线 | 单头 20cm | 1条 | ¥1~2 | ¥1~2 | ✅ 已购 |
| 4 | 3.5寸串口屏 | TJC4832T035 | 1个 | ¥80~120 | ¥80~120 | ✅ 已购 |
| 5 | 杜邦线 母对母 | 1P 20cm | 4根 | ¥0.5 | ¥2 | ✅ 已购 |
| 6 | Type-C数据线 | 绿联 USB2.0 1米 | 1条 | ¥10~15 | ¥10~15 | ✅ 已购 |
| 7 | ST-Link V2 下载器 | Risym STM32下载器 | 1个 | ¥13.38 | ¥13.38 | ✅ 已购 |
| 8 | 1N4148 二极管 | DO-35 直插 | 50个 | ¥5~8 | ¥5~8 | ✅ 已购 |
| 9 | 鳄鱼夹测试线 | 双头 彩色 | 2条 | ¥2~3 | ¥4~6 | ✅ 已购 |
| 10 | DC母座转端子线 | DC5.5×2.1转XH2.54-2P | 1条 | ¥3~5 | ¥3~5 | ✅ 已购 |
| 11 | 1.25转2.54转接线 | 1.25mm 4P转杜邦头 20cm | 1条 | ¥0.38 | ¥0.38 | ✅ 已购 |

**总计：约 ¥138~204**

---

## 二、配件详细说明

### 2.1 24V开关电源

| 项目 | 规格 |
|---|---|
| 输入电压 | AC 100-240V |
| 输出电压 | DC 24V |
| 输出电流 | 2A |
| 输出功率 | 48W |
| 接口类型 | DC头 (5.5×2.1mm) |

**用途**：为模块主板供电

**配合使用**：DC母座转端子线（已购，序号10）

---

### 2.2 XH2.54-2P 端子线

| 项目 | 规格 |
|---|---|
| 间距 | 2.54mm |
| 芯数 | 2P (2芯) |
| 线长 | 20cm |
| 类型 | 单头 (一端带端子，一端裸线) |

**用途**：
- 电源输入连接 (CN14)
- 4-20mA输出连接 (CN12, CN13)

**数量**：3条

---

### 2.3 XH2.54-4P 端子线

| 项目 | 规格 |
|---|---|
| 间距 | 2.54mm |
| 芯数 | 4P (4芯) |
| 线长 | 20cm |
| 类型 | 单头 (一端带端子，一端裸线) |

**用途**：温度探头接口连接 (U89)

**数量**：1条

---

### 2.4 3.5寸串口屏

| 项目 | 规格 |
|---|---|
| 型号 | TJC4832T035 |
| 品牌 | 淘晶驰 |
| 尺寸 | 3.5寸 |
| 分辨率 | 480×320 |
| 接口 | 2.54mm 排针 (4P) |
| 通讯 | UART 串口 TTL |
| 电压 | 5V |

**用途**：显示温度测量结果

**接线说明**：

| 屏幕引脚 | 主板引脚 | 说明 |
|---|---|---|
| VCC | 5V | 电源正 |
| GND | GND | 电源地 |
| TX | RX (PC7) | 屏幕发送 |
| RX | TX (PC6) | 屏幕接收 |

---

### 2.5 杜邦线 母对母

| 项目 | 规格 |
|---|---|
| 类型 | 母对母 1P |
| 长度 | 20cm |
| 颜色 | 彩色 |

**用途**：
- ST-Link V2 连接主板H1调试接口
- 备用连接线

**数量**：4根

> 注：串口屏连接现使用1.25转2.54转接线（序号11）

---

### 2.6 Type-C数据线

| 项目 | 规格 |
|---|---|
| 品牌 | 绿联 |
| 类型 | USB-A to Type-C |
| 规格 | USB 2.0 |
| 长度 | 1米 |

**用途**：连接模块与电脑，用于上位机通讯和参数下载

---

### 2.7 ST-Link V2 下载器

| 项目 | 规格 |
|---|---|
| 品牌 | Risym |
| 型号 | ST-Link V2 |
| 接口 | SWD/JTAG |
| 支持芯片 | STM32全系列 |

**用途**：STM32固件烧录和调试

**接线说明**：

| ST-Link引脚 | 主板引脚 (H1) | 说明 |
|---|---|---|
| SWCLK | SWCLK (PA14) | 时钟线 |
| SWDIO | SWDIO (PA13) | 数据线 |
| GND | GND | 地线 |
| 3.3V | 3.3V (可选) | 供电 |

---

### 2.8 1N4148 二极管

| 项目 | 规格 |
|---|---|
| 型号 | 1N4148 |
| 封装 | DO-35 直插 |
| 类型 | 硅二极管 |
| 正向压降 | 约 0.7V (25℃) |

**用途**：作为临时温度探头，用于室温测试

**说明**：
- 专业超低温探头（如DT-670、DT-470）价格昂贵（¥3000~8000）
- 1N4148是硅二极管，可用于初步功能测试
- 室温下正向压降约0.6-0.7V
- 仅用于验证电路功能，不用于精确温度测量

**数量**：50个

---

### 2.9 鳄鱼夹测试线

| 项目 | 规格 |
|---|---|
| 类型 | 双头鳄鱼夹 |
| 长度 | 50cm |
| 颜色 | 彩色（红黑各1条或混色） |

**用途**：连接1N4148二极管到XH2.54-4P端子线，无需焊接

**使用方法**：
1. 鳄鱼夹一端夹住二极管引脚
2. 另一端夹住端子线裸露导线
3. 注意二极管极性：正极(+) → I+，负极(-) → I-

**数量**：2条

---

### 2.10 DC母座转端子线

| 项目 | 规格 |
|---|---|
| DC母座 | 5.5×2.1mm |
| 端子 | XH2.54-2P (已穿壳) |
| 线材 | 22AWG 红黑双芯 |
| 线长 | 约15~20cm |

**用途**：连接24V开关电源到主板CN14接口

**端子引脚定义（锁扣朝上）**：

| 位置 | 线色 | 信号 |
|---|---|---|
| 1号 (左) | 黑线 | GND (负极) |
| 2号 (右) | 红线 | +24V (正极) |

```
端子方向示意（面向插口，锁扣朝上）：

    ┌─────────┐
    │ 黑   红  │
    │ GND +24V │
    │  1    2  │
    └─────────┘
      左   右
```

**数量**：1条

---

### 2.11 1.25转2.54转接线

| 项目 | 规格 |
|---|---|
| 一端 | 1.25mm 4P端子 |
| 另一端 | 2.54mm杜邦母头 (分离式) |
| 线长 | 20cm |
| 品牌 | 优信电子 |

**用途**：连接主板FPC1接口（1.25mm）到串口屏（2.54mm排针）

**接口转换说明**：
```
主板FPC1 (1.25mm)          转接线              串口屏 (2.54mm)
┌──────────┐         ┌──────────────┐         ┌──────────┐
│ 1.25-4P  │←─1.25端子─│ 1.25转2.54  │─杜邦母头─→│ 2.54排针  │
│  座子    │         │   转接线     │         │   接口   │
└──────────┘         └──────────────┘         └──────────┘
```

**引脚对应（FPC1定义）**：

| FPC1引脚 | 信号 | 对应串口屏 |
|---|---|---|
| 1 | DGND | GND |
| 2 | +5VD | VCC |
| 3 | IO_USART6_RX | TX (屏→主板) |
| 4 | IO_USART6_TX | RX (主板→屏) |

**数量**：1条

---

## 三、接线指南

### 3.1 电源连接

```
┌─────────────┐      ┌─────────────────┐      ┌──────────┐
│ 24V开关电源  │─DC头─→│ DC母座转端子线   │─端子─→│ 主板CN14  │
│  DC24V 2A   │      │ DC5.5×2.1转XH2.54│      │ 24V输入  │
└─────────────┘      └─────────────────┘      └──────────┘
```

**连接步骤**：
1. 将24V电源的DC公头插入DC母座转端子线的母座
2. 将XH2.54-2P端子插入主板CN14接口
3. 上电前确认极性正确（红=+24V，黑=GND）

### 3.2 显示屏连接

```
┌─────────────┐      ┌──────────────┐      ┌─────────────┐
│  3.5寸串口屏 │      │ 1.25转2.54   │      │  主板FPC1   │
│ (2.54mm排针) │←杜邦→│   转接线     │←1.25→│ (1.25mm座)  │
└─────────────┘      └──────────────┘      └─────────────┘
```

**连接步骤**：
1. 将转接线的1.25mm端子插入主板FPC1接口
2. 将转接线的杜邦母头逐一插入串口屏的排针

**引脚对应关系**：

| 转接线颜色 | FPC1引脚 | 信号 | 串口屏引脚 |
|---|---|---|---|
| 线1 | 1 | GND | GND |
| 线2 | 2 | +5V | VCC |
| 线3 | 3 | RX | TX |
| 线4 | 4 | TX | RX |

⚠️ **注意**：TX/RX需要交叉连接（主板TX→屏幕RX，主板RX→屏幕TX）

### 3.3 USB连接

```
电脑USB口 ──Type-C数据线──→ 主板LCM2 (Type-C接口)
```

### 3.4 调试器连接

```
┌──────────────┐                   ┌─────────────┐
│  ST-Link V2  │                   │  主板 H1    │
├──────────────┤    杜邦线         ├─────────────┤
│    SWCLK     │ ←───────────→   │    SWCLK    │
│    SWDIO     │ ←───────────→   │    SWDIO    │
│    GND       │ ←───────────→   │    GND      │
│    3.3V      │ ←───(可选)───→  │    3.3V     │
└──────────────┘                   └─────────────┘
```

### 3.5 测试探头连接（1N4148）

```
┌─────────────────────────────────────────────────────────┐
│                      4线制接法                          │
├─────────────────────────────────────────────────────────┤
│                                                         │
│   XH2.54-4P端子线          鳄鱼夹          1N4148二极管  │
│   ┌──────────┐           ┌─────┐         ┌─────┐      │
│   │  V+ (电压+) │ ←──红色──┤     ├──红色──→│ 正极 │      │
│   │  I+ (电流+) │ ←──黄色──┤     ├──黄色──→│ 正极 │      │
│   │  I- (电流-) │ ←──绿色──┤     ├──绿色──→│ 负极 │      │
│   │  V- (电压-) │ ←──黑色──┤     ├──黑色──→│ 负极 │      │
│   └──────────┘           └─────┘         └─────┘      │
│                                                         │
└─────────────────────────────────────────────────────────┘

简化说明：
- V+和I+ 接二极管正极（有色带的一端为负极，无色带的为正极）
- V-和I- 接二极管负极
```

---

## 四、测试步骤

### 4.1 硬件连接测试

1. **检查电源**
   - 连接24V电源到CN14
   - 检查各路电压是否正常（5V、3.3V）

2. **检查显示屏**
   - 连接杜邦线到显示屏和FPC1
   - 上电后屏幕应显示界面

3. **检查USB通讯**
   - 连接Type-C数据线
   - 电脑应识别出虚拟串口

4. **检查调试接口**
   - 连接ST-Link V2
   - 使用Keil或STM32CubeIDE检测芯片

### 4.2 功能测试

1. **温度测量测试**
   - 连接1N4148二极管作为测试探头
   - 观察屏幕显示电压值
   - 室温下应显示约0.6-0.7V

2. **上位机通讯测试**
   - 打开TempDownloader软件
   - 选择正确的串口
   - 点击"获取设备ID"测试通讯

---

## 五、注意事项

### 5.1 安全注意事项

⚠️ **警告**：
- 24V电源接入前请确认极性正确
- 避免短路，可能损坏主板
- 调试时注意静电防护

### 5.2 连接注意事项

1. **电源极性**：确认24V正负极
2. **串口交叉**：TX接RX，RX接TX
3. **SWD接线**：确认SWCLK、SWDIO对应正确
4. **探头极性**：二极管有极性，注意正负极

### 5.3 测试注意事项

- 1N4148仅用于功能验证，不用于精确测量
- 专业超低温测量需使用DT-670/DT-470等专用探头
- 测试时避免触摸二极管，体温会影响测量

---

## 六、故障排除

| 问题 | 可能原因 | 解决方法 |
|---|---|---|
| 无法上电 | 电源极性反接 | 检查24V正负极 |
| 屏幕不亮 | 接线错误/电源不足 | 检查杜邦线连接 |
| USB无法识别 | 数据线问题/驱动缺失 | 更换数据线/安装驱动 |
| ST-Link连接失败 | 接线错误/芯片损坏 | 检查SWD接线 |
| 无温度显示 | 探头未连接/极性反 | 检查二极管连接 |

---

## 七、后续采购建议

如需进行专业超低温测量，建议采购以下设备：

| 配件 | 型号 | 用途 | 参考价格 |
|---|---|---|---|
| 超低温探头 | DT-670/DT-470 | 专业超低温测量 | ¥3000~8000 |
| 数字多用表 | Fluke 17B+ | 电流校准 | ¥500~800 |
| 液氮杜瓦瓶 | 1L | 低温测试环境 | ¥200~500 |

---

*文档版本：V1.2*
*更新日期：2025年12月18日*
*状态：采购完成（全部11项配件已购齐，核对无误）*

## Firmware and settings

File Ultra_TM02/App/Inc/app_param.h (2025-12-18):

/**
 * @file    app_param.h
 * @brief   参数管理应用层头文件
 * @details 提供参数存储、加载、管理功能
 * @author  Ultra-TM02 开发团队
 * @version V1.0
 * @date    2025-12-18
 */

#ifndef __APP_PARAM_H
#define __APP_PARAM_H

#ifdef __cplusplus
extern "C" {
#endif

/* 包含头文件 ----------------------------------------------------------------*/
#include "main.h"

/* 宏定义 --------------------------------------------------------------------*/

/* 参数魔数 */
#define PARAM_MAGIC             0x544D5032  /* "TMP2" */

/* 参数版本 */
#define PARAM_VERSION           0x0100      /* V1.0 */

/* 默认参数值 */
#define DEFAULT_CURRENT_SOURCE  0           /* 默认10μA */
#define DEFAULT_CURRENT_ADJ_10  0.0f        /* 10μA调整值 */
#define DEFAULT_CURRENT_ADJ_17  0.0f        /* 17μA调整值 */
#define DEFAULT_TEMP_4MA        (-200.0f)   /* 4mA对应温度 */
#define DEFAULT_TEMP_20MA       100.0f      /* 20mA对应温度 */

/* 类型定义 ------------------------------------------------------------------*/

/* 用户参数结构体 */
typedef struct {
    uint32_t magic;             /* 魔数 0x544D5032 ("TMP2") */
    uint16_t version;           /* 参数版本 */
    uint16_t reserved;          /* 保留 */
    uint8_t current_source;     /* 电流源选择 (0:10μA, 1:17μA) */
    uint8_t padding[3];         /* 对齐填充 */
    float current_adj_10uA;     /* 10μA调整值 (μA) */
    float current_adj_17uA;     /* 17μA调整值 (μA) */
    float temp_4mA;             /* 4mA对应温度 (℃) */
    float temp_20mA;            /* 20mA对应温度 (℃) */
    uint16_t crc;               /* CRC16校验 */
    uint16_t padding2;          /* 对齐填充 */
} UserParam_t;

/* 函数声明 ------------------------------------------------------------------*/

/**
 * @brief  参数模块初始化
 * @retval 无
 */
void APP_Param_Init(void);

/**
 * @brief  加载参数
 * @retval 0=成功, -1=失败（使用默认值）
 */
int APP_Param_Load(void);

/**
 * @brief  保存参数
 * @retval 0=成功, -1=失败
 */
int APP_Param_Save(void);

/**
 * @brief  恢复默认参数
 * @retval 无
 */
void APP_Param_SetDefault(void);

/**
 * @brief  获取电流源选择
 * @retval 电流源 (0:10μA, 1:17μA)
 */
uint8_t APP_Param_GetCurrentSource(void);

/**
 * @brief  设置电流源选择
 * @param  src: 电流源 (0:10μA, 1:17μA)
 * @retval 无
 */
void APP_Param_SetCurrentSource(uint8_t src);

/**
 * @brief  获取10μA调整值
 * @retval 调整值 (μA)
 */
float APP_Param_GetCurrentAdj10(void);

/**
 * @brief  设置10μA调整值
 * @param  adj: 调整值 (μA)
 * @retval 无
 */
void APP_Param_SetCurrentAdj10(float adj);

/**
 * @brief  获取17μA调整值
 * @retval 调整值 (μA)
 */
float APP_Param_GetCurrentAdj17(void);

/**
 * @brief  设置17μA调整值
 * @param  adj: 调整值 (μA)
 * @retval 无
 */
void APP_Param_SetCurrentAdj17(float adj);

/**
 * @brief  获取4mA对应温度
 * @retval 温度值 (℃)
 */
float APP_Param_Get4mATemp(void);

/**
 * @brief  设置4mA对应温度
 * @param  temp: 温度值 (℃)
 * @retval 无
 */
void APP_Param_Set4mATemp(float temp);

/**
 * @brief  获取20mA对应温度
 * @retval 温度值 (℃)
 */
float APP_Param_Get20mATemp(void);

/**
 * @brief  设置20mA对应温度
 * @param  temp: 温度值 (℃)
 * @retval 无
 */
void APP_Param_Set20mATemp(float temp);

/**
 * @brief  获取参数结构体指针
 * @retval 参数结构体指针
 */
UserParam_t* APP_Param_GetStruct(void);

#ifdef __cplusplus
}
#endif

#endif /* __APP_PARAM_H */

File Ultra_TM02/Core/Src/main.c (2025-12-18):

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

/* Includes ------------------------------------------------------------------*/
#include "main.h"
#include "spi.h"
#include "usart.h"
#include "usb_device.h"
#include "gpio.h"

/* USER CODE BEGIN Includes */
/* BSP层头文件 */
#include "bsp_gpio.h"
#include "bsp_spi.h"
#include "bsp_uart.h"
#include "bsp_flash.h"

/* Service层头文件 */
#include "svc_adc.h"
#include "svc_dac.h"
#include "svc_lcd.h"
#include "svc_usb.h"

/* App层头文件 */
#include "app_temp.h"
#include "app_param.h"
#include "app_comm.h"
#include "app_output.h"
/* USER CODE END Includes */


/* USER CODE BEGIN PV */
static uint32_t led_tick = 0;       /* LED闪烁计时 */
/* USER CODE END PV */

void SystemClock_Config(void);
/* USER CODE BEGIN PFP */
static void App_Init(void);
static void App_Process(void);
/* USER CODE END PFP */

/* USER CODE BEGIN 0 */
/**
 * @brief  应用层初始化
 */
static void App_Init(void)
{
    /* BSP层初始化 */
    BSP_GPIO_Init();        /* GPIO初始化 (片选、LED等) */
    
    /* Service层初始化 */
    SVC_ADC_Init();         /* ADC服务初始化 */
    SVC_DAC_Init();         /* DAC服务初始化 */
    SVC_LCD_Init();         /* LCD服务初始化 */
    SVC_USB_Init();         /* USB服务初始化 */
    
    /* 显示启动信息 */
    SVC_LCD_SetStatus("Starting...");
    HAL_Delay(500);
    
    /* App层初始化 */
    APP_Param_Init();       /* 参数管理初始化 (从Flash加载参数) */
    APP_Temp_Init();        /* 温度测量初始化 */
    APP_Output_Init();      /* 4-20mA输出初始化 */
    APP_Comm_Init();        /* 通讯协议初始化 */
    
    /* 启动完成，更新显示 */
    SVC_LCD_SetStatus("Ready");
    SVC_LCD_SetCurrentSource(APP_Param_GetCurrentSource());
    
    /* 自动开始测量 */
    APP_Temp_Start();
}

/**
 * @brief  应用层主循环处理
 */
static void App_Process(void)
{
    /* 温度测量处理 */
    APP_Temp_Process();
    
    /* 通讯协议处理 (USB接收) */
    APP_Comm_Process();
    
    /* LCD显示更新 */
    SVC_LCD_Update();
    
    /* LED闪烁 (1Hz) - 指示系统运行 */
    if (HAL_GetTick() - led_tick >= 500)
    {
        led_tick = HAL_GetTick();
        BSP_LED_Toggle();
    }
    
    /* 4-20mA输出更新 (如果测量正在运行) */
    if (APP_Temp_IsRunning())
    {
        APP_Output_UpdateCurrent(APP_Temp_GetValue());
    }
}
/* USER CODE END 0 */

/**
  * @brief  The application entry point.
  * @retval int
  */
int main(void)
{
  /* MCU Configuration--------------------------------------------------------*/

  /* Reset of all peripherals, Initializes the Flash interface and the Systick. */
  HAL_Init();

  /* Configure the system clock */
  SystemClock_Config();

  /* Initialize all configured peripherals */
  MX_GPIO_Init();
  MX_SPI1_Init();
  MX_USART6_UART_Init();
  MX_USB_DEVICE_Init();
  /* USER CODE BEGIN 2 */
  /* 应用层初始化 */
  App_Init();
  /* USER CODE END 2 */

  /* Infinite loop */
  /* USER CODE BEGIN WHILE */
  while (1)
  {
    /* 应用层主循环处理 */
    App_Process();
    /* USER CODE END WHILE */

    /* USER CODE BEGIN 3 */
  }
  /* USER CODE END 3 */
}

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


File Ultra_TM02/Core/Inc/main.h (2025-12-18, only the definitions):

#define FIRMWARE_VERSION        "V1.0"
#define FIRMWARE_DATE           "2025-12-18"
#define PRODUCT_NAME            "Ultra-TM02"
#define ADC_DRDY_Pin GPIO_PIN_0
#define ADC_DRDY_GPIO_Port GPIOA
#define ADC_DRDY_EXTI_IRQn EXTI0_IRQn
#define ADC1_CS_Pin GPIO_PIN_4
#define ADC1_CS_GPIO_Port GPIOA
#define DAC1_CS_Pin GPIO_PIN_8
#define DAC1_CS_GPIO_Port GPIOA
#define DAC2_CS_Pin GPIO_PIN_9
#define DAC2_CS_GPIO_Port GPIOA
#define DAC1_LOAD_Pin GPIO_PIN_10
#define DAC1_LOAD_GPIO_Port GPIOA
#define DAC2_LOAD_Pin GPIO_PIN_0
#define DAC2_LOAD_GPIO_Port GPIOB
#define LED1_Pin GPIO_PIN_13
#define LED1_GPIO_Port GPIOC

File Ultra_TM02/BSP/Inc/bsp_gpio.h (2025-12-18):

/**
 * @file    bsp_gpio.h
 * @brief   GPIO板级支持包头文件
 * @details 提供ADC/DAC片选、LOAD信号、LED控制等GPIO操作接口
 * @author  Ultra-TM02 开发团队
 * @version V1.0
 * @date    2025-12-18
 */

#ifndef __BSP_GPIO_H
#define __BSP_GPIO_H

#ifdef __cplusplus
extern "C" {
#endif

/* 包含头文件 ----------------------------------------------------------------*/
#include "main.h"

/* 宏定义 --------------------------------------------------------------------*/

/**
 * 引脚定义说明：
 * 以下宏使用main.h中CubeIDE生成的引脚定义
 * 如果main.h中没有定义，则使用备用定义
 */

/* ADC1片选引脚定义 (PA4) */
#ifndef ADC1_CS_Pin
#define ADC1_CS_Pin         GPIO_PIN_4
#define ADC1_CS_GPIO_Port   GPIOA
#endif

/* DAC1片选引脚定义 (PA8) */
#ifndef DAC1_CS_Pin
#define DAC1_CS_Pin         GPIO_PIN_8
#define DAC1_CS_GPIO_Port   GPIOA
#endif

/* DAC2片选引脚定义 (PA9) */
#ifndef DAC2_CS_Pin
#define DAC2_CS_Pin         GPIO_PIN_9
#define DAC2_CS_GPIO_Port   GPIOA
#endif

/* DAC1加载信号引脚定义 (PA10) */
#ifndef DAC1_LOAD_Pin
#define DAC1_LOAD_Pin       GPIO_PIN_10
#define DAC1_LOAD_GPIO_Port GPIOA
#endif

/* DAC2加载信号引脚定义 (PB0) */
#ifndef DAC2_LOAD_Pin
#define DAC2_LOAD_Pin       GPIO_PIN_0
#define DAC2_LOAD_GPIO_Port GPIOB
#endif

/* LED1引脚定义 (PC13) */
#ifndef LED1_Pin
#define LED1_Pin            GPIO_PIN_13
#define LED1_GPIO_Port      GPIOC
#endif

/* ADC数据就绪引脚定义 (PA0) - 外部中断输入 */
#ifndef ADC_DRDY_Pin
#define ADC_DRDY_Pin        GPIO_PIN_0
#define ADC_DRDY_GPIO_Port  GPIOA
#endif

/* 函数声明 ------------------------------------------------------------------*/

/**
 * @brief  GPIO初始化
 * @note   初始化所有控制引脚，设置默认状态
 * @retval 无
 */
void BSP_GPIO_Init(void);

/**
 * @brief  设置ADC1片选信号
 * @param  state: 0=选中(低电平), 1=取消选中(高电平)
 * @retval 无
 */
void BSP_ADC_CS(uint8_t state);

/**
 * @brief  设置DAC1片选信号
 * @param  state: 0=选中(低电平), 1=取消选中(高电平)
 * @retval 无
 */
void BSP_DAC1_CS(uint8_t state);

/**
 * @brief  设置DAC2片选信号
 * @param  state: 0=选中(低电平), 1=取消选中(高电平)
 * @retval 无
 */
void BSP_DAC2_CS(uint8_t state);

/**
 * @brief  设置DAC1加载信号
 * @param  state: 0=低电平(触发加载), 1=高电平(正常)
 * @retval 无
 */
void BSP_DAC1_LOAD(uint8_t state);

/**
 * @brief  设置DAC2加载信号
 * @param  state: 0=低电平(触发加载), 1=高电平(正常)
 * @retval 无
 */
void BSP_DAC2_LOAD(uint8_t state);

/**
 * @brief  LED1控制
 * @param  state: 0=灭(高电平), 1=亮(低电平)
 * @note   LED为低电平点亮
 * @retval 无
 */
void BSP_LED_Set(uint8_t state);

/**
 * @brief  LED1翻转
 * @retval 无
 */
void BSP_LED_Toggle(void);

/**
 * @brief  读取ADC数据就绪状态
 * @retval 1=数据就绪(低电平), 0=未就绪(高电平)
 */
uint8_t BSP_ADC_IsDataReady(void);

#ifdef __cplusplus
}
#endif

#endif /* __BSP_GPIO_H */

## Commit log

2025-12-18 初始提交：Ultra-TM02 超低温温度测量模块项目 v1.0
    - 添加 STM32固件源码 (App/Service/BSP分层架构)
    - 添加 上位机软件 (Python/PyQt5)
    - 添加 PCB Gerber文件和原理图
    - 添加 软件开发设计文档
    - 添加 硬件设计文档
    - 添加 配件采购清单
    [Drill_PTH_Through.DRL, Drill_PTH_Through_Via.DRL, Gerber_BoardOutlineLayer.GKO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]
2025-12-18 更新.gitignore: 添加敏感信息保护
